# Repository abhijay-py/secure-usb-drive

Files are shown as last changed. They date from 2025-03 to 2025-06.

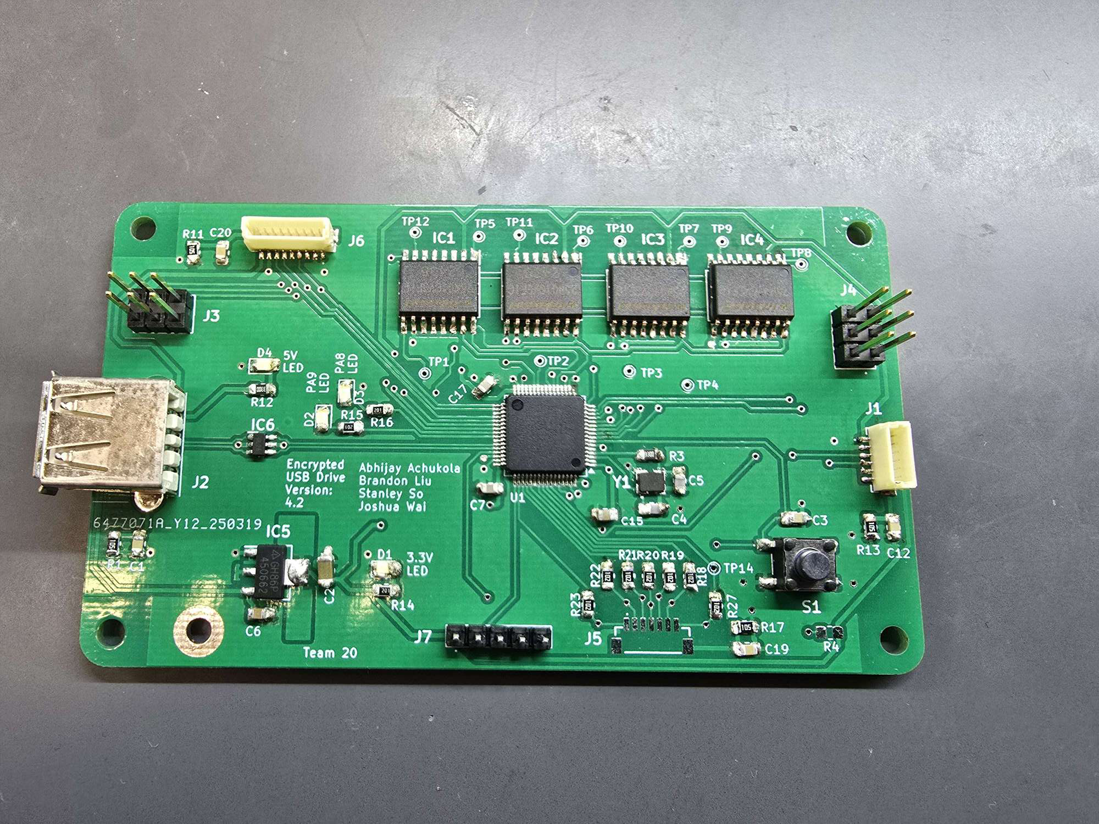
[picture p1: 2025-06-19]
Images/final_usb_pcb.jpg

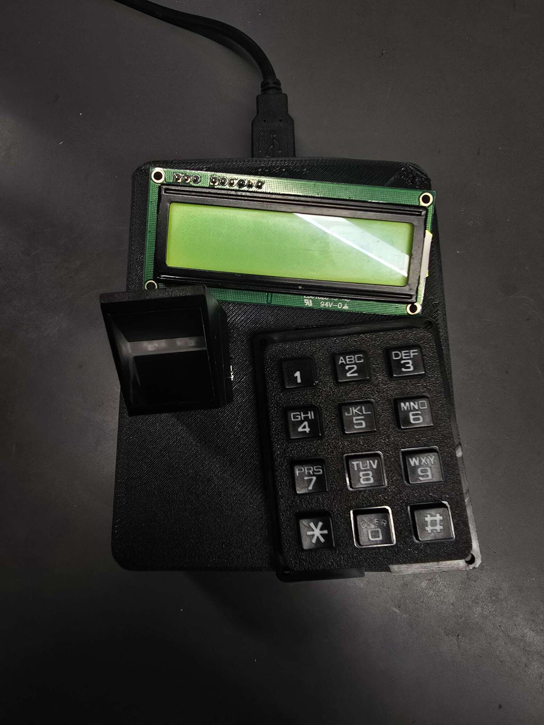
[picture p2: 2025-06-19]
Images/secure_usb_drive.jpg

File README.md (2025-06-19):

# secure-usb-drive
Our device has a fixed number of four users. When the user enters the correct password on the keypad or enters the correct fingerprint, they get to access the files corresponding to their user. <br>

Initially, all the users’ passwords are four zeros. When the user plugs in the USB drive, the LCD screen says, "Select User" and they must enter a number on the keypad to select the user (1 for user one, 2 for user two, 3 for user three, and 4 for user four). Then the LCD screen shows “Enter Passcode / Fingerprint” and the screen displays what the user types on the keypad. As the user types, their input is replaced with a dot. Once the user enters the correct passcode or inputs the correct fingerprint, the USB drive goes into the unlocked state where all the files for that user can be accessed. Each user gets their own designated flash chip. In the unlocked state, the user can press a button on the keypad to change the passcode or change the fingerprint and can press another button to lock the USB drive.<br>

The system is implemented using an STM32 microcontroller. It handles interfacing with the keypad, LCD screen, fingerprint sensor, four flash chips, and a host computer. It also handles keeping track of what state it’s in and handles keeping track of what user is accessing the flash drive. The system is powered through the 5V USB signal that is interfaced with the 5V USB-A female connector. According to the USB 2.0 specifications, it can handle an input voltage ranging from 4.75V to 5.25V. This input voltage directly powers the LCD screen. There is a low dropout regulator to step down the voltage to 3.3V to power the microcontroller, fingerprint sensor, and the flash chips.The system is enclosed in a 3D-printed rectangular case. Since the user must press down on the USB drive to enter a password, it can be connected to a computer using a cable instead of directly into a computer. <br>

All documentation, PCB, schematic, CAD, and software files can be found in their respective folders. <br>

The embedded code can be flashed onto the product by utilizing STM32CubeIDE and connecting an ST-Link and the five header pins on the PCB. The PCB is attached to the casing utilizing two screws on the inside and the casing is closed up with four screws. The connectors on the board will need to be attached to the LCD, fingerprint sensor, and keypad from the outside of the casing after feeding the connecting wires through the holes on the casing. <br><br>
Device Image <br><br>

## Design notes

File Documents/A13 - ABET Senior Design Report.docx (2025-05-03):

## Purdue ECE Senior Design Semester Report

## (Team Section)

Course Number and Title | ECE 47700 Digital Systems Senior Design Project
Semester / Year | Spring 2025
Advisors | Phil Walter
Team Number | 20
Project Title | Encrypted USB Drive

##### Senior Design Students – Team Composition

Name | Major | Area(s) of Expertise Utilized in Project | Expected Graduation Date
Brandon Liu | CompE | Software, PCB Design, Soldering, Wire Crimping | May 2025
Abhijay Achukola | CompE | Software, PCB Design, Soldering | May 2025
Joshua Wai | CompE | Mechanical, Software | May 2025
Stanley So | ElecE | Software, PCB Design, Soldering, Wire Crimping | December 2025

Project Description: Provide a brief (2-3 page) technical description of the design project, as outlined below:

(a) Provide a general description of the product to be delivered by this design project.

## The product has a fixed number of 4 users. When the user enters the correct password on the keypad or enters the correct fingerprint, they get to access the files corresponding to their user.

Initially, all the users’ passwords are four 0s. When the user plugs in the USB drive, the LCD screen says, "Select User" and they must enter a number on the keypad to select the user (1 for user 1, 2 for user 2, 3 for user 3, and 4 for user 4). Then the LCD screen shows “Enter Passcode / Fingerprint” and the screen displays what the user types on the keypad. As the user types, their input is replaced with a dot. Once the user enters the correct passcode or inputs the correct fingerprint, the USB drive goes into the unlocked state where all the files for that user can be accessed. Each user gets their own designated flash chip. In the unlocked state, the user can press a button on the keypad to change the passcode or change the fingerprint and can press another button to lock the USB drive.

## The system is implemented using an STM32 microcontroller. It handles interfacing with the keypad, LCD screen, fingerprint sensor, four flash chips, and a host computer. It also handles keeping track of what state it’s in and handles keeping track of what user is accessing the flash drive.

The system is powered through the 5V USB signal that is interfaced with the 5V USB-A female connector. According to the USB 2.0 specifications, it can handle an input voltage ranging from 4.75V to 5.25V. This input voltage directly powers the LCD screen. There is a low dropout regulator to step down the voltage to 3.3V to power the microcontroller, fingerprint sensor, and the flash chips.

## The system is enclosed in a 3D-printed rectangular case. Since the user must press down on the USB drive to enter a password, it can be connected to a computer using a cable instead of directly into a computer.

(b) What is the purpose of this product? For whom is it intended?

The purpose of this product is to have an encrypted USB drive that provides the end-user with the ability to store data secured by their fingerprint and password while keeping costs as low as possible; a great additional feature includes segmented memory such that different users using the same USB drive can only access certain files depending on their credentials via passwords, ID etc. The drive should provide an extra layer of security for access to user data. The intended audience for this product includes people who want to keep their data private. It can be bought by companies to be used by employees who want to transfer information via the drive, even if there is other sensitive data on there not yet erased, or even interest anyone involved in government or the military. The multiple users feature is great for companies that have workers on different shifts. These companies can buy one USB drive for different workers on different shifts to share, and that can save costs.

(c) Describe how the engineering design process used to create your product was utilized in this project. Include how you were able to develop and conduct appropriate experiments, analyze and interpret data, and use engineering judgment to draw conclusions related to the development of your product.

The main engineering design process used to create this product began with defining the problem and solution. The first task completed came up with a problem to be solved which ultimately led to the decision to develop an encrypted USB drive to solve the issue of data security. The next step was planning. This included looking at specifications of parts to meet goals and functionalities that the solution seeks to provide and then prototyping each part before making a PCB design and systematically integrating everything into one device (PCB connected to external components). There was lots of testing to debug issues not found in initial prototyping such as bridging the connection between USB host and flash memory.

(d) Describe the design constraints, and resulting specifications, incorporated into your product (list a minimum of 3).

## Constraint: at least 100kB/s speed for reading / writing files between the computer and the flash drive.

## Specification: A microcontroller with USB built in was selected and USB 2.0 high-speed was used.

## Constraint: at least 1Gb of memory for each user, and a total of four users.

## Specification: Our PCB has four 1Gb flash chips, all communicating over the same SPI bus. We used the CS pin to select which flash chip we’re using based on what user is selected.

## Constraint: We need to be able to communicate using one UART bus, two SPI buses, seven GPIO pins, and one USB bus. These will communicate with the fingerprint sensor, the four flash ICs, the LCD display, the keypad, and the host computer, respectively.

## Specification: We chose the STM32H7A3RGT6 microcontroller because it had enough peripherals and enough pins to handle all the communication.

Constraint: We need to power the microcontroller, fingerprint sensor, and flash ICs using 3.3V and be able to supply up to 500mA. Our device also needs to be powered by the USB 5V.
Specification: We chose the AZ1117IH-3.3TRG1 LDO, since that could supply 3.3V from 5V, and provide up to 1A of current.

(e) Describe how each of the following factors influenced your design specifications and constraints.

Public Health, Safety, and Welfare: One potential issue we considered was the risk associated with USB male-to-male connections and the possibility of electric shocks. However, the primary concern was the potential for users to accidentally damage the board due to static discharge from human contact. To mitigate this risk, we incorporated ESD diodes for the USB-A port, keypad, and fingerprint sensor. We also made a case out of insulating material to protect the electronics and user. Other than that, no significant risks were identified.

Global Factors: Global factors didn’t play a significant role in this project, as it wasn’t specifically designed for any particular global market or to address geopolitical issues. However, we did consider the general global trend toward increased data security and privacy concerns, especially with rising cyber threats. This influenced our decision to implement strong and secure authentication features, such as fingerprint recognition and password protection, ensuring that the product would meet global expectations for secure data storage. We were not able to include all the languages for our UI so the understanding of English would be necessary for users to use our product, but choosing English as the language is useful, as it is the most widely known language and can make it accessible for the most people.

Cultural Factors: Different cultures might also have varying preferences when it comes to things like the user interface, some might prefer simple, clean designs, while others may want more detailed instructions or support in multiple languages. With this in mind, we tried to make our design as simple and easy to use as possible. Unfortunately, we were not able to implement other languages other than English due to the LCD. However, as English is the most well-known language in the world, our product should have enough reach to be understood by most individuals. In areas with a higher risk of cyber threats, users might expect stronger security, like multi-factor authentication or biometric features, which is why we utilize two forms of authentication, password and fingerprint access.

Social Factors: This product would affect the social environment of corporations, allowing for easier collaboration and teamwork, with multiple people using the same drive. It’ll also allow for a more secure work environment with the data stored on the USB drives not being able to be stolen easily by malicious actors who also have access to it. This also prevents data being unintentionally shared with other unassuming users of USB drives.

Environmental Factors: We were under the assumption that the product will not be used in extreme heat or cold, and it will not be used in an external environment where there is precipitation, so we have the freedom to select any components that could operate at the normal temperature of our lab, and did not have to consider waterproofing. PCBs and LCDs require hazardous chemicals and a significant amount of energy to manufacture. They also require a significant amount of energy to recycle, because they need to be smelted to recover metals. Because of these reasons, we chose the smallest LCD that could display our UI, designed our PCB to be as small as possible, and chose the smallest keypad that had enough buttons to easily navigate our UI.

Economic Factors: The design in question aims not to be much more expensive compared to products already on the market. We did this by choosing the cheapest fingerprint sensor that could store 4 users, choosing the cheapest keypad that had enough buttons to navigate our UI, and choosing the cheapest LCD display that could display our UI. We also added a feature where four users could use one flash drive, so companies can buy one flash drive for four different employees, given that they won’t all be using it at the same time. This might happen if the company has employees on different shifts.

(f) Describe the appropriate engineering standards incorporated into the creation of your product.  The main standards used in this project are the communication protocols implemented to interface external components with the microcontroller including USB 2.0, SPI, and UART. Other followed conventions include using IEEE 1185 standard ESD protection for components that may interact with human input as well as other rules set for PCB design involving ERC and JLC PCB dimension constraints.
(g) Describe the final status of your product.

The product can transition between user select, receiving password, unlock, change fingerprint/pin, and locking states via the keypad input. While this functionality also works with the fingerprint sensor, it does not work the same within the packaging, making the functionality irrelevant in this context. The product can display the states transitioning and provide information upon what input to provide to the product to change states and access data using the LCD as a heads-up display (HUD). The product can interface with a host computer over USB and connect to the computer upon transition into the unlocked state and remove the device from the device list of the computer upon locking. In the unlocked state, the product can display the data stored in the flash IC corresponding to the user in the computer via USB.

(h) Describe the makeup of your project team and how you were organized to establish goals, plan tasks, and meet the objectives of this project.

Although each team member took similar ECE courses prior to the senior design course, there were new tasks that required learning and interest such as soldering, CAD (for casing), and PCB design. Joshua was interested in the mechanical tasks of the project, so he primarily did the CAD. Stanley, Brandon, and Abhijay each prototype approximately 1-2 external devices ie. LCD, fingerprint sensor, flash ICs, and keypad due to their experience in working with these devices. Although Stanley was the most experienced in PCB design, Abhijay took a keen interest in it and therefore was the main contributor to this task. Abhijay often helped set goals, by highlighting the major blockers of the project that needed to be addressed and helped organize meetings. He also got more people to work on the major issues being faced. Each team member worked on tasks based on skillset and interests. These tasks were then individually planned on how to approach them, with input from teammates and check-ins with other teammates to ensure everyone got their tasks done on a timely manner. Near deadlines, the whole team got together to work on the project and aid others in them to meet those deadlines. Around a week before every deadline, Abhijay announced the deadline to ensure that everyone knew and was ready for it.

(i) Did your project require the production of any written documentation other than this document (i.e., manuals, educational materials, etc.)? If so, describe the types, composition, and nature of the audiences for whom these materials were intended.

This project involved the production of several written documents other than this document, including engineering journals and design documents. The engineering journals include the thoughts, progress, and achievements of each team member’s individual work. The engineering journals were mostly for internal use within the team, and tracked each team member's progress, ideas, problems we ran into, and what we achieved throughout the project. These journals were more reflective, helping us keep track of individual contributions and decisions made, and improving communication within the team. The audience for these journals was mainly team members and our teaching assistants and faculty advisors. We were instructed to document our progress in such a way that someone could easily follow along and understand our steps. The design documents include the planning of the various systems of the project including software and hardware, as well as analysis on the comparison between design components. These documents were intended for a wider audience, including our team and external reviewers like faculty advisors or professionals in the field. These documents went over the planning, technical specs, and design choices for both the hardware and software aspects of the project. They were more formal and technical, aiming for clarity so that anyone reading them, whether they were familiar with the project or not, could follow the reasoning behind our design decisions.

(j) Describe the types, composition, and nature of the audiences in attendance for the final oral design review. Discuss how you prepared for this audience.

In the final oral design review, the main audience are student peers and the instructional staff. The student peers are likely interested in seeing the functionality of the design and the process involved since they never conducted weekly check-ins to see the progress of this project throughout the semester. The instructional staff may pose more sophisticated questions as they were involved in seeing how the project progressed over time. To prepare for both audiences, it was key to reflect on the responsibility and achievement of each team member as this is what we will be presenting in addition to the demonstration of the project design.

## Purdue ECE Senior Design Semester Report

## (Individual Reflections Section)

Course Number and Title | ECE 47700 Digital Systems Senior Design Project
Semester / Year | Spring 2025
Advisors | Phil Walter
Team Number | 20
Project Title | Encrypted USB Drive

##### Senior Design Student Completing This Section

Name | Major | Area(s) of Expertise Utilized in Project | Expected Graduation Date
Brandon Liu | Computer Engineering | Software, PCB Design, Soldering, Wire Crimping | May 2025

Individual Reflection: Provide a brief (1-2 page) individual reflection of the design project, as outlined below:

(a) Describe your personal contributions to the project.

In software, my main contributions include prototyping the LCD, prototyping read JEDEC ID for the flash IC, setting up USB interface between host computer and the microcontroller, and storing user ID and password credentials in the MCU flash using C programming on the STM32CubeIDE. For PCB design related tasks, my contributions include routing the PCB layout and adding ESD protection to both the schematic and the PCB layout. I’ve also crimped wires & soldered wires together to establish connections between external components and the PCB which has a bunch of components that I soldered on including but not limited to the MCU, flash ICs, connectors, diodes etc.

(b) Describe how your contributions to this project built on the knowledge and skills you acquired in earlier course work.

During my work in prototyping the LCD using SPI, one command of the flash IC using SPI, USB interface setup, and storing user ID and password credentials in the MCU flash using the C programming language, my skills in accomplishing these tasks can be derived from ECE 36200 and ECE 43700. In ECE 36200, I learned to work with GPIOs, communicate with external devices using SPI and UART, configure interrupts, and more importantly, read datasheets for things I’m not familiar with which is what I did when working with a different type of LCD than one used in ECE 36200 and prototyping USB. In ECE 43700, I learned the concept of storing both program instructions and data in memory and reference them via addressing which helped me figure out how to best store user ID and password credentials.

(c) Describe how you acquired and applied new knowledge as needed to contribute to this project. What learning strategies did you employ to do so?

Prior to soldering the microcontroller, flash chips, resistors, diodes, capacitors, connectors, and wires, I only had experience soldering wires. I have never done anything with other kinds of components before, so I knew that I had to learn from people who have accomplished these tasks already. Luckily, the ECE 47700 course staff provided a workshop for how to solder, so after attending the workshop, I was able to solder the components listed above. As for routing the PCB and adding components to the layout, I have never really worked with KiCad before, and since this skill was to be self-learned, I watched YouTube tutorials that guided me step by step on the same KiCad version that I was using. After watching the videos, I was able to route the wires between the connectors and the microcontroller in one of the revisions, and learn how to add ESD circuitry by first adding them to the schematic file and then automatically update their presence in the PCB file which I later had to route as well.

(d) Discuss your ethical and professional responsibilities as they relate to this engineering design experience.

My ethical responsibilities involve being honest about my progress and what I am struggling with. It is important that other team members know what I have worked on and what I have not completed yet, so they have full transparency on other aspects of the project that they are not working on. My professional responsibilities primarily consist of following conventions for updating parts of a project shared and accessed by multiple members including but not limited to version control.

(e) Consider what the impact of the product of this engineering design experience could have in economic, environmental, societal, and global contexts. Discuss how you would make (or did make) an informed judgement as to your product’s impact in each of these four contexts?

Regarding the societal and global contexts, I would consider mainly privacy, data protection, and spy / intelligence networks run by government / military institutions. It can be determined that the secure USB drive has a huge impact in these areas because it prevents any user from simply plugging in the drive into their computer and accessing the data. There is a layer of authentication that must be breached in order to unlock access to the USB. This protects users in case they leave their drive lying around as well as people conducting military operations around the world because there is impedance to the data access. For the product’s impact in the environmental context, I would only think about what the product uses or releases, and since it does not release any substances to the environment, I would determine that the only environmental impact is electricity usage. As for economic impact, I would judge the product’s impact in this category by viewing its competitiveness against other products. I can determine that this product has one by being a competing product in the marketplace if and only if the product was smaller in size, had stronger wire connections, and provided more storage space. This is because most flash drives can store many gigabytes of data, while the current engineering design can only store a single gigabit per user, which is not ideal. In addition, the size of the design is bulky due to the requirement of holding a keypad, fingerprint sensor, and an LCD. If the design along with these external components were smaller, it would be more portable and competitive in the market. Otherwise, despite the potential to encrypt data and the ability to require authentication before accessing data, the product is on the lower end of meeting consumer needs and will therefore have difficulty in maintaining its standing in the USB drive market.

## Purdue ECE Senior Design Semester Report

## (Individual Reflections Section)

Course Number and Title | ECE 47700 Digital Systems Senior Design Project
Semester / Year | Spring 2025
Advisors | Phil Walter
Team Number | 20
Project Title | Encrypted USB Drive

##### Senior Design Student Completing This Section

Name | Major | Area(s) of Expertise Utilized in Project | Expected Graduation Date
Stanley So | Electrical Engineering | Software, PCB Design, Soldering, Wire Crimping | December 2025

Individual Reflection: Provide a brief (1-2 page) individual reflection of the design project, as outlined below:

(a) Describe your personal contributions to the project.

I wrote the code for the keypad by using a timer interrupt to poll each row using GPIO. I interfaced with the fingerprint sensor using UART. I made adjustments to the PCB design. I ordered all the parts for the project (PCB, on-board components, and off-board connectors). I soldered some of the components to the board, including the heartbeat LEDs, the female USB-A connector, the LDO, the reset switch, and various resistors and capacitors. I taught myself how to crimp wires, and I taught my teammates how to do the same thing. I turned Brandon’s state machine pseudocode into production code.

(b) Describe how your contributions to this project built on the knowledge and skills you acquired in earlier course work.

ECE 362 taught me how most of the protocols used in this project worked (SPI, UART). Because of this, I knew what connections to make, what pins to debug with an oscilloscope, and how to translate the raw oscilloscope input into digital data. ECE 2k7 and 2k8 taught me how to use special oscilloscope functions (trigger, different horizontal modes), which helped in finding the data that I actually wanted to read. ECE 264 helped familiarize me with C syntax and how to use a debugger. This made writing code really fast and debugging a lot easier, since I could step through any individual instructions and see how the variables changed as I stepped through.

(c) Describe how you acquired and applied new knowledge as needed to contribute to this project. What learning strategies did you employ to do so?

My PCB design experience comes from a personal project where I made programmable diabolo (juggling prop) lights. I had to design a PCB in EasyEDA in order to make it structurally sound enough to be put on a spinning diabolo. This PCB design experience helped me make component placement and routing changes to the PCB very quickly. My soldering experience came from another personal project where I designed a drone, so I had to solder a lot of components together using wires. This made soldering together the two ends of the connector wires quick. Since we had to solder components onto a PCB for this project, I also had to watch YouTube videos on how to solder surface mount components. This allowed us to come up with a two-person system to solder components quickly, where one person managed the soldering iron and the solder, and another person managed the tweezers to put the component in place. I learned how to crimp terminals after watching YouTube videos for this project. This made it so then I knew what parts to order (both housing and crimp terminal), I knew how to make some connectors, and I knew how to teach Brandon how to also make connectors. I also learned how to use the oscilloscope to read serial data by watching YouTube videos. This made debugging UART data from the fingerprint sensor so much faster, since I didn’t have to manually decode the oscilloscope reading into digital data myself.

(d) Discuss your ethical and professional responsibilities as they relate to this engineering design experience.

Whenever I saw that something needed to be done, I would jump in and take care of it (everything in part A was something I volunteered to help for). At the very least, I always tried my best to be there when someone else was working. There are some unlogged hours missing from my journal where I’m just there for mental support, and ready to help with any small tasks that I could (they’re missing from my journal because I don’t know how to log those hours without points being deducted for not describing enough). I always tried my best to communicate with my teammates on Discord (about progress and also about my schedule), and I made sure I received all notifications from that Discord server so I could constantly be aware of what needed to be done.

My ethical responsibilities included being honest and transparent about my work progress and my availability. This let my teammates know what needed to be done. I also followed all the lab rules, including not taking anything from anybody else’s lab station, and always having at least 2 people in the lab. Taking something from someone else’s lab station can lead to confusion, and in the worst case component damage, and having at least 2 people in lab meant that there was always someone else there if somebody got hurt.

(e) Consider what the impact of the product of this engineering design experience could have in economic, environmental, societal, and global contexts. Discuss how you would make (or did make) an informed judgement as to your product’s impact in each of these four contexts?

(If we polished our product more), some societal and global impacts this product might have are that this might be used by companies to protect their data, leading to more secure data storage since you have to physically get your hands on it to break into it. This might also be used by criminals to hide their data and communicate, like how mass criminal networks have used encrypted phones, but this is much less of a concern than encrypted phones because it has no internet access. If we added internet access, our project would become another encrypted phone, leading to really big ethical concerns regarding criminals using it. Like many electronic products, this product has environmental impacts on both the manufacturing and disposal stage. Every single component (PCB, ICs, LCD display) uses hazardous chemicals in the manufacturing process, along with a lot of energy. During the disposal stage, you have to smelt the electronics to get the metals back, which is more energy usage. To account for this, we made the PCB as small as possible and chose the smallest possible components that met our requirements. In terms of economic impact, we might be able to sell this to a lot of big companies that want to secure their data. Our project is probably not lower priced than the other secure USB drives out there, and it’s definitely not as small as other competitors. However, our project has a UI and a fingerprint sensor, which provides new users with an easier learning curve, and makes our product more convenient to unlock. Thus, our main selling point is that our project provides a more convenient alternative to existing competitors.

## Purdue ECE Senior Design Semester Report

## (Individual Reflections Section)

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

##### Senior Design Student Completing This Section

Name | Major | Area(s) of Expertise Utilized in Project | Expected Graduation Date
Abhijay Achukola | CMPE | Software, PCB Design, Soldering | May 2025

Individual Reflection: Provide a brief (1-2 page) individual reflection of the design project, as outlined below:

(a) Describe your personal contributions to the project.

I researched which flash IC to utilize, read through the data sheet, and implemented software interfacing with the flash IC from the microcontroller over SPI. I also designed most of the PCB Design and kept the schematic up to date with our updates prior to starting the PCB design. I also helped solder all the parts onto the PCB, helping place parts in place.

(b) Describe how your contributions to this project are built on the knowledge and skills you acquired in earlier coursework.

I was able to utilize the datasheet reading knowledge I gained from prior classes like ECE 20001 to read through datasheets for the flash IC and microcontroller to properly interface them and connect them to the rest of the system properly. It also helped me find the proper way to wire the microcontroller to our PCB and the supporting circuitry from those datasheets. I also was able to utilize the KiCAD and stm32 microcontroller interfacing knowledge from ECE 36200 to create our electrical schematic and properly program the microcontroller to interface with the flash IC.

(c) Describe how you acquired and applied new knowledge as needed to contribute to this project. What learning strategies did you employ to do so?

I acquired the knowledge of how to utilize stm32cube and interfacing with flash ICs by reading through forums and online datasheets on how to utilize it. I also learned more about these topics by trying to apply immediately in the project and then going back to the resources I utilized. I also learned how to design PCBs by listening to senior design lectures and watching videos online. Furthermore, I watched videos to expand my knowledge on how to solder SMD components properly and developed a system with my teammates to effectively solder them quickly. The learning strategies I utilized was to immediately apply the skills the resources I read to check if I fully understand the concepts.

(d) Discuss your ethical and professional responsibilities as they relate to this engineering design experience.

I was in charge with keeping the team organized and ensuring that everyone knew which priorities had to be handled. I also ensured that we met together and ensured that the design process went smoothly, to avoid any malfunctions due to miscommunication. Ethically, I ensured that everyone documented their work, cited their sources, and ensured that I was transparent on my struggles and areas where I needed help.

(e) Consider what the impact of the product of this engineering design experience could have in economic, environmental, societal, and global contexts. Discuss how you would make (or did make) an informed judgement as to your product’s impact in each of these four contexts?

Some economic impacts that this product would have include shaking up the market for storage devices by being able to sell this product to a lot of big companies that want to secure their data. This product might not be as cheap as many other USB drives but should be reasonably priced for hard drives in general, and the higher cost can be justified for the security it provides. Viewing this product with an environmental lens, this product would reduce the e-waste produced using massive number of USB drives as it condenses four users of four separate USB drives into all using our single product. The e-waste produced by electronics has major impact, as electronic components and PCBs utilize harmful chemicals to manufacture each time, so less devices being disposed of results in reduced harm to the environment. This product will have an impact on the social environments of corporations, which also would propagate this impact globally, allowing for easier collaboration and teamwork, with multiple people using the same drive. It’ll also allow for a more secure work environment with the data stored on the USB drives not being able to be stolen easily by malicious actors who also have access to it.

## Purdue ECE Senior Design Semester Report

## (Individual Reflections Section)

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

##### Senior Design Student Completing This Section

Name | Major | Area(s) of Expertise Utilized in Project | Expected Graduation Date
Josh Wai | CompE | Mechanical | May 2025

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

(a) Describe your personal contributions to the project.

I designed the mechanical casing using CAD software to fit the project’s electronics and 3D printed the parts. After receiving feedback from professors, TAs, and teammates, I made adjustments to improve the fit, add space for connectors, and reinforce key areas. I also helped with the assembly, tinning, crimping, cutting, and soldering wires to connect the components to the board. When the fingerprint sensor wasn’t cooperating, I troubleshot the issue by testing connections and making adjustments to get it working. Additionally, I updated the LCD UI by adding text prompts to improve the user experience.

(b) Describe how your contributions to this project built on the knowledge and skills you acquired in earlier course work.

I built on the skills I gained from the 2K7 and 362 labs, where I learned the fundamentals of CAD design, electrical component assembly, and basic troubleshooting techniques. In the 362 lab, I learned about wiring, soldering, and circuit board assembly, which were crucial when working on the connections between the components. Building on these experiences, I was able to improve my understanding of integrating various components into a cohesive system, like when I had to troubleshoot the fingerprint sensor issue. I also applied what I learned about creating user interfaces in embedded systems when I updated the LCD UI with text prompts. This project gave me the chance to take those foundational skills and apply them to a real-world scenario, improving both my technical abilities and my problem-solving approach.

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

I had to learn how to use Onshape, the CAD software, from scratch, as it was my first time working with this tool. To get up to speed, I relied heavily on YouTube tutorials and online resources. I followed step-by-step guides, which helped me understand the interface and key features of Onshape. I focused on learning the basics first—like how to create sketches, extrude parts, and set up assemblies—before moving on to more advanced topics like constraints and part interactions. I also applied a hands-on approach by actively working on the CAD design for the project while referring back to the tutorials whenever I hit a roadblock. This approach of learning by doing was incredibly helpful, as it allowed me to see immediate results from my efforts and helped reinforce what I was learning. I wasn’t afraid to experiment within the software, and if something didn’t work, I’d troubleshoot the issue by watching more targeted videos or exploring community forums for solutions. This active problem-solving mindset, combined with iterative learning, made it easier to adapt to the software and apply it effectively for our project. Through this process, I gained a solid understanding of Onshape, which directly contributed to the successful design of the mechanical casing.

(d) Discuss your ethical and professional responsibilities as they relate to this engineering design experience.

Throughout this project, I made it a priority to be transparent about any problems that arose, recognizing that honesty and clear communication are key to maintaining trust and ensuring the team could effectively address issues as they emerged. Whenever we encountered challenges—whether it was with the mechanical casing design, component connections, or troubleshooting technical problems—I made sure to bring these issues to the attention of the team right away.

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

The encrypted USB drive with user-specific memory banks has broad impacts across economic, environmental, societal, and global contexts. Economically, it meets the demand for secure data storage, offering opportunities for businesses needing high data protection. Societally, it provides affordable data security for individuals and organizations, addressing privacy concerns. Globally, it complies with international data security standards, ensuring relevance in regions facing growing cyber threats.

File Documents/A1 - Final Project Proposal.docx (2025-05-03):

# Final Project Proposal

# Year: 2025 Semester: Spring Team: 20 Project: Encrypted USB Drive

# Creation Date: 1/15/2025 Last Modified: 1/18/2025

# Team Members (#1 is Team Leader):

# Member 1: Abhijay Achukola Email: aachukol@purdue.edu

# Member 2: Brandon Liu Email: liu3394@purdue.edu

# Member 3: Stanley So Email: sos@purdue.edu

# Member 4: Joshua Wai Email: waij@purdue.edu

# 1.0 Project Functional Description:

# We plan to make an encrypted thumb drive. There will be a fixed number of 4 users. There will be an onboard LCD screen, a keypad, and a fingerprint sensor.

Initially on hardware reset, all the users’ passwords are 4 0s. When we plug in the thumb drive, the LCD screen will say "Select User" and we have to enter a number on the keypad to select the user (1 for user 1, 2 for user 2, 3 for user 3, and 4 for user 4). Then the LCD screen will show “Enter Passcode” and the screen will display what the user types on the keypad. The keypad input the LCD screen displays will be replaced with a dot as the numbers get typed. Once the user enters the correct passcode or inputs the correct fingerprint, the thumb drive will go into the unlocked state where all the files for that user can be accessed. In the unlocked state, the user can press a button to change the passcode or change the fingerprint. To lock the thumb drive, you unplug it from the computer. If the user enters the wrong password on the keypad 5 or more times, then the data for that user is erased and the password gets reset to all 0s.

# 2.0 Team Member Expertise and Team Roles and Responsibilities:

# 2.1 Team Member Expertise:

# 2.1.1 Team Member: Abhijay Achukola: Embedded Circuit Design, C Programming, SystemVerilog, Leadership, Soldering.

# 2.1.2 Team Member: Brandon Liu: Python and C Programming (HPE, Garmin), theory of operation & functional design (ECE 362, ECE 337, Garmin)

# 2.1.3 Team Member: Stanley So: SystemVerilog and Embedded C Programming

# 2.1.4 Team Member: Joshua Wai: Python and C programming

# 2.2 Team Roles and Responsibilities:

Role | Team Member
Team Lead | Abhijay Achukola
Systems Lead | Brandon Liu
Hardware Lead | Stanley So
Software Lead | Joshua Wai

# 3.0 Homework Assignment Responsibilities

Design Component Report | | Professional Component Report
A3-Software Overview | Joshua Wai | A9-Legal Analysis | Joshua Wai
A4-Electrical Overview | Stanley So | A10-Reliability and Safety Analysis | Brandon Liu
A6-Mechanical Overview | Abhijay Achukola | A11-Ethical/Environmental Analysis | Stanley So
A8-Software Formalization | Brandon Liu | A12-User Manual | Abhijay Achukola

# 4.0 Estimated Budget

# Total - $100

# PCB – $20

# Sensors/Input - $5

# Display - $10

# ICs - $45

# Microcontroller - $10

# Enclosure - $10

# 5.0 Project Specific Design Requirements

# Hardware PSDR:

# Keypad for password and ID settings

# LCD display user input

# Flash memory for data storage

# Software PSDR:

# ID verification (both password & fingerprint)

# Allocation of memory based on credentials

# Password display management

# 6.0 Sources Cited:

ECE 477: Digital Systems Senior Design Last Modified: 01-18-2025

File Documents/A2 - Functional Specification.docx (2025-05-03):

# Functional Specification

# Year: 2025 Semester: Spring Team: 20 Project: Encrypted USB Drive

# Creation Date: January 25, 2025 Last Modified: January 25, 2025

# Member 1: Abhijay Achukola Email: aachukol@purdue.edu

# Member 2: Brandon Liu Email: liu3394@purdue.edu

# Member 3: Stanley So Email: sos@purdue.edu

# Member 4: Joshua Wai Email: waij@purdue.edu

# Assignment Evaluation: See Rubric on Brightspace Assignment

# 1.0 Functional Description

Encrypted USB Drive is a USB drive with multiple security features that allows different individuals to access separate files from the same device, without allowing others from viewing those files as well. The device is composed of a display that informs the user on how they can select which user they’re trying to log in as, whether log in attempts is successful, and whether the device is unlocked or locked. The user can input either their password or use their fingerprint to gain access to their data, at which point the device can be utilized as a standard USB drive and allows the user to also change their password or fingerprint attached to their profile. These features are also available to up to four separate users.

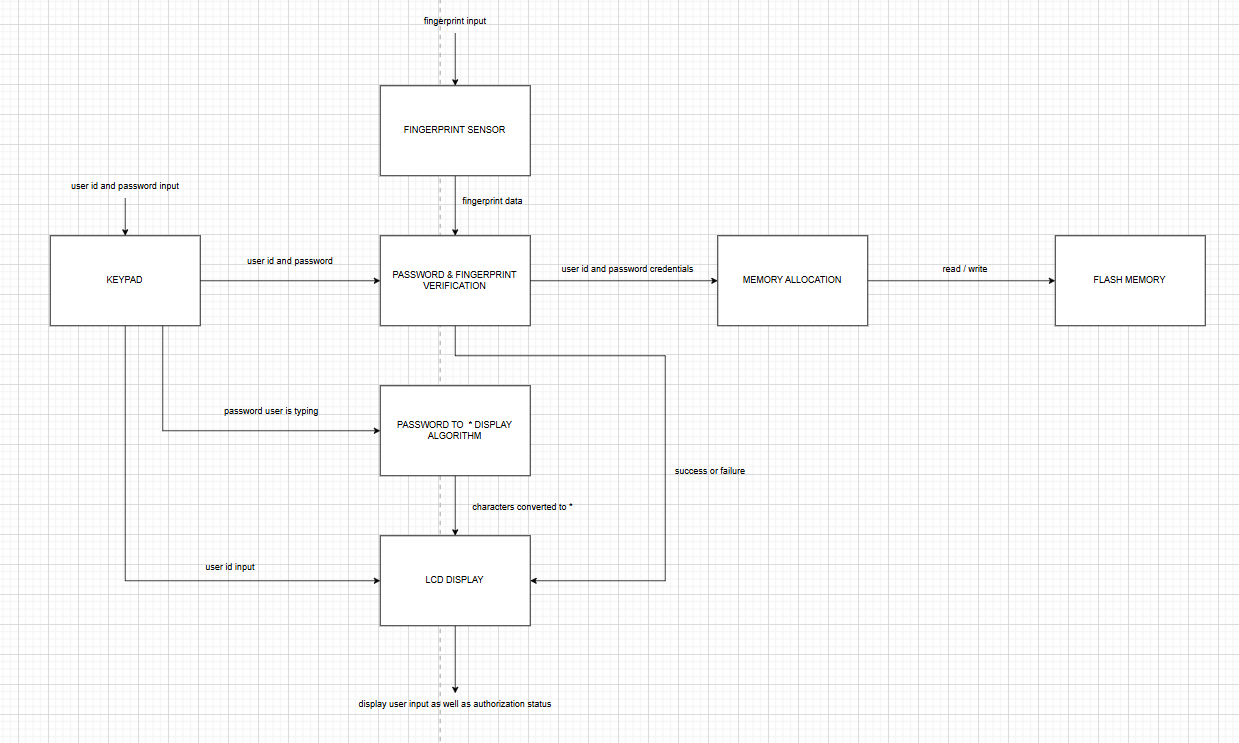
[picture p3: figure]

# 2.0 Theory of Operation

Our fingerprint sensor will go through a lot of states. At the moment, we are thinking about the following states: Startup, User Select, Receiving Password, Unlocked, Change PIN, Change Fingerprint, and Locking. A state transition diagram helps to organize all of these states. It shows each state inside an oval and shows how you can transition between each state with a labeled arrow. The state transition diagram for our device is shown below.

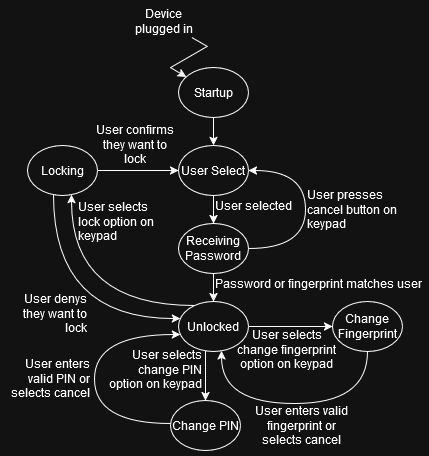
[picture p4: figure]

In the startup state, the GPIO pins are configured to whatever communication protocol they need to do. In the User Select state, the LCD display displays “Select User” and the device waits for the user to press a number on the keypad from 1-4. In the Receiving Password state, The LCD screen will show “Enter Password” and the screen will display what the user types on the keypad. The keypad input the LCD screen displays will be replaced with a dot as the numbers get typed. In the unlocked state, all the files for that user can be accessed.

# 3.0 Expected Usage Case

Our encrypted USB drive is expected to be used as a portable and secure storage device for up to 4 users per device in a preferably dry, indoor environment. It is expected that the user will have a basic level of technical literacy capable of using USB drives, managing passwords, and performing simple file operations. The device is deigned to be used mostly by IT professionals, military or government personnel, business corporations, healthcare institutes, legal professionals, and educational institutes to protect their sensitive data and intellectual property.

# 4.0 Design Constraints

# 4.1 Computational Constraints

To start off, the computational constraints will use a linear scan algorithm to check user id against all known records and then comparing passwords. Additionally, the goal is to have at least 100kB/s speed for reading / writing files between the computer and the flash drive. The microcontroller should be able to allow each user should have at least 4Gb of memory via allocation (no partitioning). However, the fingerprint sensor takes care of storing fingerprints and comparing fingerprints already so the microcontroller doesn’t have to do that.

# 4.2 Electronics Constraints

Our thumb drive will use an STM32 microcontroller to interface with a fingerprint sensor, LCD display, keypad, USB-A host, and flash memory. The fingerprint sensor will communicate using UART. The LCD display will communicate using SPI or I2C. We will interface with the keypad by polling each row and checking the corresponding column. The USB communication will be handled by the onboard peripheral inside the microcontroller itself. The flash memory will communicate using SPI. There will be a 5V to 3.3V regulator to provide power to the microcontroller and whatever peripherals need it. There will also be a crystal to make sure the USB data is transmitted at the correct frequency. There will also be a mosfet so we can turn off power to the fingerprint sensor with a GPIO pin when it’s not needed.

# 4.3 Thermal/Power Constraints

The input voltage from the USB should be between 4.75V and 5.25V. The device should draw less than 500mA from the USB. The maximum operating temperature should be at least 110 degrees Fahrenheit. The minimum operating temperature should be at most 32 degrees Fahrenheit. The device is powered by the USB so there is no battery.

# 4.4 Mechanical Constraints

Our device is intended to be preferably used in a dry, indoor environment where the temperature is room temperature. It should also be able to work outdoors provided the weather is not too extreme and not too wet. We also want to ensure that keypad & fingerprint components do not physically impede the device’s ability to connect to a laptop / computer via USB port. We aim to make the final product pocket-size for portability as well as ensuring the weight stays below one pound. The device will also include a casing to protect our electronics from dust, debris, and spillage. While we do not aim for total waterproofing, we hope to at least prevent simple drops of water from messing up the device through casing.

# 4.5 Economic Constraints

# Maximum budget for the product is $425 without accounting for the inflation rate. However, with the encryption functionality and market analysis, a competitive price shall not exceed $150. Given the market rate, it should cost around $70-$100.

# 4.6 Other Constraints

# 5.0 Sources Cited:

PBW – 23-Jan-2023 Page 2 of 3

ECE 47700: Digital Systems Senior Design Last Modified:

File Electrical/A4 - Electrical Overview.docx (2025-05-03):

# Electrical Overview

# Year: 2025 Semester: Spring Team: 20 Project: Encrypted USB Drive

# Creation Date: 2/8/25 Last Modified: March 7, 2025

# Author: Stanley So Email: sos@purdue.edu

# 1.0 Electrical Overview

The main processing unit will be the 32-bit STM32 microcontroller. This microcontroller will manage communication with a fingerprint sensor, keypad, LCD display, 4 flash chips, and a host computer. The microcontroller will communicate with the fingerprint sensor using UART. The fingerprint sensor does all the fingerprint storage and verification, so the microcontroller only needs to send commands to the fingerprint sensor to save and verify fingerprints. The microcontroller will communicate with the keypad using GPIO. The microcontroller will use a timer to poll each keypad row and read the keypad columns. The microcontroller will communicate with the LCD display using SPI. The LCD display will be used to convey the specific mode the user is in (see the website homepage for the state transition diagram). The microcontroller will communicate with the flash chips using SPI. Each flash chip will store a specific user’s data. We plan to use only one SPI bus to communicate with all 4 of these chips and just use the chip select line to determine which flash chip we’re communicating with. The microcontroller will communicate with the host computer using USB.

# 2.0 Electrical Considerations

# Operating Frequencies

# We plan to use USB full-speed, which is 12Mbps. Thus, we need to select a crystal that is at least 12MHz. We will use a 48MHz crystal as the clock for our microcontroller since that’s within the 4-50MHz specification for our microcontroller, and we used that frequency in ECE 362 and it worked.

# We will poll the keypad at 1kHz because that’s what we did in ECE 362 and it worked.

# Operating Voltage Level

We will input 5V from the USB connector, but we will pass it through a voltage regulator and use 3.3V to power everything. That includes the microcontroller, fingerprint sensor, LCD display, and flash chips. The device should work with an input voltage anywhere between 4.75V to 5.25V since that’s what the USB spec allows.

# Power Consumption Calculation

Component | Function | Qty | Avg Current (mA) | Power at 3.3V (mW) | Datasheet References
STM32H7A3RGTx | MCU | 1 | 40 | 132 | [2]
Adafruit 419 | Keypad | 1 | 2 | 6.6 | [4]
MT29F4G01ABAFDWB | Flash | 4 | 40 | 132 | [5]
SEH1602-A | LCD Display | 1 | 31 | 102 | [1]
GROW R502-A | Fingerprint Sensor | 1 | 20 | 66 | [3]

# Total current: 233mA

# Total power (at 5V): 1.2W

# Our voltage regulator can support up to 1A of current draw so we’re good. [6]

# 3.0 Interface Considerations

Device | Serial Interface | Data Rate
Fingerprint Sensor | UART | 19200 bps
Host Computer | USB | 12 Mbps
Keypad | STM32’s timer | 1 kHz
Flash | SPI | 24 Mbps
LCD Display | SPI | 500 Kbps

# 4.0 Sources Cited:

# [1]“Dot matrix OLED display module Manual 1602A -OLED.” Accessed: Feb. 09, 2025. [Online]. Available: https://www.technologicalarts.ca/support/docs/Components/OLED1602A/SOC1602A.pdf

# [2]STMicroelectronics, “Features Includes ST state-of-the-art patented technology Core • 32-bit Arm ® Cortex ® -M7 core with double-precision FPU and L1 cache,” May 2022. Accessed: Feb. 09, 2025. [Online]. Available: https://engineering.purdue.edu/477grp20/Files/refs/stm32h7a3ai.pdf

# [3]Hangzhou Grow Technology, “R502-A Fingerprint Module,” Sep. 2023. Accessed: Feb. 09, 2025. [Online]. Available: https://engineering.purdue.edu/477grp20/Files/refs/R502-A%20fingerprint%20module%20user%20manual-V1.3.1.pdf

# [4]Adafruit, “Membrane 3x4 Matrix Keypad + extras -3x4,” Sep. 2022. Accessed: Feb. 09, 2025. [Online]. Available: https://mm.digikey.com/Volume0/opasdata/d220001/medias/docus/1267/419_Web.pdf

# [5]Micron, “Universal Page,” https://twitter.com/MicronTech, 2023. https://www.micron.com/content/dam/micron/global/secure/products/data-sheet/nand-flash/70-series/m70a-4gb-3v-nand-spi.pdf (accessed Feb. 09, 2025).

# [6] Diodes Incorporated, “Az1117i,” Diodes Incorporated, https://www.diodes.com/assets/Datasheets/AZ1117I.pdf (accessed Feb. 9, 2025).

# Appendix 1: System Block Diagram

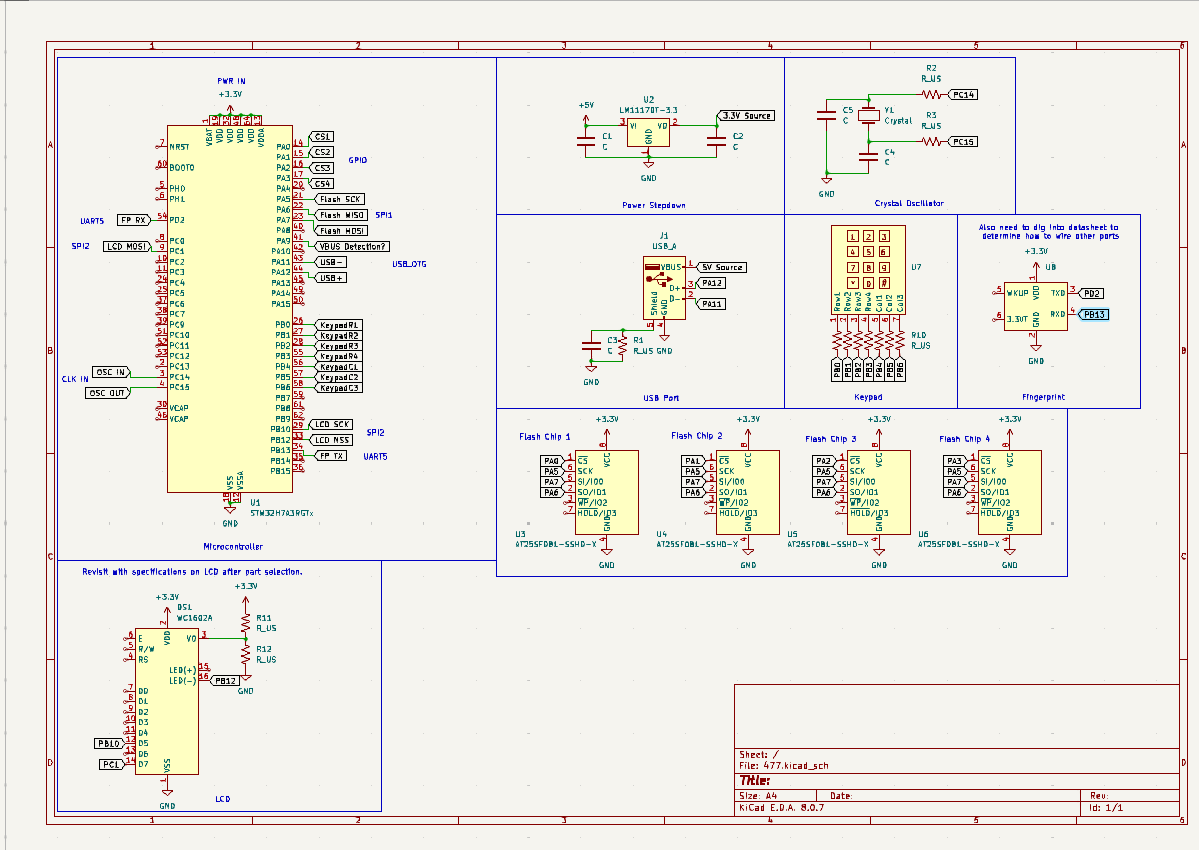
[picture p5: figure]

ECE 47700: Digital Systems Senior Design Last Modified: 02-08-2025

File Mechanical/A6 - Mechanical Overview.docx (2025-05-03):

# Mechanical Overview

# Year: 2025 Semester: Spring Team: 20 Project: Encrypted USB Drive

# Creation Date: 2/15/2025 Last Modified: February 15, 2025

# Author: Abhijay Achukola Email: aachukol@purdue.edu

# Assignment Evaluation: See Rubric on Brightspace Assignment

# 1.1 Commercial Product Packaging

# 1.2 Product #1

The DataLocker Sentry K350 16GB Encrypted USB Flash Drive Keypad is like our project and is packaged in a metal enclosure that is a bit more hefty than other USB drives. Its case has holes at the top with spaces for the individual keys to allow it to be pressed, and a space for the screen to display the current state of the device. The case also contains a cap of sorts to cover the USB-A male connector.

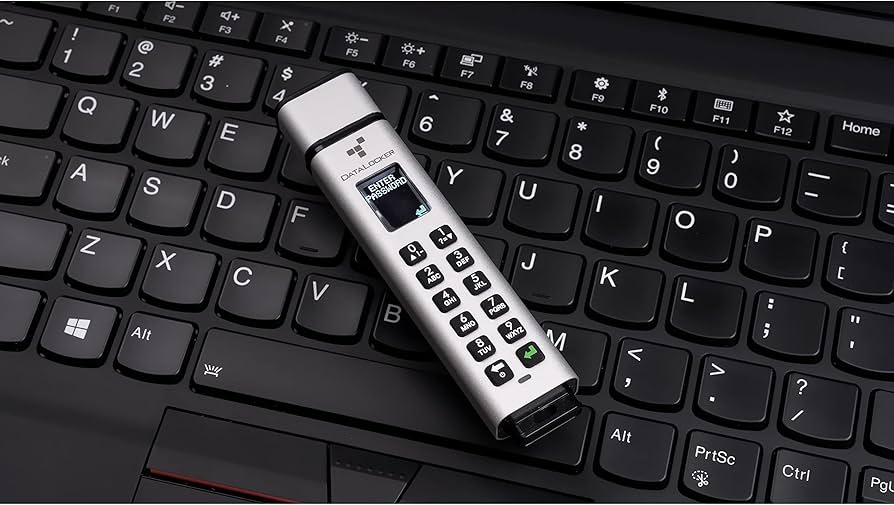
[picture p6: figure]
DataLocker Sentry K350 16GB Encrypted USB Flash Drive Keypad, Easy Screen Guided Setup AES 256, TAA Compliant Ruggedized Mil-Std 810-G, IP68 OS ...

Our design will utilize some of the features from this device, while still removing some others. Utilizing the method of exposing the keys and display is what we’ll have in our device too, but instead of exposing individual keys, we’ll expose the entire matrix of keys, as the keys are fairly flat to the bottom of the keypad, so its better to expose every part of the part instead of making it harder for its users to click on the keys. We’ll use a female USB-A connector to prevent any issues of the male USB-A connector breaking under the weight of the device and provide a wire to connect it to devices. We’ll also utilize a plastic 3D printed enclosure for a more lightweight solution that is also easier to design and tweak.

# 1.3 Product #2

The 3-in-1 Fingerprint Encrypted USB 3.0 Drive – 64GB to 512GB Options is like our project and is packaged in a metal enclosure that is a bit more hefty than other USB drives and uses three male connectors instead of the standard one. Its case has one hole at the top with a bit of an indent for the fingerprint sensor, as well as three holes on the side, one for each connector. The casing is a bit weird shape, in a triangle/hexagonal like structure, possibly to minimize materials used and optimize use of all three connectors.

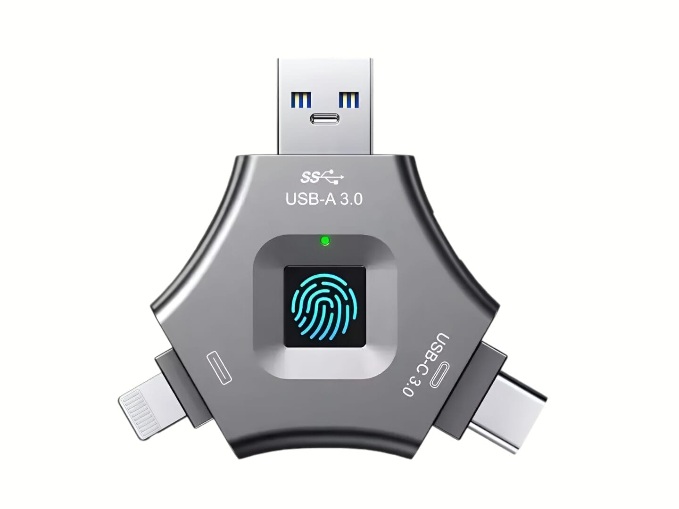
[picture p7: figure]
Fingerprint USB Drive | Wholesale Solutions

Our design will utilize some of the features from this device, while still removing some others. Utilizing the method of exposing the fingerprint is what we’ll have in our device too, but instead of exposing just the fingerprint surface, we’ll expose most of the surface to erase the need for the divot in the device. We’ll still use a single female USB-A connector and will instead use a rectangular packaging as there is no need to have space for three separate connectors.

# 2.0 Project Packaging Description

Our design packaging will consist of two main pieces, the top half of the 3D printed enclosure and the bottom half of the 3D printed enclosure, which will be screwed closed once the PCB for the device is secured within the enclosure. The material used will be ABS 3D printing filament. The top half of the enclosure will have a couple holes sized to fit the fingerprint sensor, the keypad, and the LCD screen, to allow the user to view and interact with them to utilize the device. It will also contain multiple holes on the top half that will screw into screw holes in the bottom half, sealing the device shut. The lower half of the enclosure will contain pegs that will fit into holes in the PCB to secure it in place. Also, both halves of the enclosure will come together leaving a hole in the front of the device to allow the female USB-A connector on the PCB to be accessible from outside of the package. The connector will remain inside the package, but the hole will allow access to the port to allow the device to be connected to computers. We’ll also include a male USB-A to male USB-A cable to allow for an extension wire to be able to interface with female USB-A ports on computers and other devices.

We chose to use a female USB-A port on our device due to mechanical worries and constraints, as our device will be fairly big and have a bit of weight to it, and a male USB-A cable could allow usage without an additional cable.to prevent the device from being damages by having to balance the entirety of the weight of the device on just the male USB-A connector on the PCB. We still are aiming to minimize the weight and size of the device, however, with a keypad, LCD, and fingerprint sensor, there is no way to make the device smaller than the individual components.

# 3.0 Sources Cited

[1] Amazon.com: DataLocker Sentry K350 16GB encrypted USB flash drive keypad, Easy Screen guided setup AES 256, TAA compliant ruggedized MIL-STD 810-G, IP68 OS independent, USB-A, FIPS 140-3 level 3 pending : Electronics, https://www.amazon.com/DataLocker-K350-Encrypted-USB-Drive/dp/B001FXH8J2 (accessed Feb. 15, 2025).

# [2] “3-in-1 fingerprint encrypted USB 3.0 Drive - 64GB to 512GB options,” Sphere Resources, https://sphere-resources.com/product/fingerprint-encrypted-usb-drive/ (accessed Feb. 15, 2025).

# Appendix 1: CAD Model Illustrations

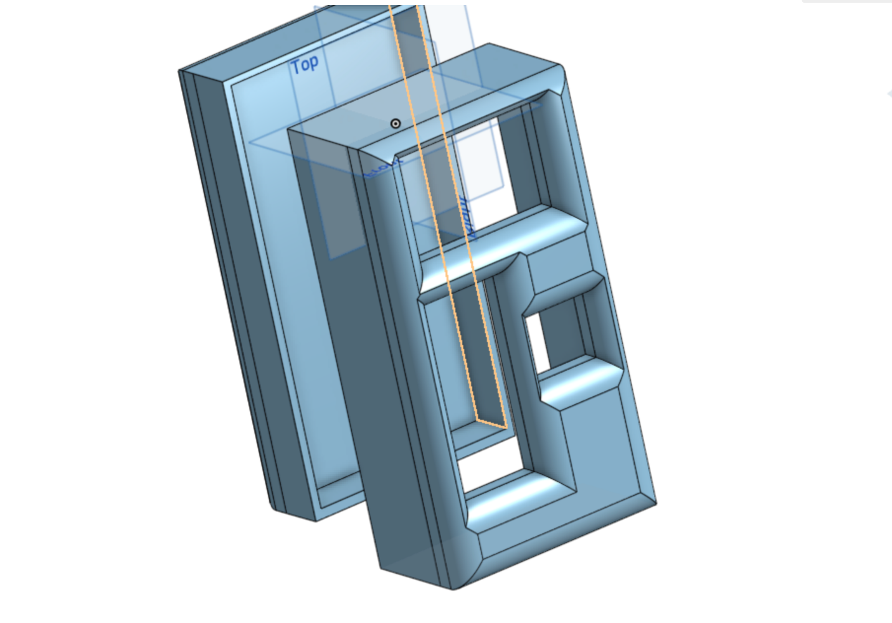
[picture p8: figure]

# Figure 1: An initial diagram of the casing we will be utilizing for our device, with specifications being altered based on dimensions.

# Appendix 2: Project Packaging Specifications

Material | Quantity | Estimated Weight | Estimated Cost
ABS 3D Printing Filament | 1 | 113.08 g (0.249 lbs) | $0.7
Screws | 4 | 0.02 lbs | $0.75
Total | N/A | 0.449 lbs | $1.45

# Requires:

# 3D Printer: Free with Bechtel Innovation Design Center.

# Appendix 3: PCB Footprint Layout

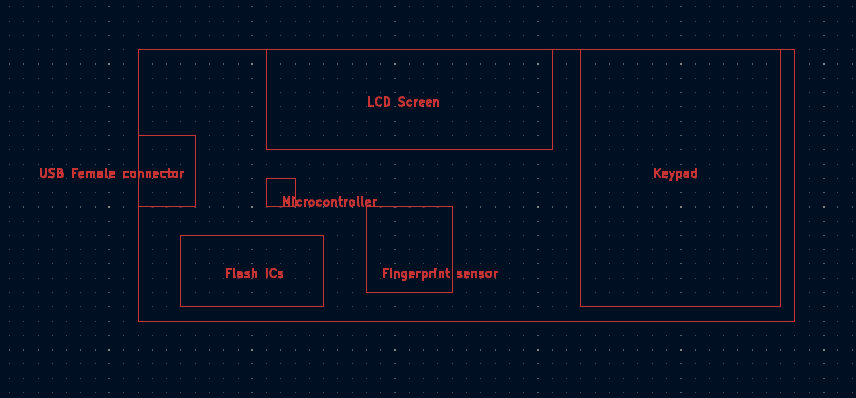
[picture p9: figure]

ECE 477: Digital Systems Senior Design Project Last Modified: 09-12-2024

ECE 47700: Digital Systems Senior Design Project Last Modified: 09-12-2024

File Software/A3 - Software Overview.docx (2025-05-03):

# Software Overview

# Year: 2025 Semester: Spring Team: #20 Project: Encrypted USB Drive

# Creation Date: Jan 30,2025 Last Modified: February 1, 2025

# Author: Joshua Wai Email: waij@purdue.edu

# Assignment Evaluation: See Rubric on Brightspace Assignment

# 1.0 Software Overview

# The primary software functionalities are:

# UI to display on LCD screen

# LCD Display Driver: Prompts (Select User, Enter Passcode) and feedback (Unlocked, Access Denied). Uses I2C/SPI for communication.

# Keypad Input Handler: Debounces inputs using a state machine (with something like 100ms delay to filter noise).

# Authentication

# Password verification

# Fingerprint matching

# Security

# Attempt Counter: Resets to zero on success, increases by 1 on failure, and after 5 failures it will erase data

# Data encryption

# File System

# Virtual partitioning: has user specific files as a FAT32 volume when unlocked

# Read and write data to the USB

# Setup GPIO pin for communication

# Using SPI to read/write

# Firmware responsibilities

# Bootloader: initializes hardware and resets user data when tampering is detected

# Power management: detects when the USB is unplugged to trigger locked state

# Polls fingerprint sensor (every 100ms)

# State machine

# 1.1 User interface management module

The microcontroller initializes the onboard LCD, keypad, and fingerprint sensor on reset. On startup, the system sets the default password for all four users to “0000.” When the USB drive is plugged in, the LCD will display a “Select User” prompt. The user selects their profile by entering 1–4 using the keypad. This module also manages subsequent displays, such as “Enter Passcode” and status messages such as “Unlocked” or error notifications. Use a state machine to debounce input with 100ms delay.

# 1.2 Authentication and Access Control

Two methods of authentication are supported. First, a passcode entry is handled via the keypad with immediate visual feedback (digits are shown as dots to preserve security). Second, fingerprint authentication is integrated via a sensor that compares the live scan with stored biometric data. If either method validates the user, the firmware unlocks the drive, enabling access to user-specific files. When the user is logged in, they can press a button to update their password or fingerprint.

# 1.3 Security

To protect data, the firmware maintains an attempt counter for each user. If a user inputs the wrong passcode five times, then the software automatically erases that user’s data and resets the password to 0000. This protects against unauthorized access and brute force attacks. The firmware will also use secure communication protocols for USB data transactions and will use encryption routines such as AES to protect file content when the drive is being used. This will ensure file security.

# 1.4 File System

The file system uses virtual partitioning to give each user a dedicated FAT32 volume once the device is unlocked. This makes it so that the files remain isolated and secure, and each partition behaves like a standard USB drive volume when accessed by the user. In terms of data operations, this is achieved by setting up specific GPIO pins to facilitate reliable communication between the microcontroller and the USB hardware. Additionally, the firmware utilizes the SPI protocol to handle data transfers. SPI provides a high-speed, full-duplex communication channel, for efficient data transfer.

# 1.5 Firmware Responsibilities

At startup, the bootloader initializes the hardware components, including the LCD, keypad, fingerprint sensor, and USB interface. It also is programmed to reset user data when tampering is detected if multiple passwords are wrong. The firmware will also detect when the USB is unplugged, and trigger the locked state. It will also poll the fingerprint sensor at intervals of 100 milliseconds. We will use a state machine to dictate the overall behavior of the system which include startup, user selection, authentication (passcode entry/fingerprint scan), unlocked (file access), and password update modes.

# 2.0 Description of Algorithms

# 2.1 Input Processing and Debouncing

The firmware continuously polls the keypad for numerical input. To detect the key that’s pressed, two ports of the microcontroller are connected to the rows and columns of the matrix respectively. The port which is connected to the rows of the matrix is configured as an output port, hence making each row logic 0. On the contrary, the port which is connected to the columns is configured as an input port, making the column at logic 1. When a button is pressed, it changes the logic of that column to 0 because the button causes a short circuit between the row and the column. To summarize, when a key is pressed, the column containing the key is driven to logic 0. The microcontroller then checks each row and identifies the row where the button is pressed.

To avoid spurious activations, an input debouncing algorithm ensures that each key press is accurately registered. The microcontroller waits for a certain amount of time and allow the signal to stabilize. It has to also make sure the previous key has been released. The microcontroller scans the matrix after a keypress has been detected. To do this, the microcontroller must make all the rows logic zero and see if all the columns have a logic 1. If all the columns have logic 1, it means that none of the keys are pressed, and the microcontroller looks for a new keypress. See figure below.

# 2.2 Authentication Decision Logic

The authentication module compares the entered passcode against the stored value or accepts the authentication if the fingerprint match is successful using the built in SDK from the fingerprint sensor. In the event of a failed passcode attempt, a counter increments and triggers a data erasure process once five attempts is reached.

# 3.0 Description of Data Structures

3.1 USB Communication Packet (UART)

For data transfers, we will use s structure packet format:

- Header Byte: identifies the packet type (command, data, acknowledgment)
- Payload: contains the data
- Checksum/error detection

3.2 Input Buffer and Display Buffer:

Keypad Input Buffer: Temporarily stores numerical inputs until the user submits the passcode.

Display Buffer: Holds the current message that is sent to the LCD.

3.3 User profile structure

User ID: A unique identifier (1–4).

Passcode: A string or fixed-length array stored in a secure memory area (hashed for extra security)

Fingerprint Template: Data structure or pointer to the biometric template provided by the fingerprint sensor.

Attempt Counter: An integer value tracking consecutive failed passcode entries.

Access Rights/Data Pointer: A pointer or reference to the location of the user’s encrypted file storage.

# 3.4 Microcontroller Communications

# We will be reading and writing using SPI protocols with its SPI running in either of two modes depending on clock polarity (CPOL) and clock phase (CPHA) settings:

# CPOL = 0, CPHA = 0 (Mode 0)

# CPOL = 1, CPHA = 1 (Mode 3)

# Input data is latched in on the rising edge of SCK, and output data is available from the falling edge of SCK for both modes

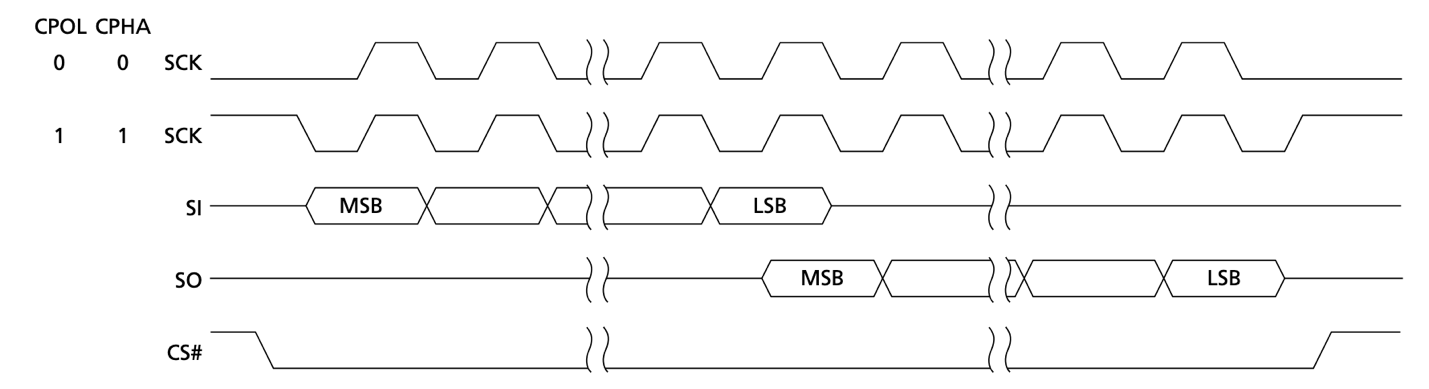
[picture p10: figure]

Standard Commands

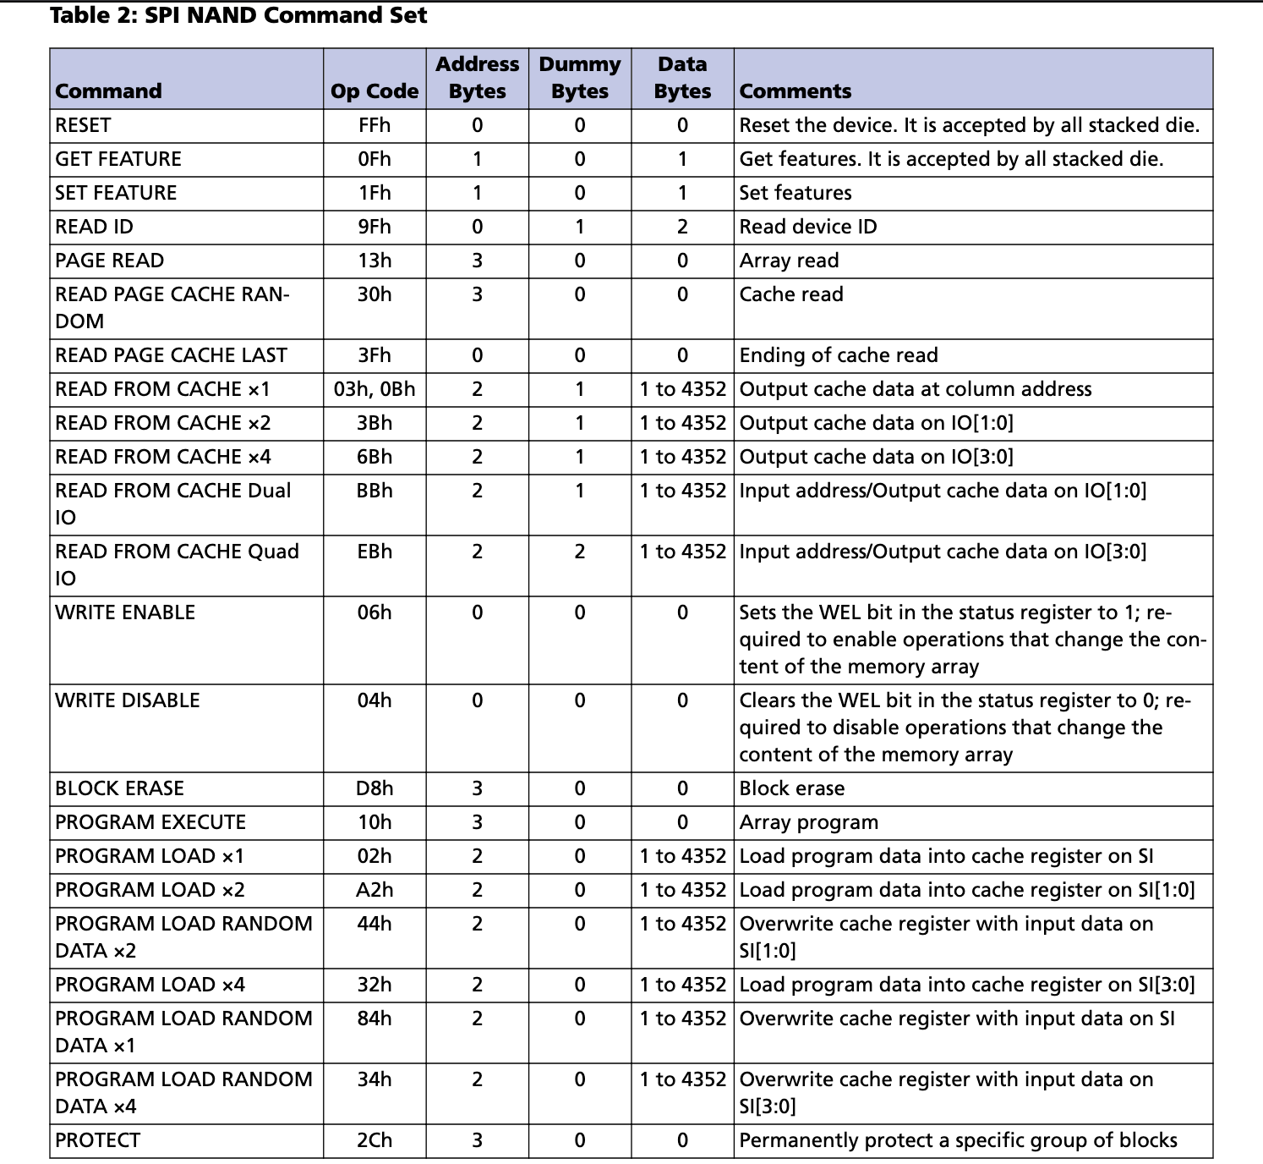
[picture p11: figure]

# 4.0 Sources Cited:

# J. Ganssle, "Debouncing, hardware and software, part 2," The Ganssle Group. [Online]. Available: https://www.ganssle.com/debouncing-pt2.htm. [Accessed: Jan. 31, 2025].

# Technobyte, "Keypad Matrix and 8051 Interfacing," Technobyte.org, [Online]. Available: https://technobyte.org/keypad-matrix-8051-interfacing/. [Accessed: Jan. 31, 2025].

# E. Peña and M. G. Legaspi, "UART: A Hardware Communication Protocol," Analog Dialogue, vol. 54, Dec. 2020. [Online]. Available: https://www.analog.com/en/resources/analog-dialogue/articles/uart-a-hardware-communication-protocol.html. [Accessed: Jan. 30, 2025].

# S. Campbell, "Basics of UART Communication," Circuit Basics, Feb. 13, 2016. [Online]. Available: https://www.circuitbasics.com/basics-uart-communication/. [Accessed: Jan. 30, 2025].

# Appendix 1: Program Flowcharts

# Main Program


# Keypress and debounce logic

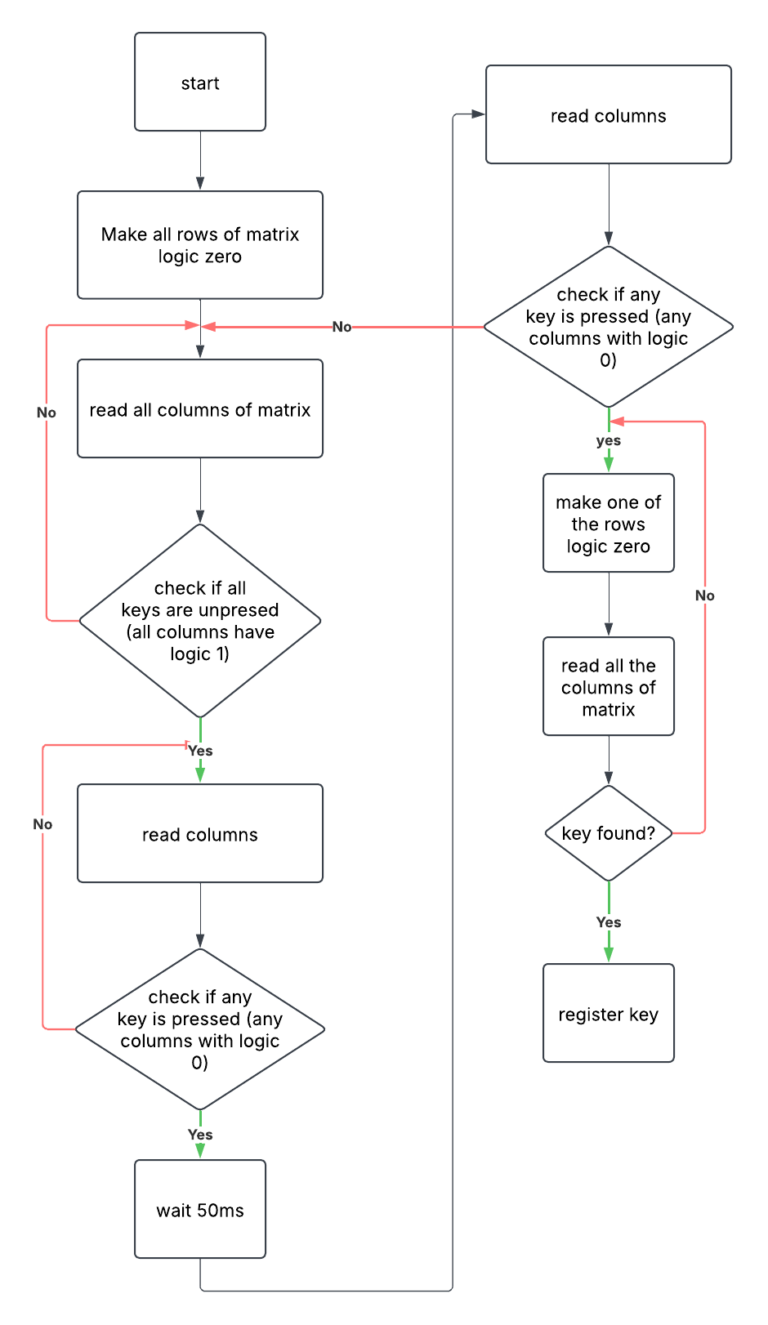
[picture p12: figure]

# Appendix 2: State Machine Diagrams


ECE 477: Digital Systems Senior Design Last Modified: 08-31-2023

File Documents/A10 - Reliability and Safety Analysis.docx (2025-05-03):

# A10 - Reliability and Safety Analysis

# Year: 2025 Semester: Spring Team: 20 Project: Encrypted USB Drive

# Creation Date: April 5, 2025 Last Modified: April 30, 2025

# Author: Brandon Liu Email: liu3394@purdue.edu

# 1.0 Reliability Analysis

The components of interest are the STM32H7 Microcontroller [1], the USB ESD protection, and the TVS ESD protection diodes. The microcontroller was chosen due to its complexity and high volume of pins; the USB ESD protection diode [2] was chosen due to the fact that USB is a key functionality of the project and if it is damaged via excessive voltage spikes, the device may not work;the TVS ESD protection diode was chosen due to for a similar reason as the USB ESD protection, except this is for other components of the product including but not limited to the keypad and fingerprint sensor.

# The following equations are used for the reliability analysis with the first one for the failure rate for the microcontroller [4], the second equation for the mean time to failure, and the third equation for the failure rate of the diodes [4] being analyzed:

# Lambda_p_MCU = (C1 * temp coeff + C2 * env const) * learning factor * quality factor

# MTTF = 10^6 / (24 * 365 * lambda_p) years

# Lambda_p_diode = lambda_b * temp coeff * e stress * env const * contact construct factor * quality factor

# Microcontroller:

# Table 1 STM32H7A3RGT6

Parameter name | Description | Value | Comments regarding choice of parameter value, especially if you had to make assumptions.
C1 | Die complexity | 0.56 | 32-bit bus
πT | Temperature coeff. | 0.98 | 85 deg C max
C2 | Pin/Package Constant | 0.025 | MCU is to be soldered so assuming that hermetic column of 5.9 table to be used
πe | Environmental Constant | 0.5 | G_B
πl | Learning Factor | 1.0 | Device produced for over 2 years (based on manuals and technical notes released in 2019)
πq | Quality Factor | 10 | Device uses commercial components
Entire design:
Lambda_p | | 5.61
MTTF | | 20.3 years

# USB ESD Protection:

# Table 2 USBLC6-2SC6

Parameter name | Description | Value | Comments regarding choice of parameter value, especially if you had to make assumptions.
Lambda_b | Base failure rate | 0.0013 | Transient suppressor
πT | Temperature coeff. | 21 | 150 deg C max
πS | Electrical stress factor | 1.0 | Transient suppressor
πe | Environmental Constant | 1.0 | G_b
πC | Contact construction factor | 1.0 | Metallurgically bonded (soldering)
πq | Quality Factor | 5.5 | Lower (chosen because device not necessarily for military but no indication of plastic in data sheet)
Entire design:
Lambda_p | | 0.15015
MTTF | | 760 years

# TVS ESD Protection:

# Table 3 D5V0L2B3SO-7

Parameter name | Description | Value | Comments regarding choice of parameter value, especially if you had to make assumptions.
Lambda_b | Base failure rate | 0.0013 | Transient suppressor
πT | Temperature coeff. | 21 | 150 deg C max
πS | Electrical stress factor | 1.0 | MCU is to be soldered so assuming that hermetic column of 5.9 table to be used
πe | Environmental Constant | 1.0 | G_b
πC | Contact construction factor | 1.0 | Metallurgically bonded (soldering)
πq | Quality Factor | 8.0 | Plastic
Entire design:
Lambda_p | | 0.2184
MTTF | | 522 years

# Summary:

The MTTF for all components is extremely high, meaning that the device will last well within its reasonable usage which is just to temporarily store files. One solution for even greater longevity is to use these devices at normal room temperatures, and not extreme ones that are too hot or too cold. This allows for the device’s minimum and maximum temperature to not be stressed as much.

# 2.0 Failure Mode, Effects, and Criticality Analysis (FMECA)

The two failure modes in consideration are medium and low. Medium refers to damage to the device such that components no longer work at all, and low refers to errors that result in illogical operation despite the component still being functional. There is no high category as there is not a voltage in the device that should lead to human injury. The acceptable failure rate (arbitrary value) is 10^-9 for both medium and low failure modes. It is under the assumption that the user will read the manual in its entirety before using the device, and the device will not be used in extreme climates (including but not limited to scorched heat or freezing temperatures) or weather conditions (including but not limited to rain or snow).

# 3.0 Sources Cited:

# [1] STM32H7A3RGT6 stmicroelectronics | mouser, https://www.mouser.com/ProductDetail/STMicroelectronics/STM32H7A3RGT6?qs=sPbYRqrBIVk%2BdecRlyVesQ%3D%3D (accessed Apr. 7, 2025).

# [2] ST, USBLC6-2 Datasheet, https://www.st.com/content/ccc/resource/technical/document/datasheet/06/1d/48/9c/6c/20/4a/b2/CD00050750.pdf/files/CD00050750.pdf/jcr:content/translations/en.CD000507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 (accessed Apr. 7, 2025).

# [3] Diodes Incorporated, D5V0L2B3SO, https://www.diodes.com/assets/Datasheets/D5V0L2B3SO.pdf (accessed Apr. 7, 2025).

# [4] Military Handbook, https://snebulos.mit.edu/projects/reference/MIL-STD/MIL-HDBK-217F-Notice2.pdf (accessed Apr. 6, 2025).

# Appendix A: Schematic Functional Blocks

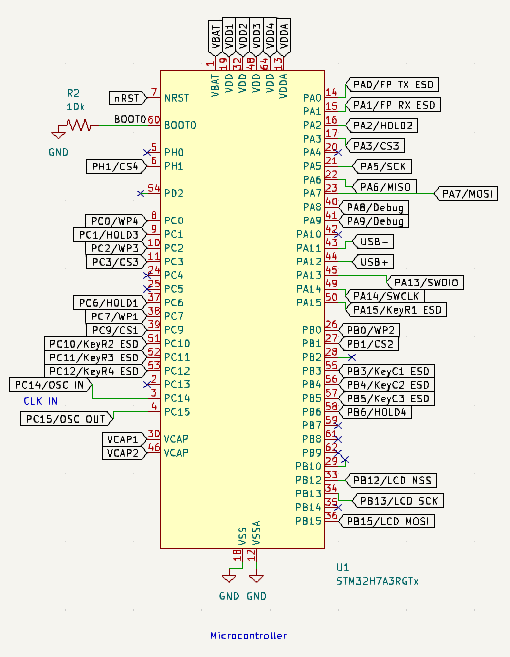
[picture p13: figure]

# Figure 1, microcontroller circuitry

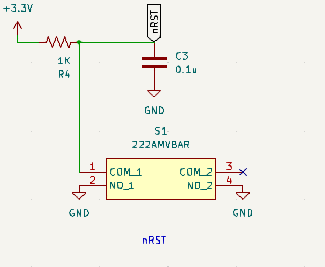
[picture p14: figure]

# Figure 2, reset circuitry

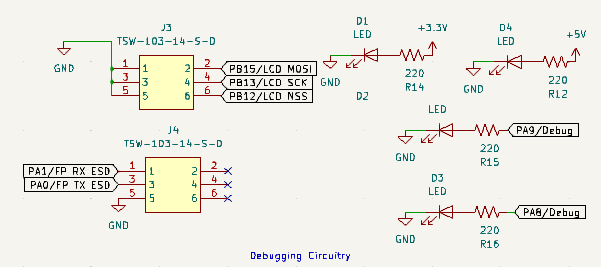
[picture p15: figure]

# Figure 3, debugging circuitry

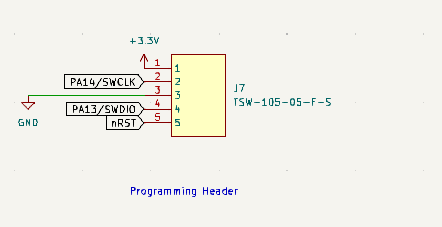
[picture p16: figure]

# Figure 4, programming circuitry

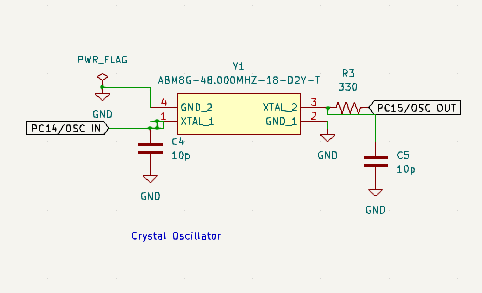
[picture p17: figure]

# Figure 5, oscillator circuitry

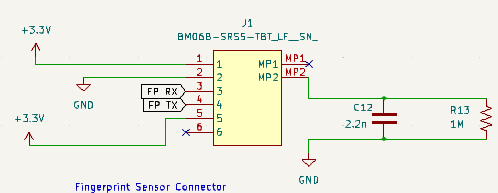
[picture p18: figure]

# Figure 6, Fingerprint circuitry

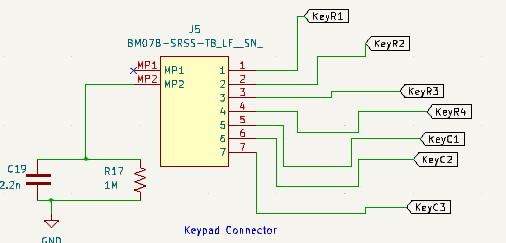
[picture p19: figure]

# Figure 7, keypad circuitry

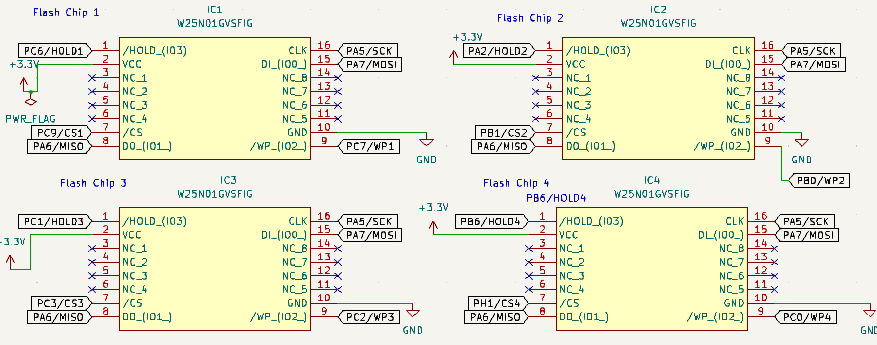
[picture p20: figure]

# Figure 8, flash IC circuitry

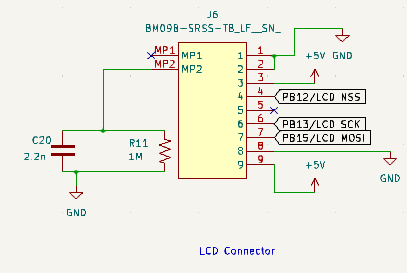
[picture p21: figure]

# Figure 9, LCD circuitry

# Appendix B: FMECA Worksheet

# Table 4, Microcontroller circuitry

Failure No. | Failure Mode | Possible Causes | Failure Effects | Method of Detection | Criticality | Remarks
1 | No signal coming out of a certain pin | Programmed wrong pin / damaged pin | Unpredictable | Slave devices do not respond or state machine is not followed | Medium | Assuming microcontroller is powered via USB connected to a computer
2 | Extreme signal noise | Improperly soldered decoupling capacitor | Unpredictable | Slave devices do not respond and oscilloscope reads noisy signals coming from master | Medium | Assuming code and wiring is all correct

# Table 5, Reset Circuitry

Failure No. | Failure Mode | Possible Causes | Failure Effects | Method of Detection | Criticality | Remarks
1 | Reset signal stays high | Damaged push button or poor soldering onto PCB | System cannot reset | Observation, pressing push button does not affect current function of device | Low | Assuming code is all correct
2 | Reset signal stays low | A short through C3 | System is stuck in reset (looped) | Observation | Medium | Assuming push button is operational and wiring is soldered properly

# Table 6, Programming Circuitry

Failure No. | Failure Mode | Possible Causes | Failure Effects | Method of Detection | Criticality | Remarks
1 | No data received via programming header | Damaged header / connection issues with the programmer on the STM32F4 dev board | Cannot program microcontroller | Observation (MCU functionality does not change) | Medium | Assuming programmer on dev board is powered

# Table 7, Oscillator circuitry

Failure No. | Failure Mode | Possible Causes | Failure Effects | Method of Detection | Criticality | Remarks
1 | No signal coming into the oscillator pins of microcontroller | Connected to wrong pins / damaged crystal | Unable to reach oscillator speed and therefore will have to rely on in built clock | Observation | Low

# Table 8, Fingerprint circuitry

Failure No. | Failure Mode | Possible Causes | Failure Effects | Method of Detection | Criticality | Remarks
1 | No response from fingerprint sensor | Improperly configured UART | Unable to communicate with slave | Reading communication bus via oscilloscope | Low
2 | Fingerprint sensor does not scan | Damaged component | Unable to communicate with device | Oscilloscope reading correct but slave not operational | Medium | UART properly configured

# Table 9, Keypad circuitry

Failure No. | Failure Mode | Possible Causes | Failure Effects | Method of Detection | Criticality | Remarks
1 | Pressing of a key not registered | Improper programming / damaged matrix circuitry | Certain key is unresponsive | Observation | Medium

# Table 10, Flash IC circuitry

Failure No. | Failure Mode | Possible Causes | Failure Effects | Method of Detection | Criticality | Remarks
1 | Unable to read or manipulate data in flash IC | Damaged component | Unable to interact with data stored in flash IC | Oscilloscope reading / STM32CubeIDE debugger | Medium | Assuming SPI communication bus is configured properly

# Table 11, LCD circuitry

Failure No. | Failure Mode | Possible Causes | Failure Effects | Method of Detection | Criticality | Remarks
1 | Back light not powered on | Not connected to power / damaged component | Unpredictable | Observation | Medium | Assuming SPI communication bus is configured properly
2 | Logic failure in LCD display | Sending improper commands or illegal characters | LCD displays unexpected characters | Observation | Low | Assuming SPI communication bus is configured properly

https://engineering.purdue.edu/ece477 Page 1 of 5

https://engineering.purdue.edu/ECE477 Page 1 of 5

ECE 477: Digital Systems Senior Design Last Modified: 04-07-2025

ECE 477 Digital Systems Senior Design Project Spring 2019

ECE 477 Digital Systems Senior Design Project Spring 2009

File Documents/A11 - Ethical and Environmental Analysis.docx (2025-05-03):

# A11 - Ethical and Environmental Analysis

# Year: 2025 Semester: Spring Team: 20 Project: Encrypted USB Drive

# Creation Date: April 12, 2025 Last Modified: April 12, 2025

# Author: Stanley So Email: sos@purdue.edu

# Assignment Evaluation: See the Rubric in the Brightspace Assignment

# 1.0 Environmental Impact Analysis

The physical parts of our product include a PCB, various integrated circuits, a keypad, a fingerprint sensor, an LCD display, and a 3D printed case. Our product has little environmental impact during normal use, since there are no parts coming in or out of it, but it does have environmental impacts during the manufacturing and disposal stage.

During the manufacturing stage, we need to manufacture a PCB, which involves handling hazardous chemicals and using a significant amount of energy [1]. The hazardous chemicals are used when manufacturing the substrate of the PCB, FR-4. The energy consumption comes from the machines that make the PCB, especially reflow ovens that need to heat up the PCB in order to melt solder. Since the PCB manufacturing and potentially the soldering would be done by another company, there’s not much we can do about this besides making the PCB as small as possible.

We also need to manufacture various integrated circuits that live on our PCB. The manufacturing process involves dealing with chemicals like fluorinated gases that are excellent greenhouse gasses. It also requires a lot of energy, which can lead to even more greenhouse gas emissions [2]. Since these chips are manufactured by different companies, I’m not sure there’s much we can do as designers to mitigate these environmental effects.

The keypad, fingerprint sensor, and LCD display also need to be manufactured. All these components include a PCB, so we chose the smallest versions of these components that met our requirements. In addition, the LCD display requires hazardous chemicals, a lot of water, and a significant amount of energy to manufacture [3]. That can lead to greenhouse gas emissions and waste generation. Choosing a small LCD display will mitigate these effects as well.

Making the 3D printed case requires heating up filaments, which consumes energy, and can lead to greenhouse gas emissions depending on where the energy is coming from. 3D printing requires about 10 times more energy than standard production processes like injection molding [4]. 3D printing is a good solution for prototyping / not that many sales, but if there are a lot of sales, it would be environmentally friendly to switch to another production process. In addition, we can make our case as small as possible while still holding all the components.

During the disposal stage, you can’t just simply throw the product in the trash. The PCB, integrated circuits, keypad, fingerprint sensor, and LCD display all contain harmful chemicals and are considered e-waste. The 3D printed case is not biodegradable under normal conditions [5]. What the user should do is give the product to an e-waste recycling facility or electronics store and see what they can do with it. The PCBs can be smelted to recover valuable metals [6]. The 3D printed case could go through an extruder, which would recycle the plastic and turn it back into filament, but this is not a widely available option and often leads to weaker filament. Instead, we could switch to something like injection molding and use a plastic that is widely recyclable (like #1 or #2 plastic).

# 2.0 Ethical Challenges

The male to male USB cable poses a safety risk. The user can plug in both ends of the cable into a computer, and the computer can get damaged because of it. To address this, we can add text to the user manual saying, “don’t stick both ends of cable into computer”, along with an image with a cross through it of someone doing that.

When it comes to usage, I can see this product potentially being used by criminals. The target audience is supposed to be companies protecting their secrets, but criminals can use these to give secret messages to their network. In the past, encrypted phones have been used by large criminal organizations for this exact purpose, and as a result, law enforcement have shut down many encrypted phone companies [7]. I think the main difference between our product and encrypted phones are that this product cannot communicate over the internet, so criminals would have to meet in person to give each other files. It might be helpful, sure, but it’s not going to be a gamechanger for criminals. I think this problem is interesting to think about, but I don’t think it’s a big enough concern for us to put any features against this. And I’m not sure how to put any features against this without compromising security.

Since we want to keep data on these chips secure, we need some sort of onboard encryption. We can’t simply write the raw data to the flash chips, or else someone can go into our case, desolder the flash chips, and then get all the data off. One of our stretch PSDRs is to have onboard encryption, and in a real product, this would be an essential requirement before we could bring the product to market.

There is also the problem that the user can brute force different passwords. One approach would be to erase the data after too many failed attempts, but that might lead to abuse since the data is so easy to erase. Instead, what we will do is implement a timer, where the USB drive has to be plugged in for a certain amount of time before the user can try a password. This time will increase with the number of failed attempts.

# 3.0 Sources Cited

# [1] M. Media, “The Environmental Impact of Circuit Board Assembly,” Nova, Sep. 20, 2023. https://novaenginc.com/the-environmental-impact-of-circuit-board-assembly/

# [2] J. C. Hess, “Chip Production’s Ecological Footprint: Mapping Climate and Environmental Impact,” Interface-eu.org, Jun. 20, 2024. https://www.interface-eu.org/publications/chip-productions-ecological-footprint

# [3] Reshine-Display, “What Are the Environmental Impacts of Manufacturing LCD Displays? - Reshine Display,” www.reshine-display.com, May 20, 2024. https://www.reshine-display.com/what-are-the-environmental-impacts-of-manufacturing-lcd-displays.html (accessed Apr. 12, 2025).

# [4] Perch Energy, “3D Printing: Eco-Friendly & Sustainable? (Not Quite) | Perch Energy,” www.perchenergy.com, Sep. 17, 2022. https://www.perchenergy.com/blog/innovation/is-3d-printing-eco-friendly-sustainable

# [5] R. Toor, “The Truth about the Biodegradability of PLA Filament,” https://www.filamentive.com/, 2024. https://www.filamentive.com/the-truth-about-the-biodegradability-of-pla-filament/

# [6] General Digital, “What You Need to Know about Recycling LCD Monitors & Displays,” General Digital Corporation, Mar. 11, 2014. https://generaldigital.com/what-you-need-to-know-about-recycling-lcd-monitors-displays/

# [7] fern, “ANØM: The Most Genius FBI Operation,” YouTube, Dec. 08, 2024. https://youtu.be/f6FRIDG8TPY (accessed Apr. 12, 2025).

https://engineering.purdue.edu/ece477 Page 1 of 2

ECE 47700: Digital Systems Senior Design Last Modified: 04-12-2025

ECE 477 Digital Systems Senior Design Project Rev 9/12

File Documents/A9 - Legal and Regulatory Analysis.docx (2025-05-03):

# A9 - Legal and Regulatory Analysis

# Year: 2025 Semester: Spring Team: 20 Project: Encrypted USB drive

# Creation Date: May 27, 2025 Last Modified: March 29, 2025

# Author: Joshua Wai Email: waij@purdue.edu

# Assignment Evaluation: See the Rubric in the Brightspace Assignment

# 1.0 Regulatory Analysis

To market the encrypted USB drive, the device must comply with several regulatory certifications to ensure it meets both safety and electromagnetic interference standards. Given that the device integrates digital electronics, a keypad, and a biometric fingerprint sensor, the following regulatory steps are necessary:

- FCC Compliance: As an unintentional radiator operating at frequencies that could exceed 9 kHz, the USB drive must conform to FCC Part 15 standards for Class B devices. This requires initial in-house testing for radio frequency emissions, followed by formal verification at an accredited testing laboratory. The design benefits from its compact enclosure, which minimizes EMI emissions; however, additional measures such as the use of ferrite beads and optimized circuit layout will be necessary to ensure compliance.
- UL Certification: Electrical and fire safety testing must be conducted to obtain UL certification. This involves ensuring that all electronic components and the enclosure meet the required safety standards to mitigate any risk of overheating or electrical hazards.
- CE Marking and RoHS Compliance: In order to sell our product in European countries, the device must meet CE marking requirements. Compliance with RoHS standards will also be necessary.
- USB Standards Compliance: The device must adhere to the USB specification for data transfer and power delivery. This involves both hardware and software design considerations to ensure interoperability with existing USB standards.
- Encryption and Data Security Standards: Depending on the encryption algorithm implemented (which is currently planned to be AES), additional security certifications may be necessary. We will perform a security audit and obtain any relevant certifications to bolster the device’s credibility as a secure storage solution.

To progress from prototype to a finished product, the following steps will be taken:

- Since we need a FCC certification we need to test the device in a Telecommunications Certification Body (TCB) lab
- Perform preliminary EMI, UL, and functional testing in-house.
- Conduct tests to ensure that the product complies with all relevant European safety, health, and environmental standards.
- Hardware Verification: Ensure that the physical design adheres to USB specifications for both data transfer and power delivery.
- Software Integration: Develop and validate the necessary software components to support USB protocol requirements.
- Interoperability Testing: Test the device with various USB-compliant systems to confirm seamless integration and functionality.

# 2.0 Legal Liability Analysis

# 2.1 Analysis of Patent 1

# https://patents.google.com/patent/USD845964S1/en

This section reviews three patents that have similarities to the functions provided by the encrypted USB drive. The analysis below outlines the filing dates, abstracts, and key claims of each patent, along with a discussion of potential infringement issues.

US Patent Publication Number: US 20170234567 A1
Filing Date: January 10, 2017

Abstract:
This patent discloses a secure portable storage device that integrates a biometric fingerprint sensor for user authentication. It covers systems that store encrypted data and require biometric verification to grant access to the stored information.

Potential Infringement:
Key claims include:

- Integration of a fingerprint sensor with an onboard encryption mechanism.
- User authentication through biometric data.
- Data access control based on verified fingerprint input.

Analysis:
Our USB drive employs a fingerprint sensor to verify user identity and works in tandem with a keypad for multi-factor authentication. Although the fingerprint authentication method is similar to the claims in this patent, our design differentiates itself by requiring dual verification (fingerprint and keypad) which strengthens security. Also the encryption algorithm used in our device is different from the processes described in the patent.

# 2.2 Analysis of Patent 2

# https://patents.google.com/patent/CN104766620A/en

US Patent Publication Number: US 20190345678 A1
Filing Date: March 12, 2019

Abstract:
This patent covers a secure USB device that employs a keypad for user authentication, focusing on a method for verifying input sequences to unlock encrypted storage. The invention emphasizes a user-friendly interface combined with secure access control.

Potential Infringement:
Key claims include:

- Implementation of a keypad for authentication.
- Storage and encryption of data with access restricted to users inputting a correct sequence.
- Integration of a microcontroller to process user inputs and manage encryption.

Analysis:
While our device also uses a keypad as one element of its authentication process, it integrates a fingerprint sensor to provide a second layer of security. This dual-factor approach differentiates our design from the their solution which is using only the keypad. By combining biometric data with keypad input, the system introduces another layer authentication that reduces the likelihood of unauthorized access.

# 2.3 Analysis of Patent 3

# https://patents.google.com/patent/US20130332747A1/en

US Patent Publication Number: US 20180398765 A1
Filing Date: June 5, 2018

Abstract:
This patent describes an encrypted USB storage device that utilizes both biometric authentication and manual input methods to secure data. The invention highlights a method for combining two forms of authentication to enhance device security.

Potential Infringement:
Key claims include:

- Simultaneous use of biometric and keypad-based authentication methods.
- Secure encryption of stored data accessible only upon successful dual-factor authentication.
- Specific methods for processing biometric data in conjunction with manual input to grant access.

Analysis:
Our project closely mirrors some aspects of Patent 3, particularly in its use of dual authentication methods. However, differences exist in the implementation details. For instance, our design uses a fingerprint sensor with higher resolution and integrates a user-defined password that is different from the predetermined processes described in Patent 3. But this patent will be the closest to our device in terms of its solution and design

# 3.0 Sources Cited:

# Federal Communications Commission, "Equipment Authorization - RF Device," Mar. 29, 2025. [Online]. Available: https://www.fcc.gov/oet/ea/rfdevice. [Accessed: 28-Mar-2025].

C. Maorong and L. Youxiong, "Encrypted USB flash disk," CN 104766620 A, Jul. 8, 2015. [Online]. Available: https://patents.google.com/patent/CN104766620A/en. [Accessed: Mar. 28, 2025].Google Patents (https://patents.google.com/patent/CN104766620A/en?utm_source=chatgpt.com)

D. Kim, H. Cho, and J. Kim, "Encrypted flash drive," U.S. Patent D845,964 S1, Apr. 16, 2019. [Online]. Available: https://patents.google.com/patent/USD845964S1/en. [Accessed: Mar. 29, 2025].Google Patents (https://patents.google.com/patent/USD845964S1/en?utm_source=chatgpt.com)

R. B. Roberts and R. B. Gardner, "Removable drive with data encryption," U.S. Patent Application 2013/0332747 A1, Dec. 12, 2013. [Online]. Available: https://patents.google.com/patent/US20130332747A1/en. [Accessed: Mar. 29, 2025].

Federal Communications Commission, "Understanding the FCC Regulations for Computers and Other Digital Devices," OET Bulletin No. 62, Dec. 1993. [Online]. Available: https://transition.fcc.gov/Bureaus/Engineering_Technology/Documents/bulletins/oet62/oet62rev.pdf. [Accessed: Mar. 29, 2025].NEMA (https://www.nema.org/docs/default-source/technical-document-library/fcc-regulations-applicable-to-nema-products-.pdf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)

https://engineering.purdue.edu/ece477 Page 1 of 2

ECE 47700: Digital Systems Senior Design Last Modified: 03-28-2025

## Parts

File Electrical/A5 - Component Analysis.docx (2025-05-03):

# Component Analysis

# Year: 2025 Semester: Spring Team: 20

# Project: Encrypted USB Drive

# Creation Date: February 8, 2025 Last Modified: February 8, 2025

# Member 1: Abhijay Achukola Email: aachukol@purdue.edu

# Member 2: Brandon Liu Email: liu3394@purdue.edu

# Member 3: Stanley So Email: sos@purdue.edu

# Member 4: Joshua Wai Email: waij@purdue.edu

# Assignment Evaluation: See Rubric on Brightspace Assignment

# 1.0 Component Analysis:

Component 1 will be the microcontroller, which will be the processing center for our device, handling all the inputs, outputs, and managing data in/out of the device. Component 2 will be the LCD display, which will inform the user on the status of the device, whether it is locked or not, and display the password as it is entered. Component 3 will be the keypad where passwords will be entered to gain access to the device. Component 4 will be the flash memory IC, where the data for each user will be stored in separate ICs. Finally, Component 5 will be the fingerprint sensor, which will be used to gain access to the device as well.

# 1.1 Analysis of Component 1:

We will start by comparing the central part of our project, the microcontroller. We decided to stick with an STM32 type of microcontroller due to our familiarity with it in ECE 362 and our familiarity with the STM32Cube IDE. We then had to consider what functionalities our microcontroller had to do. It must be able to communicate via SPI to four flash ICs, communicate via SPI with an LCD, iterate between pins and read pins to utilize the keypad effectively, communicate via UART to the fingerprint sensor, communicate the data through USB at a minimum of 12 Mbps, and be able to handle a menu system and storing passwords to help connect all the individual components and present a good ui. We had an option to disregard the need for USB handling on microcontroller and instead sending data over UART, but we felt that it would be needlessly difficult and could mess up the USB timing requirements, so we instead opted for looking at microcontrollers that handled USB on chip.

This resulted in narrowing down our search to three families of microcontrollers, the STM32L4 family, the STM32F7 family, and the STM32H7 family. All three of these contain enough peripherals for all functions of the base model for our project but vary slightly on other functions it brings to the table. All three handle USB on chip, but the L4 family only has access to full-speed USB transmission, not high-speed. The first microcontroller to be eliminated was the L4 family, as using a low-power chip isn’t particularly useful, as we’ll be powering our device through the USB port itself, so the lower processing power and other downsides aren’t really worth saving a few minutes of battery life of a laptop or having no effect on PCs. That leaves the H7 and F7, both having top-of-the-line processing power. These two microcontrollers were similar, but we ended up choosing the H7 as we believe the high-performance edge it has over the F7 will help us with our responsiveness while managing the 4 GB flash ICs and USB protocol timings.

# 1.1 Analysis of Component 2:

One of the main components to display directions to the user is via an LCD screen. This LCD screen is to connect with the MCU with ease and ideally be communicated with using the SPI interface; this interface has been used by our group before so the learning curve should be short, but if it is difficult to identify a purchasable component that operates in SPI, then a different custom protocol can be considered. The other main constraint is that the LCD should be two rows, that way users can see a prompt while also seeing what they are typing on the keypad (which will then be displayed on the LCD).

The metrics mentioned above will be used to determine which LCD to obtain, and weights will be assigned to each metric to reflect its importance, and the highest score will be the component our team will pick. Each component will be ranked 1 through 3 on the weighted metrics with 3 being the most ideal and 1 being least ideal. In the case that multiple products fulfill the metric in the same way, they will receive the same rank. Both metrics are weighted the same because the # of rows is an important requirement to streamline the user experience and the learning curve is important because in previous classes, we have operated with LCDs before, so if we can handle this part quickly, we can save more time to focus on more difficult aspects of the project.

Product | # of rows (w = 1) | Learning curve (w = 1) | Total Score
(HD44780 LCD) | 2 | 1 | 3
(WEH001602A LCD) | 2 | 3 | 5
(SPI LCD) | 2 | 2 | 4

After comparing the 3 devices, we will probably pick the WEH001602A LCD if we can buy it (we couldn’t find a site that lets us purchase the part yet) because it is the same LCD that we can prototype with and have used in ECE 36200 and can be communicated with via the SPI interface. The SPI LCD is the runner up because it is a rather different LCD and has more than 2 rows, but since it uses a protocol that we are familiar with, it is second place. Here’s where the rankings get a little interesting; although the HD44780 is not indicated to be using the SPI interface and has its own little protocol and commands, the pinout is very similar to that of the WEH001602A LCD and the same pins all have the same purpose. The datasheet for this device does not mention SPI, so the learning curve here is a little unknown and we do not know if the two parts are the same. If they are, then the HD44780 can easily be purchased on digikey, but the datasheets presented on the site do not mention SPI anywhere.

# 1.1 Analysis of Component 3:

One of the main components to allow user interaction with the thumb drive itself is via a keypad, which will request a user identification and password to process authentication. A matrix keypad will be ideal as it is a component that we have used and programmed before. We also don’t need that many buttons because there are only 4 users and each can use a numeric passcode for authentication, so numbers from 0 through 9 are sufficient along with some special keys to help the user indicate what it wants to do. If the keypad can also be more sustainable in various physical environments, that is a plus as well.

The following metrics will be taken into consideration when picking the ideal keypad: being a matrix keypad, having less buttons to yield flexibility in space constraint, and having the ability to operate in different environments. Weights will be assigned to each metric to reflect its importance, and the highest score will be the component our team will pick. In the table below, the cells will be filled with 1 or 0, 1 being meeting the requirement and 0 not meeting the requirement. Matrix keypad and button count are weighted the same because both are constraints that the group is unwilling to be flexible on, and the flexibility in physical environments has a lower weight because it is more of an extra requirement.

Product | Is matrix keypad (w = 3) | Has less than 4x4 buttons (w = 3) | Flexible in various physical environments (w = 2) | Total Score
(membrane 3x4) https://www.adafruit.com/product/419?gQT=1 | 1 | 1 | 1 | 8
(phone style 3x4) https://www.adafruit.com/product/1824?gQT=1 | 1 | 1 | 0 | 6

After comparing the two devices based on our metrics, we ended up choosing the membrane 3x4 keypad. This is because although like the phone style keypad both use a matrix architecture and is smaller than 4x4 (essentially less the A, B, C, and D keys that are found in a 4x4), it is flat and rain proof; if water were to hit the surface of the keypad, it won’t seep through. However, the phone keypad has gaps and water can get beneath the keys and damage the product.

# 1.1 Analysis of Component 4:

A major part of our design is storing data, so to avoid partitioning issues that could lead to security issues, we decided to have four separate ICs for each user of the usb drive. We initially were looking at EEPROMs, but after seeing the small storage size and learning about the differences between flash and EEPROM chips, we decided to go with flash memory to allow use of paged memory, which allows modification of bigger chunks of data at once. Some of the criteria we looked at while selecting flash ICs included the package they came in, the size of the memory they can store, how easily they can be interfaced with, among other things. We did not want to try using a ball grid array packaged ic, as it would be difficult to solder and prototype, and ideally, we wanted one that was through-hole or surface-mount package. We also wanted somewhere between 1-10 GB of storage per IC, as each user should be able to store a fair amount of data for our device to be useful as a USB drive. Finally, flash ICs often were able to be used by communicating with the IC through SPI, so we would want to find ICs such as that, so they can be interfaced with the microcontroller we have.

This ended up narrowing our search down to two different flash ICs. Notably the MT29F4G01ABAFDWB-IT:F from Micron and the MT29F4G08ABADAH4:D TR from Micron. Both were similar, providing 4 GB of flash memory, both being able to be modified using SPI. While both were very useful for our project, we ended up going with the MT29F4G01ABAFDWB-IT:F, as it had an easier package to solder and prototype with. While it wasn’t a through-hole or simple SMD component, it is easier to handle than the BGA package the other IC came in. The IC we chose came in an 8-UDFN package, which is small and consists of 8 pads on the bottom of the IC that act as the connectors. Also, the other IC also outputted data in parallel, which would be hard for us to handle correctly, especially within the microcontroller.

# 1.1 Analysis of Component 5:

One major part of making this encrypted USB drive is to make sure that it is secure and so our decision was to add a fingerprint sensor in order to access the content stored within the USB drive. We want a fingerprint sensor that is not too bulky or else it won’t fit well onto the device itself which will be unfavorable practically and aesthetically. Also we also wanted it to be a relatively flat sensor so that it can lay on the device comfortably and since our goal is for this device to be carried around in the customer’s pockets or bags it should be easy to store so having protruding parts would not be ideal. Fingerprint sensors come in 4 types: optical, capacitive, ultrasonic, and thermal. We went for the capacitive or optical sensors because they are currently the most reliable on the market. Thermal sensors wouldn’t perform well under variable temperatures and ultrasonic sensors came out relatively recently increasing the risk. Another factor would be the price/ease of obtainability.

The metrics and criteria mentioned above will be used to determine which fingerprint sensor we ultimately decide to use. Weights will be assigned to each metric, and the highest score will be the component our team will pick. In the table below, the sensors will be ranked from 0 to 3, 0 being least ideal, 3 being most ideal.

Fingerprint Sensor Product | Flat shaped (w = 3) | Capacitive/optical sensor (w = 1) | Ease of obtainability (w = 2) | Total Score
GROW R308 | 0 | 2 | 3 | 8
UART Fingerprint Reader | 0 | 2 | 1 | 3
GROW R502-A | 3 | 2 | 2 | 15

# 2.0 Sources Cited:

# Adafruit Industries, "Adafruit 16x2 Character LCD + Keypad for Raspberry Pi," [Online]. Available: https://www.adafruit.com/product/1824. [Accessed: 08-Feb-2025].

# Adafruit Industries, "Membrane 3x4 Matrix Keypad + extras - 3x4," [Online]. Available: https://www.adafruit.com/product/419. [Accessed: 08-Feb-2025].

# ^ prices found in each link

# HD44780

# UNIVERSAL-SOLDER Electronics Ltd, "26076," [Online]. Available: https://www.digikey.com/en/products/detail/universal-solder-electronics-ltd/26076/16821383. [Accessed: 08-Feb-2025].

# WEHLCD

# Winstar Display Co., Ltd., "WEH001602A - 16x2 COB OLED Character Display," [Online]. Available: https://www.winstar.com.tw/products/oled-module/oled-character-display/weh001602a.html. [Accessed: 08-Feb-2025].

# SPI LCD mouser

# Display Visions, "EA TFT024-23ATNN," [Online]. Available: https://www.mouser.com/ProductDetail/Display-Visions/EA-TFT024-23ATNN?qs=IKkN%2F947nfCa9Z2pp%252BAi%2FA%3D%3D.

# [Accessed: 08-Feb-2025].

“STM32 32-bit Arm Cortex MCUs - STMicroelectronics,” STMicroelectronics. https://www.st.com/en/microcontrollers-microprocessors/stm32-32-bit-arm-cortex-mcus.html

‌Digikey, “MT29F4G01ABAFDWB-IT:F,” Digikey. https://www.digikey.com/en/products/detail/micron-technology-inc/MT29F4G01ABAFDWB-IT-F/8509729 (accessed Feb. 08, 2025).

‌Digikey, “MT29F4G08ABADAH4:D TR.” https://www.digikey.com/en/products/detail/micron-technology-inc/MT29F4G08ABADAH4-D-TR/4315127 (accessed Feb. 08, 2025).

# Waveshare, “UART Fingerprint Reader,” Waveshare, [Online]. Available: https://www.waveshare.com/uart-fingerprint-reader.htm. [Accessed: Feb. 8, 2025].

# Hubtronics, “GROW R308 Fingerprint Module,” Hubtronics, [Online]. Available: https://hubtronics.in/grow-r308-fingerprint-module. [Accessed: Feb. 8, 2025].

# Hubtronics, “GROW R502 A Fingerprint Module,” Hubtronics, [Online]. Available: https://hubtronics.in/grow-r502-a-fingerprint-module. [Accessed: Feb. 8, 2025].

ECE 47700: Digital Systems Senior Design Last Modified: 09-07-2023

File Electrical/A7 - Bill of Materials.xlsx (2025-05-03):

Bill of Materials
Year: | 2025
Semester: | Spring
Team #: | 20
Project Name: | Encrypted USB Drive
Authors: | Stanley So, Joshua Wai, Abhijay Achukola, Brandon Liu
Created: | 2025-02-15
Last Modified: | 2025-02-15
Project Component | PCB |  | Value | Package |  |  |  |  | Approximate Price
Description | ID | Qty | (Ohm, etc.) | (type or size) | Manufacturer | Mfg. Part # | Supplier | Supplier Part # | (Qty 1)
STM32H7 Microcontroller | U1 | 1 | N/A | LQFP-64 | STMicroelectronics | STM32H7A3RGT6 | STMicroelectronics | STM32H7A3RGT6 | $14.13
5V to 3.3V LDO | U2 | 1 | N/A | SOT-223-3 | Diodes Incorporated | AZ1117IH-3.3TRG1 | DigiKey | AZ1117IH-3.3TRG1 | $0.58
48 MHz Crystal | Y1 | 1 | 48 MHz | 4-SMD, No Lead | Abracon LLC | ABM8G-48.000MHZ-18-D2Y-T | DigiKey | 535-10282-1-ND | $0.98
USB-A Female Connector | J1 | 1 | N/A | Through Hole | TE Connectivity AMP Connectors | 6364372-2 | DigiKey | A122647-ND | $1.26
3x4 Keypad | U7 | 1 | N/A | Off Board | SparkFun Electronics | COM-14662 | DigiKey | 1568-1856-ND | $4.95
Fingerprint Sensor | U8 | 1 | N/A | Off Board | Waveshare Electronics | UART Fingerprint Reader A | Waveshare | UART Fingerprint Reader A | $42.99
Flash ICs | U3-U6 | 4 | N/A | 8-UDFN | Winbond Electronics | W25N01GVSFIG | Mouser | 454-W25N01GVSFIG | $4.30
LCD Display | DS1 | 1 | N/A | Off Board | Newhaven Display Intl | NHD-0216K3Z-FL-GBW-V3 | DigiKey | NHD-0216K3Z-FL-GBW-V3-ND | $23.75
Printed Circuit Board | N/A | 1 | N/A | Custom | JLCPCB | N/A | JLCPCB | N/A | $10.00
Enclosure | N/A | 1 | N/A | Custom | Custom | N/A | N/A | N/A | $7.00
Note: Do not list misc. discrete parts (resistors, caps, etc.) such as decoupling caps and ESD protection current limiting resistors.

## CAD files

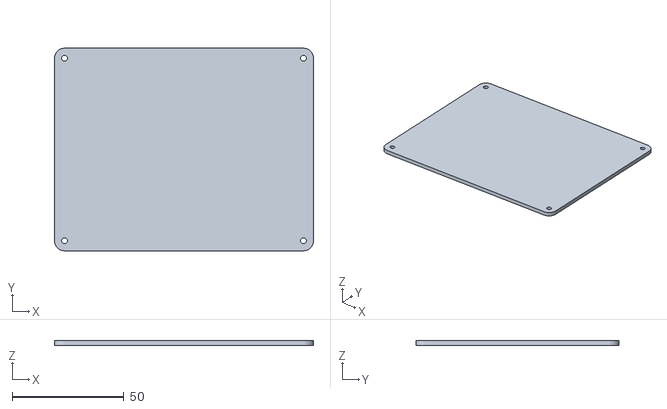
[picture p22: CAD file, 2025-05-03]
Mechanical/3D Files/usb_case_bottom.stl
116.1 x 90.8 x 2.11

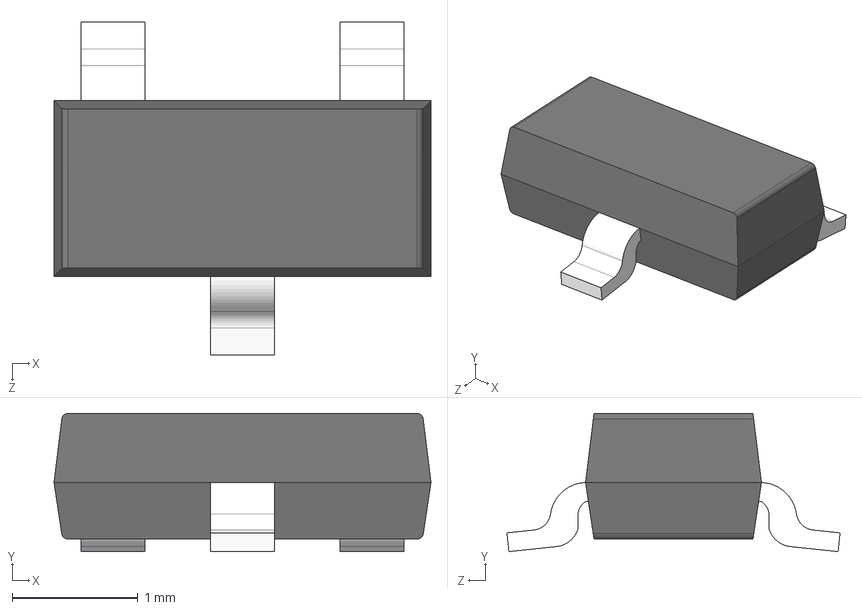
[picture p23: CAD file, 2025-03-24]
Electrical/KiCAD Files/3D models/D5V0L2B3SO-7.stp
3.00 x 1.10 x 2.65 mm

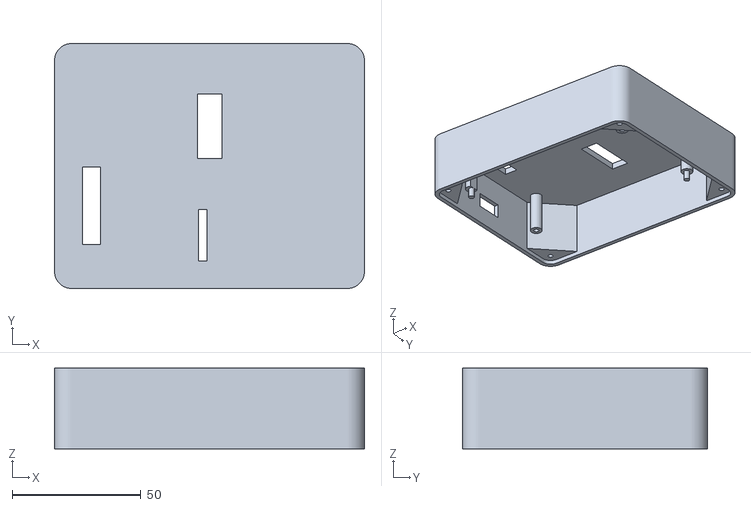
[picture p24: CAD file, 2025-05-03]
Mechanical/3D Files/usb_case_top.stl
120.3 x 95.0 x 31.4

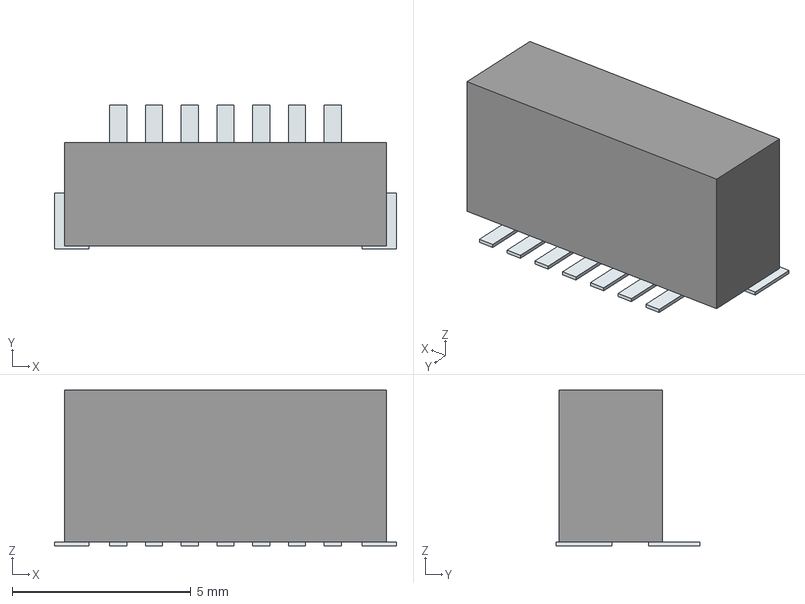
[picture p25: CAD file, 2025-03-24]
Electrical/KiCAD Files/3D models/BM07B-SRSS-TB_LF__SN_.stp
9.56 x 4.02 x 4.35 mm
Pins

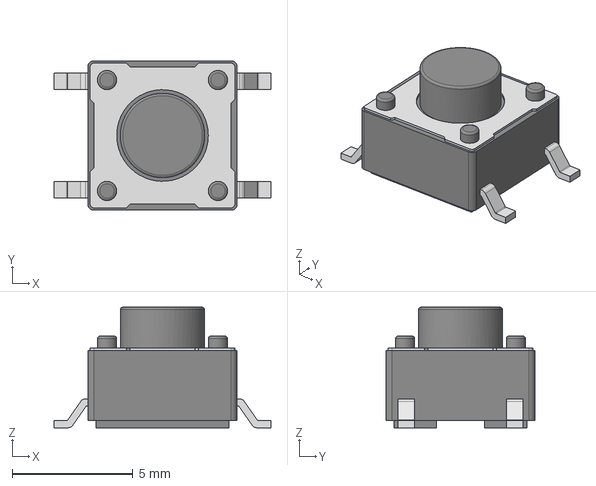
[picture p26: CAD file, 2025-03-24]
Electrical/KiCAD Files/3D models/222AMVBAR.stp
9.00 x 6.20 x 5.00 mm

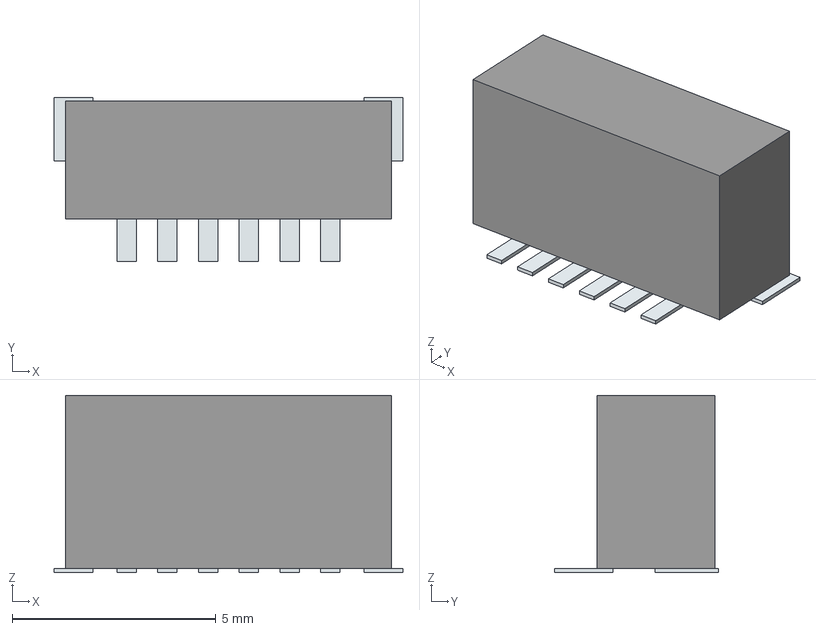
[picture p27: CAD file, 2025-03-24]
Electrical/KiCAD Files/3D models/BM06B-SRSS-TBT_LF__SN_.stp
8.56 x 4.02 x 4.35 mm
Pins

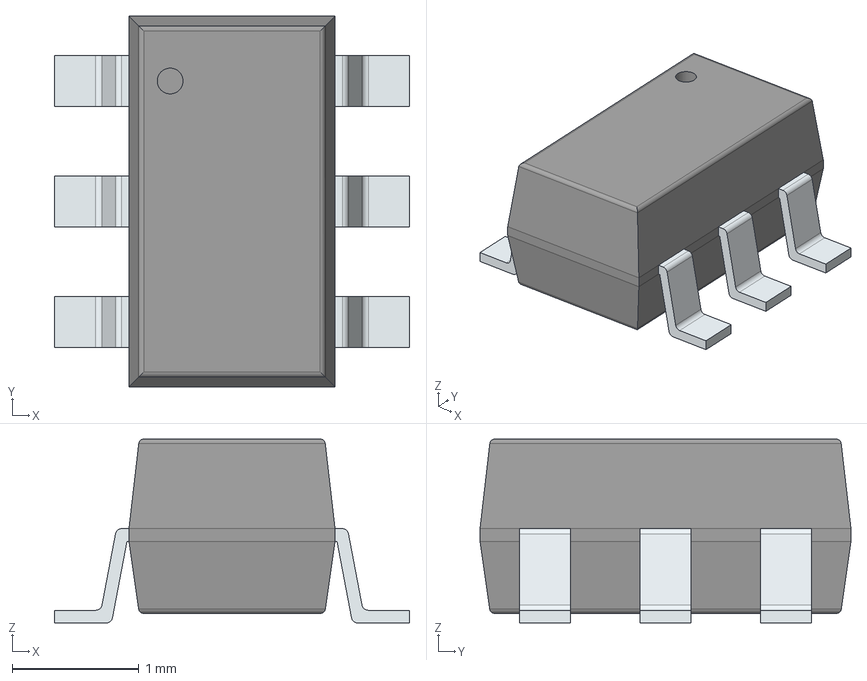
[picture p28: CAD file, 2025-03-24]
Electrical/KiCAD Files/3D models/USBLC6-2SC6.stp
2.80 x 2.92 x 1.45 mm
PinsArrayLR

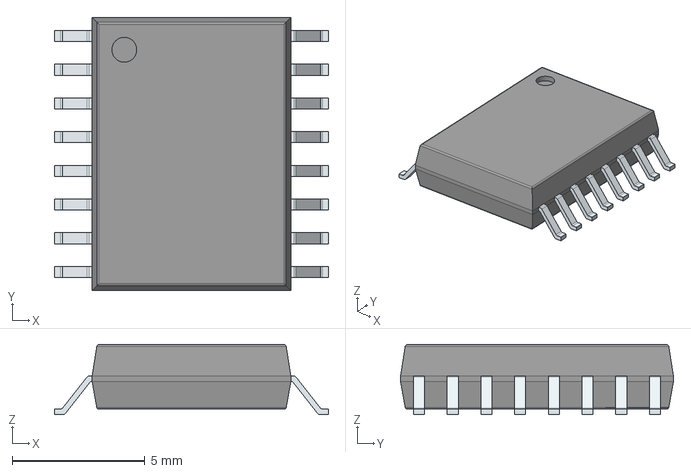
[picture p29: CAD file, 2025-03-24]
Electrical/KiCAD Files/3D models/W25N01GVSFIG.stp
10.3 x 10.3 x 2.64 mm
PinsArrayLR

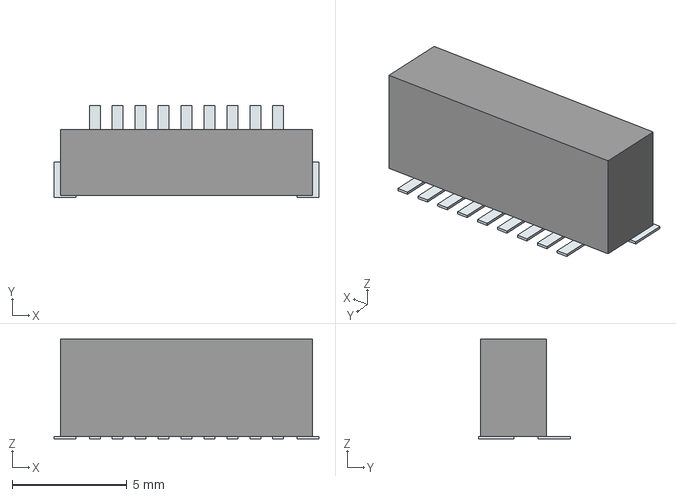
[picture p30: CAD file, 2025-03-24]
Electrical/KiCAD Files/3D models/BM09B-SRSS-TB_LF__SN_.stp
11.6 x 4.02 x 4.35 mm
Pins

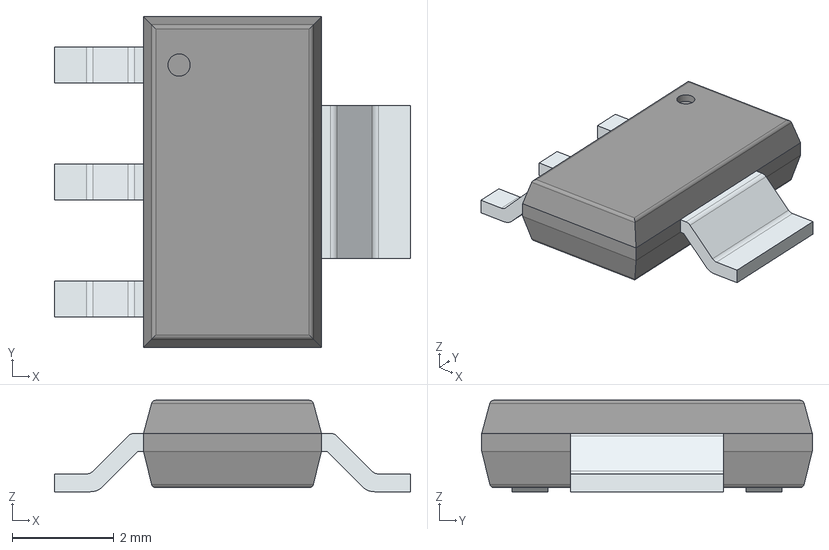
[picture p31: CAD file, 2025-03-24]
Electrical/KiCAD Files/3D models/AZ1117IH-3.3TRG1.stp
7.00 x 6.50 x 1.80 mm
PinsArrayL
FilletPinR

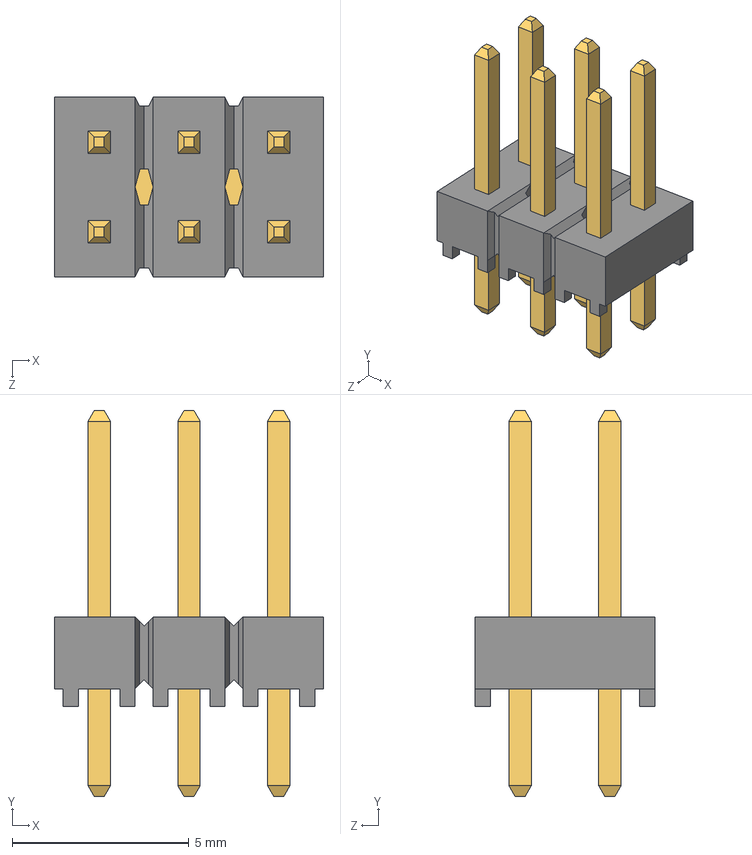
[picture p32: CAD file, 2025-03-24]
Electrical/KiCAD Files/3D models/TSW-103-14-S-D.stp
7.62 x 10.9 x 5.08 mm
TSW-103-07-G-D_body
T-1S6-07-TSW-1-07-3-D

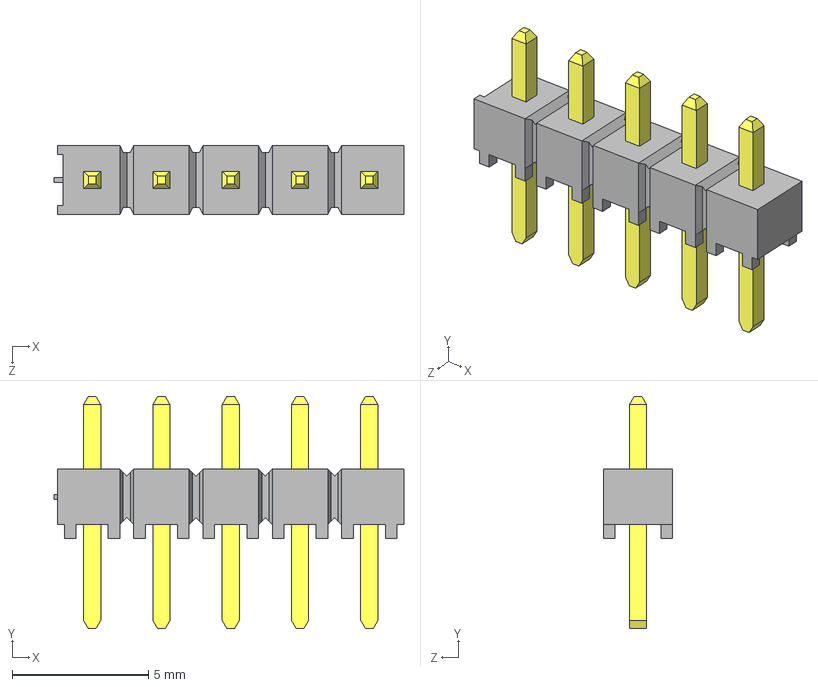
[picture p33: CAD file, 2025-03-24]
Electrical/KiCAD Files/3D models/TSW-105-05-F-S.stp
12.8 x 8.51 x 2.54 mm
T-1S6-21-TSW-1-05-5-S
TSW-105-05-G-S_body

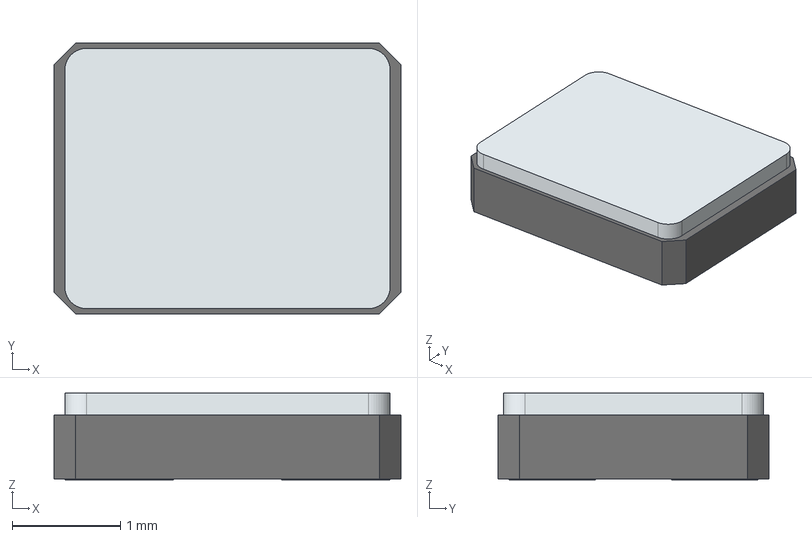
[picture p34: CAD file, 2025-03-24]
Electrical/KiCAD Files/3D models/ABM8-48.000MHZ-B2-T.stp
3.20 x 2.50 x 0.8 mm
solidBody
solidLid
solidTerminal

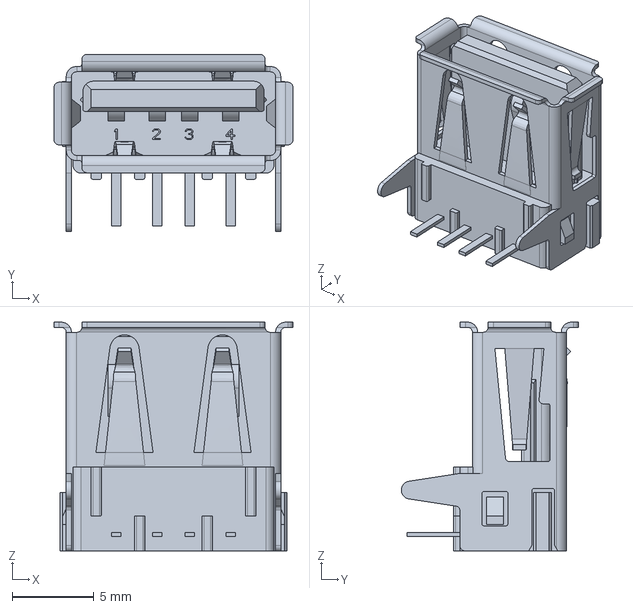
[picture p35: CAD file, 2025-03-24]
Electrical/KiCAD Files/3D models/6364372-2.stp
14.6 x 10.9 x 14.0 mm

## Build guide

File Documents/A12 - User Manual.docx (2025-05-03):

# A12 - User Manual

# Year: 2025 Semester: Spring Team: 20 Project: Encrypted USB Drive

# Creation Date: 4/18/2025 Last Modified: May 3, 2025

# Author: Abhijay Achukola Email: aachukol@purdue.edu

# Assignment Evaluation: See the Rubric in the Brightspace Assignment

1.0 Product Description
Often times, there is a need for secure offline sharing of data in high-security company communication and file transfers. While scattering USB drives all over an office space could be one solution, a sharable USB drive that secures everyone’s data separately is a great solution that can allow only those with correct permissions to access independent banks of data on the same USB drive. Just keep some in stock in your office spaces, and individuals can use them as needed, without risk of overwriting other people’s data or reading data they should not be given access to. Every device comes with hardware separation of data, secured with password and fingerprint for up to four users, each having an allocated storage of 1 GB. Purchase some today to improve your workflows and improve data security around your company!

# 2.0 Product Illustrations

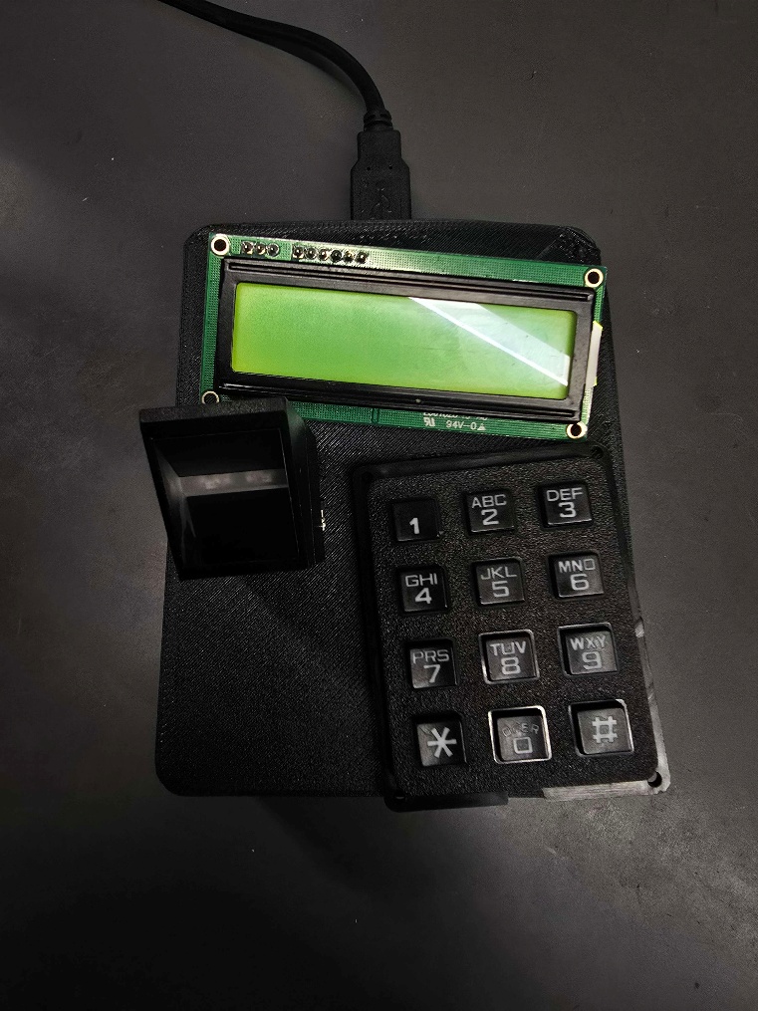
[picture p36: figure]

USB-A male to male cable

LCD HUD

Fingerprint

Sensor

Keypad

# 3.0 Setup Instructions

# Steps to Initialize the device

# 1. Plug in the device to your computer using the provided USB-A male to male wire.

# 2. Select the account number 1-4 that you’d like to set up.

# 3. Press the star key on the keypad and enter the passcode of 0000 into the device to login to the account.

# 4. Press the star key on the keypad and enter in your new four digit passcode (must be only in digits). Press pound to cancel before typing all four digits if you messed up in entering your passcode.

# 5. Press the zero key on the keypad and present your finger of choice to the fingerprint sensor. Then, press your finger on the fingerprint sensor of choice for one second and then remove your finger from the sensor. Repeat this process two more times to save your fingerprint to the device.

# 6. Press the pound key on the keypad to lock the device. Then, follow that up with the pound key again after being prompted if you really want to lock the device to finally lock the device.

# 7. Now your device is ready and secured with your login alone!

# 4.0 Usage Instructions

# Normal Usage of the Device

# 1. Plug the device to your computer using the provided USB-A male to male wire.

# 2. Select your account number (1-4).

# 3. Press the star key on the keypad and enter your passcode or press the pound key and present your fingerprint to the fingerprint sensor.

# 4. Utilize the USB storage device as needed on your device.

# 5. Press the pound key to lock the device. Then, follow that up with the pound key after being prompted if you really want to lock the device to finally lock the device.

# Changing Your Password

# 1. Plug the device to your computer using the provided USB-A male to male wire.

# 2. Select your account number (1-4).

# 3. Press the star key on the keypad and enter your old passcode or press the pound key and present your fingerprint to the fingerprint sensor.

# 4. Press the star key on the keypad and enter your new four-digit passcode. Enter the pound key before entering all four digits or press the star key after entering all four digits to change your passcode again in case of a mistake.

# Changing Your Fingerprint

# 1. Plug the device to your computer using the provided USB-A male to male wire.

# 2. Select your account number (1-4).

# 3. Press the star key on the keypad and enter your passcode or press the pound key and present your old fingerprint to the fingerprint sensor.

8. Press the zero key on the keypad and present your finger of choice to the fingerprint sensor. Then, press your finger on the fingerprint sensor of choice for one second and then remove your finger from the sensor. Repeat this process two more times to change your fingerprint on the device. Press the 0 key or wait a short time to change your fingerprint again in case of a mistake.

# 5.0 Troubleshooting Instructions

# Q. I can’t get my files to display on the system.

# A. Ensure by checking the LCD display that you are currently logged in. If you are, try logging out and logging back in. Finally, if that doesn’t work, try removing the drive from the computer and re-inserting it.

# Q. I can’t log into the system.

# A. Ensure that you are selecting the correct account and that you are entering in your password correctly or presenting the correct fingerprint to the fingerprint sensor.

# Q. The LCD displays weird characters.

# A. Try adjusting the LCD a bit and remove the drive from the computer and re-insert it.

# We are sorry that you experienced trouble with one of our products. For any further issues please contact our customer service team at +1 (800) –727–9143.

https://engineering.purdue.edu/ece477 Page 1 of 2

ECE 47700: Digital Systems Senior Design Last Modified: 04-19-2025

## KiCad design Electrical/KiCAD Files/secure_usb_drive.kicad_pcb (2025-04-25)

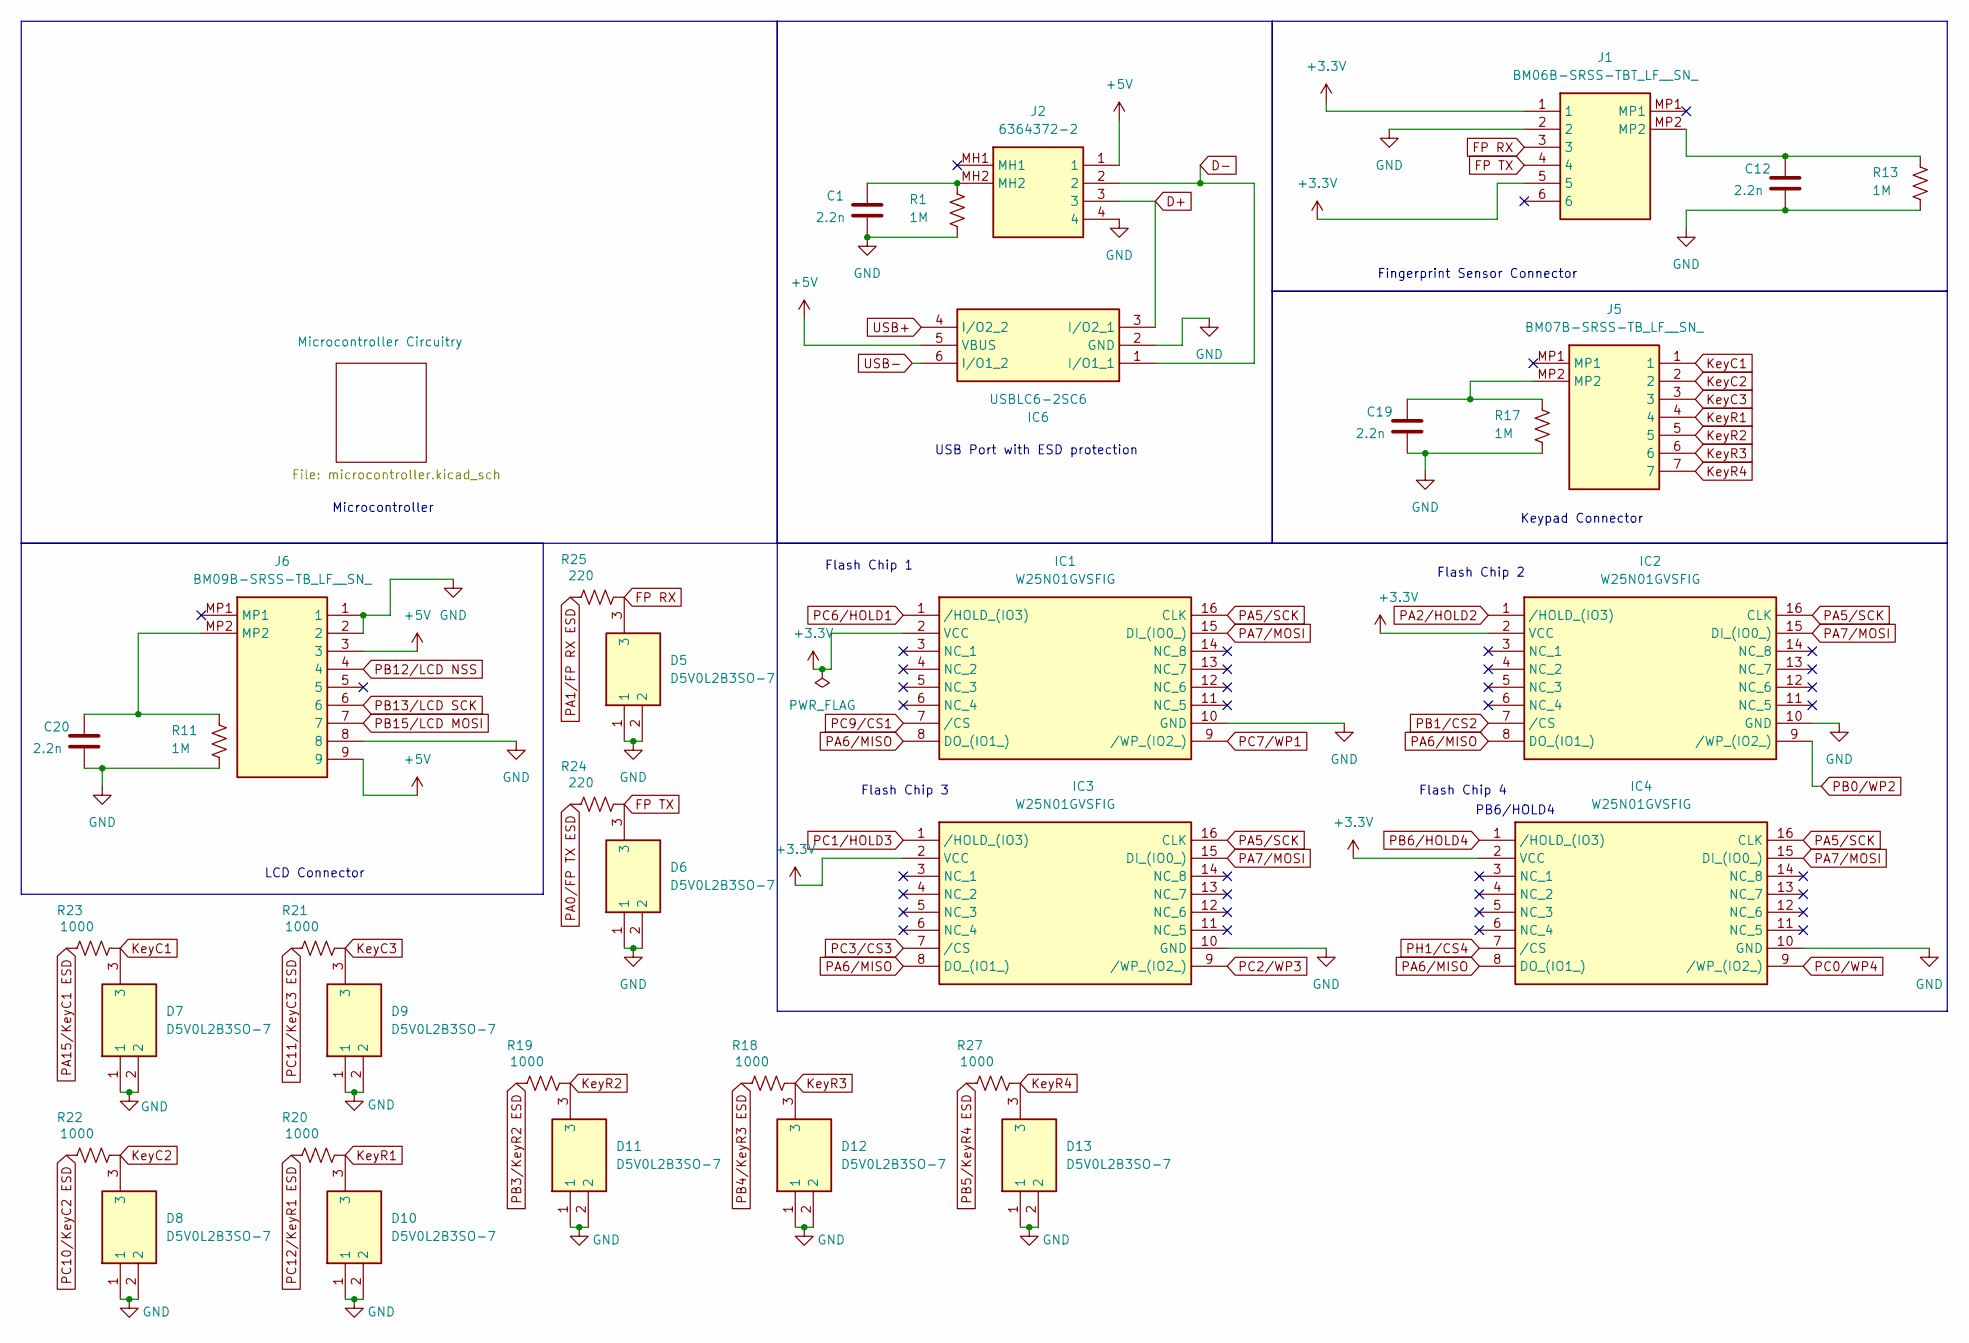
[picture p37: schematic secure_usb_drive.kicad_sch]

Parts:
C1, C12, C19, C20: 2.2n; C_0805_2012Metric_Pad1.18x1.45mm_HandSolder
D5, D6, D7, D8, D9, D10, D11, D12, D13: D5V0L2B3SO-7; SOT96P240X110-3N; Mouser Part Number 621-D5V0L2B3SO-7
IC1, IC2, IC3, IC4: W25N01GVSFIG; SOIC127P1032X264-16N; Mouser Part Number 454-W25N01GVSFIG
IC6: USBLC6-2SC6; SOT95P280X145-6N; Mouser Part Number 511-USBLC6-2SC6
J1: BM06B-SRSS-TBT_LF__SN_; BM06BSRSSTBTLFSN; Mouser Part Number 306-BM06BSRSSTBTLFSN
J2: 6364372-2; 63643722; Manufacturer_Part_Number 6364372-2; Mouser Part Number 571-6364372-2
J5: BM07B-SRSS-TB_LF__SN_; BM07BSRSSTBLFSN; Mouser Part Number N/A
J6: BM09B-SRSS-TB_LF__SN_; BM09BSRSSTBLFSN; Mouser Part Number N/A
R1, R11, R13, R17: 1M; R_0805_2012Metric_Pad1.20x1.40mm_HandSolder
R18, R19, R20, R21, R22, R23, R27: 1000; R_0805_2012Metric_Pad1.20x1.40mm_HandSolder
R24, R25: 220; R_0805_2012Metric_Pad1.20x1.40mm_HandSolder

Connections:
+5V: IC6.5 (VBUS), J2.1, J6.3, J6.9; also elsewhere on the board
D+: IC6.3 (I/O2_1), J2.3
D-: IC6.1 (I/O1_1), J2.2
FP RX: D5.3, J1.3, R25.1
FP TX: D6.3, J1.4, R24.1
GND: C1.2, C12.2, C19.2, C20.2, D5.1, D5.2, D6.1, D6.2, D7.1, D7.2, D8.1, D8.2, D9.1, D9.2, D10.1, D10.2, D11.1, D11.2, D12.1, D12.2, D13.1, D13.2, IC1.10 (GND), IC2.10 (GND), IC3.10 (GND), IC4.10 (GND), IC6.2 (GND), J1.2, J2.4, J6.1, J6.2, J6.8, R1.2, R11.2, R13.2, R17.2; also elsewhere on the board
KeyC1: D7.3, J5.1, R23.1
KeyC2: D8.3, J5.2, R22.1
KeyC3: D9.3, J5.3, R21.1
KeyR1: D10.3, J5.4, R20.1
KeyR2: D11.3, J5.5, R19.1
KeyR3: D12.3, J5.6, R18.1
KeyR4: D13.3, J5.7, R27.1
unnamed: C1.1, J2.MH2, R1.1
unnamed: C12.1, J1.MP2, R13.1
unnamed: C19.1, J5.MP2, R17.1
unnamed: C20.1, J6.MP2, R11.1
PA0/FP TX ESD: R24.2; also elsewhere on the board
PA1/FP RX ESD: R25.2; also elsewhere on the board
PA2/HOLD2: IC2.1 (/HOLD_(IO3)); also elsewhere on the board
PA5/SCK: IC1.16 (CLK), IC2.16 (CLK), IC3.16 (CLK), IC4.16 (CLK); also elsewhere on the board
PA6/MISO: IC1.8 (DO_(IO1_)), IC2.8 (DO_(IO1_)), IC3.8 (DO_(IO1_)), IC4.8 (DO_(IO1_)); also elsewhere on the board
PA7/MOSI: IC1.15 (DI_(IO0_)), IC2.15 (DI_(IO0_)), IC3.15 (DI_(IO0_)), IC4.15 (DI_(IO0_)); also elsewhere on the board
PA15/KeyC1 ESD: R23.2; also elsewhere on the board
PB0/WP2: IC2.9 (/WP_(IO2_)); also elsewhere on the board
PB1/CS2: IC2.7 (/CS); also elsewhere on the board
PB3/KeyR2 ESD: R19.2; also elsewhere on the board
PB4/KeyR3 ESD: R18.2; also elsewhere on the board
PB5/KeyR4 ESD: R27.2; also elsewhere on the board
PB6/HOLD4: IC4.1 (/HOLD_(IO3)); also elsewhere on the board
PB12/LCD NSS: J6.4; also elsewhere on the board
PB13/LCD SCK: J6.6; also elsewhere on the board
PB15/LCD MOSI: J6.7; also elsewhere on the board
PC0/WP4: IC4.9 (/WP_(IO2_)); also elsewhere on the board
PC1/HOLD3: IC3.1 (/HOLD_(IO3)); also elsewhere on the board
PC2/WP3: IC3.9 (/WP_(IO2_)); also elsewhere on the board
PC3/CS3: IC3.7 (/CS); also elsewhere on the board
PC6/HOLD1: IC1.1 (/HOLD_(IO3)); also elsewhere on the board
PC7/WP1: IC1.9 (/WP_(IO2_)); also elsewhere on the board
PC9/CS1: IC1.7 (/CS); also elsewhere on the board
PC10/KeyC2 ESD: R22.2; also elsewhere on the board
PC11/KeyC3 ESD: R21.2; also elsewhere on the board
PC12/KeyR1 ESD: R20.2; also elsewhere on the board
PH1/CS4: IC4.7 (/CS); also elsewhere on the board
USB+: IC6.4 (I/O2_2); also elsewhere on the board
USB-: IC6.6 (I/O1_2); also elsewhere on the board
VBAT: IC1.2 (VCC), IC2.2 (VCC), IC3.2 (VCC), IC4.2 (VCC), J1.1, J1.5; also elsewhere on the board

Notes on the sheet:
LCD Connector
Flash Chip 1
Microcontroller
Flash Chip 3
Flash Chip 2
Keypad Connector
Flash Chip 4
PB6/HOLD4
USB Port with ESD protection
Fingerprint Sensor Connector

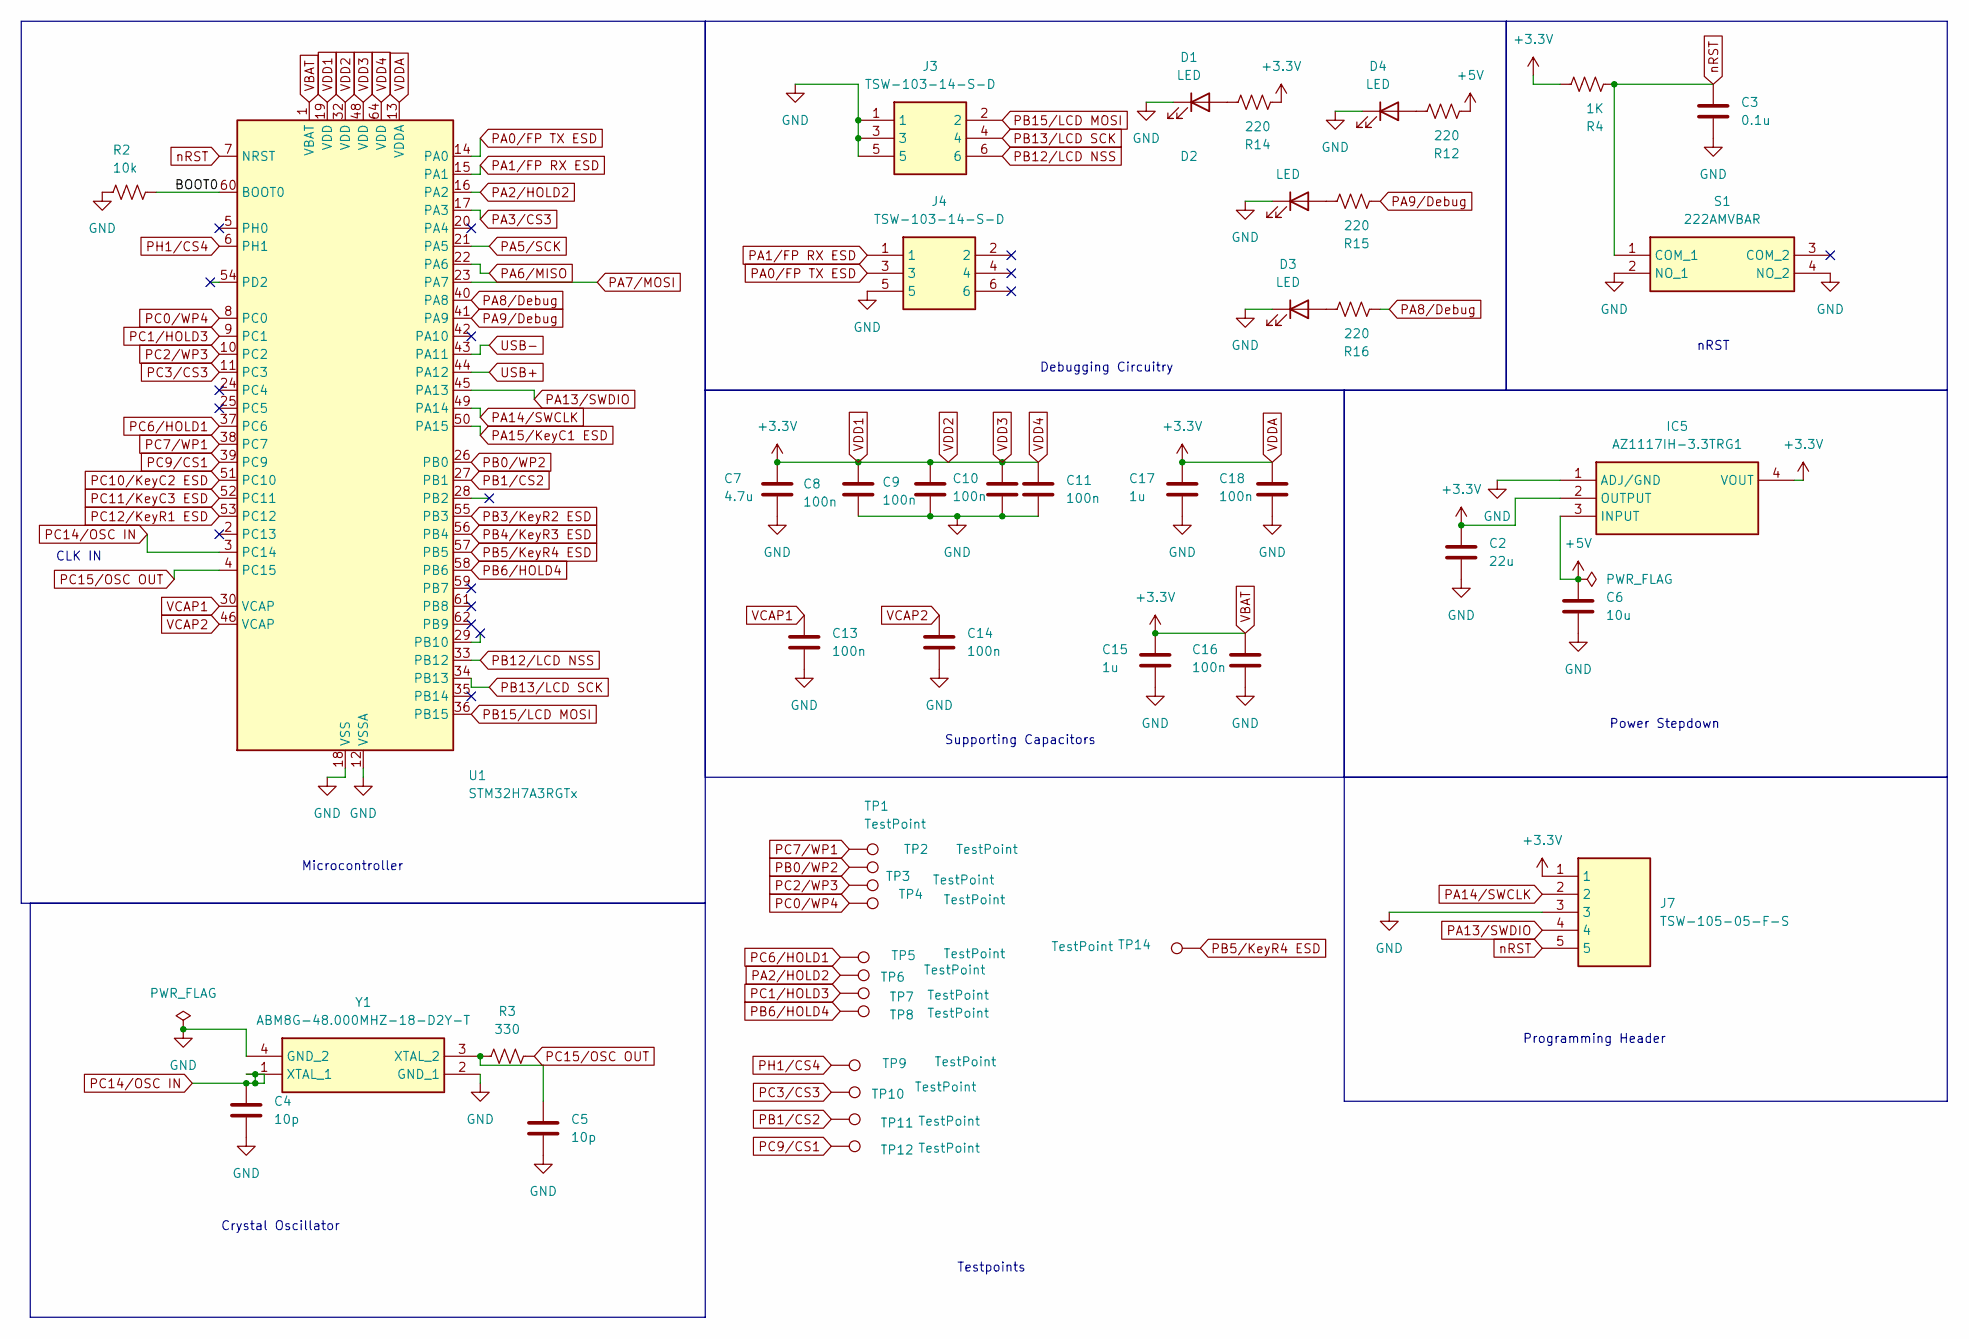
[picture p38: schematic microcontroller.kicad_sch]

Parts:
C2: 22u; C_0805_2012Metric_Pad1.18x1.45mm_HandSolder
C3: 0.1u; C_0805_2012Metric_Pad1.18x1.45mm_HandSolder
C4, C5: 10p; C_0805_2012Metric_Pad1.18x1.45mm_HandSolder
C6: 10u; C_0805_2012Metric_Pad1.18x1.45mm_HandSolder
C7: 4.7u; C_0805_2012Metric_Pad1.18x1.45mm_HandSolder
C8, C9, C10, C11, C13, C14, C16, C18: 100n; C_0805_2012Metric_Pad1.18x1.45mm_HandSolder
C15, C17: 1u; C_0805_2012Metric_Pad1.18x1.45mm_HandSolder
D1, D2, D3, D4: LED; LED_0805_2012Metric_Pad1.15x1.40mm_HandSolder
IC5: AZ1117IH-3.3TRG1; SOT230P700X180-4N; Mouser Part Number 621-AZ1117IH-3.3TRG1
J3, J4: TSW-103-14-S-D; custom1; Mouser Part Number 200-TSW10314SD
J7: TSW-105-05-F-S; TSW-105-XX-YY-S; Mouser Part Number 200-TSW10505FS
R2: 10k; R_0805_2012Metric_Pad1.20x1.40mm_HandSolder
R3: 330; R_0805_2012Metric_Pad1.20x1.40mm_HandSolder
R4: 1K; R_0805_2012Metric_Pad1.20x1.40mm_HandSolder
R12, R14, R15, R16: 220; R_0805_2012Metric_Pad1.20x1.40mm_HandSolder
S1: 222AMVBAR; custom; Mouser Part Number 774-222AMVBAR
TP1, TP2, TP3, TP4, TP5, TP6, TP7, TP8, TP9, TP10, TP11, TP12, TP14: TestPoint; TestPoint_THTPad_D1.0mm_Drill0.5mm
U1: STM32H7A3RGTx; LQFP-64_10x10mm_P0.5mm
Y1: ABM8G-48.000MHZ-18-D2Y-T; ABM8G; Mouser Part Number 815-ABM8G-48-18D2Y

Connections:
+5V: C6.1, IC5.3 (INPUT), R12.2; also elsewhere on the board
/Microcontroller Circuitry/BOOT0: R2.1, U1.60 (BOOT0)
GND: C2.2, C3.2, C4.2, C5.2, C6.2, C7.2, C8.2, C9.2, C10.2, C11.2, C13.2, C14.2, C15.2, C16.2, C17.2, C18.2, D1.1 (K), D2.1 (K), D3.1 (K), D4.1 (K), IC5.1 (ADJ/GND), J3.1, J3.3, J3.5, J4.5, J7.3, R2.2, S1.2 (NO_1), S1.4 (NO_2), U1.12 (VSSA), U1.18 (VSS), U1.31 (VSS), U1.47 (VSS), U1.63 (VSS), Y1.2 (GND_1), Y1.4 (GND_2); also elsewhere on the board
unnamed: D1.2 (A), R14.1
unnamed: D2.2 (A), R15.1
unnamed: D3.2 (A), R16.1
unnamed: D4.2 (A), R12.1
unnamed: C5.1, R3.1, Y1.3 (XTAL_2)
PA0/FP TX ESD: J4.3, U1.14 (PA0); also elsewhere on the board
PA1/FP RX ESD: J4.1, U1.15 (PA1); also elsewhere on the board
PA2/HOLD2: TP6.1, U1.16 (PA2); also elsewhere on the board
PA3/CS3: U1.17 (PA3)
PA5/SCK: U1.21 (PA5); also elsewhere on the board
PA6/MISO: U1.22 (PA6); also elsewhere on the board
PA7/MOSI: U1.23 (PA7); also elsewhere on the board
PA8/Debug: R16.2, U1.40 (PA8)
PA9/Debug: R15.2, U1.41 (PA9)
PA13/SWDIO: J7.4, U1.45 (PA13)
PA14/SWCLK: J7.2, U1.49 (PA14)
PA15/KeyC1 ESD: U1.50 (PA15); also elsewhere on the board
PB0/WP2: TP2.1, U1.26 (PB0); also elsewhere on the board
PB1/CS2: TP11.1, U1.27 (PB1); also elsewhere on the board
PB3/KeyR2 ESD: U1.55 (PB3); also elsewhere on the board
PB4/KeyR3 ESD: U1.56 (PB4); also elsewhere on the board
PB5/KeyR4 ESD: TP14.1, U1.57 (PB5); also elsewhere on the board
PB6/HOLD4: TP8.1, U1.58 (PB6); also elsewhere on the board
PB12/LCD NSS: J3.6, U1.33 (PB12); also elsewhere on the board
PB13/LCD SCK: J3.4, U1.34 (PB13); also elsewhere on the board
PB15/LCD MOSI: J3.2, U1.36 (PB15); also elsewhere on the board
PC0/WP4: TP4.1, U1.8 (PC0); also elsewhere on the board
PC1/HOLD3: TP7.1, U1.9 (PC1); also elsewhere on the board
PC2/WP3: TP3.1, U1.10 (PC2); also elsewhere on the board
PC3/CS3: TP10.1, U1.11 (PC3); also elsewhere on the board
PC6/HOLD1: TP5.1, U1.37 (PC6); also elsewhere on the board
PC7/WP1: TP1.1, U1.38 (PC7); also elsewhere on the board
PC9/CS1: TP12.1, U1.39 (PC9); also elsewhere on the board
PC10/KeyC2 ESD: U1.51 (PC10); also elsewhere on the board
PC11/KeyC3 ESD: U1.52 (PC11); also elsewhere on the board
PC12/KeyR1 ESD: U1.53 (PC12); also elsewhere on the board
PC14/OSC IN: C4.1, U1.3 (PC14), Y1.1 (XTAL_1)
PC15/OSC OUT: R3.2, U1.4 (PC15)
PH1/CS4: TP9.1, U1.6 (PH1); also elsewhere on the board
USB+: U1.44 (PA12); also elsewhere on the board
USB-: U1.43 (PA11); also elsewhere on the board
VBAT: C2.1, C7.1, C8.1, C9.1, C10.1, C11.1, C15.1, C16.1, C17.1, C18.1, IC5.2 (OUTPUT), IC5.4 (VOUT), J7.1, R4.1, R14.2, U1.1 (VBAT), U1.13 (VDDA), U1.19 (VDD), U1.32 (VDD), U1.48 (VDD), U1.64 (VDD); also elsewhere on the board
VCAP1: C13.1, U1.30 (VCAP)
VCAP2: C14.1, U1.46 (VCAP)
nRST: C3.1, J7.5, R4.2, S1.1 (COM_1), U1.7 (NRST)

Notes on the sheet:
Debugging Circuitry
Power Stepdown
Supporting Capacitors
Testpoints
CLK IN
Crystal Oscillator
Microcontroller
Programming Header
nRST

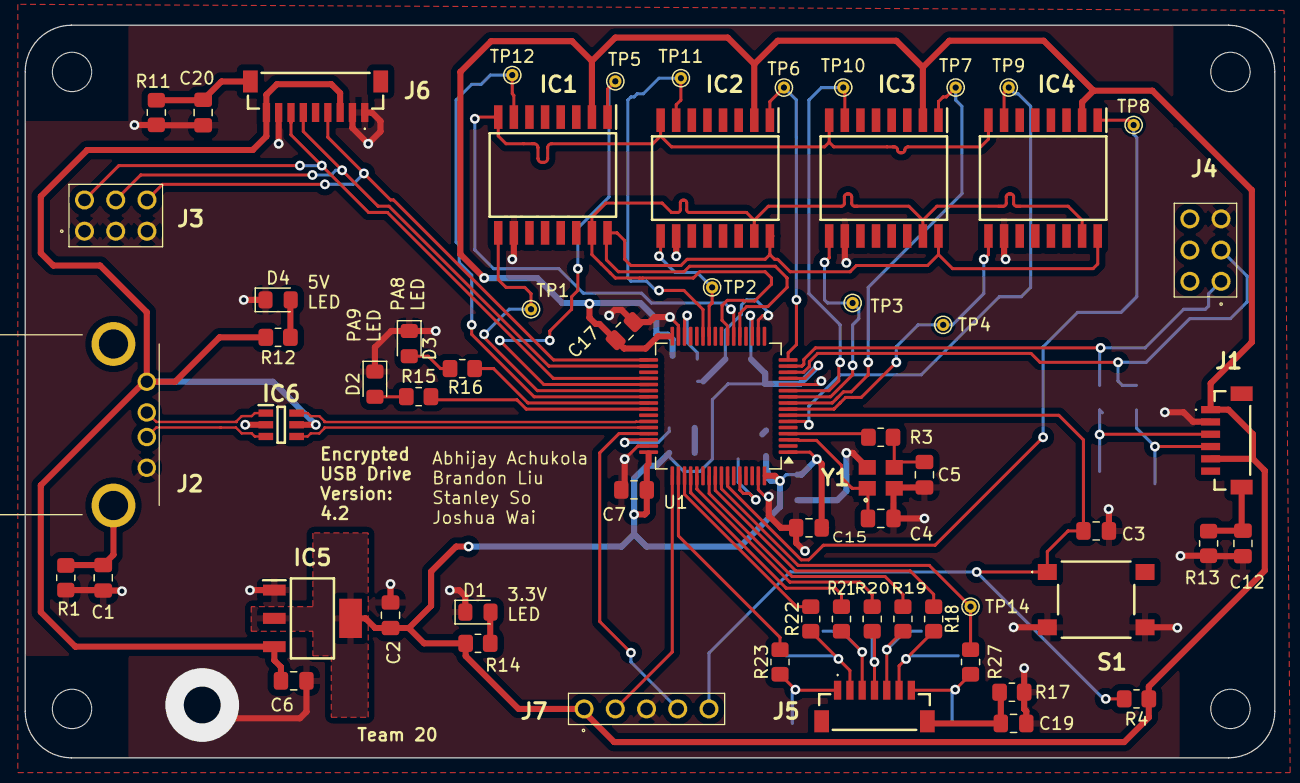
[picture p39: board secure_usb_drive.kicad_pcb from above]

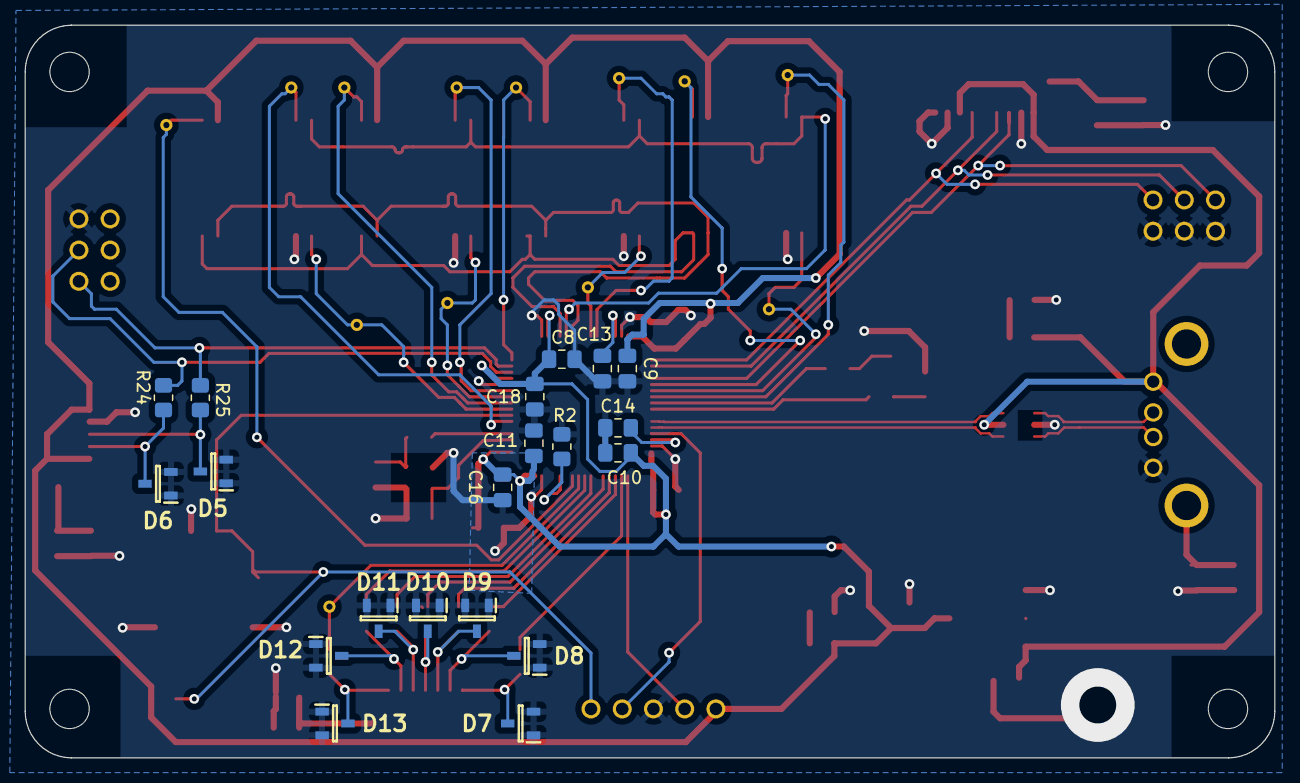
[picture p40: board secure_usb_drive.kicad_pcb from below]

Board: 2 copper layers, 101.7 x 59.6 mm, 86 parts (20 on the bottom side), 62 nets.

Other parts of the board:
H1, H2, H3, H4: MountingHole; MountingHole_3.2mm_M3_DIN965

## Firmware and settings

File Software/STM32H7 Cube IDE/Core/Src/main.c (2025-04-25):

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
/* Includes ------------------------------------------------------------------*/
#include "main.h"
#include "usb_device.h"
#include "usbd_storage_if.h"
#include "usbd_core.h"

/* USER CODE BEGIN Includes */
#include "keypad.h"
#include "lcd.h"
#include "fingerprint_sensor.h"
#include "flash.h"
/* USER CODE END Includes */


SPI_HandleTypeDef hspi1;
SPI_HandleTypeDef hspi2;

TIM_HandleTypeDef htim7;

UART_HandleTypeDef huart4;

/* USER CODE BEGIN PV */
//(update with LCD)

//FLASH GPIOs
const IC_Pin FLASH_P_HOLD_ONE = (IC_Pin){.pin_letter = GPIOC, .pin_num = GPIO_PIN_6};
const IC_Pin FLASH_P_HOLD_TWO = (IC_Pin){.pin_letter = GPIOA, .pin_num = GPIO_PIN_2};
const IC_Pin FLASH_P_HOLD_THREE = (IC_Pin){.pin_letter = GPIOC, .pin_num = GPIO_PIN_1};
const IC_Pin FLASH_P_HOLD_FOUR = (IC_Pin){.pin_letter = GPIOB, .pin_num = GPIO_PIN_6};
const IC_Pin FLASH_P_CS_ONE = (IC_Pin){.pin_letter = GPIOC, .pin_num = GPIO_PIN_9};
const IC_Pin FLASH_P_CS_TWO = (IC_Pin){.pin_letter = GPIOB, .pin_num = GPIO_PIN_1};
const IC_Pin FLASH_P_CS_THREE = (IC_Pin){.pin_letter = GPIOC, .pin_num = GPIO_PIN_3};
const IC_Pin FLASH_P_CS_FOUR = (IC_Pin){.pin_letter = GPIOH, .pin_num = GPIO_PIN_1};
const IC_Pin FLASH_P_WP_ONE = (IC_Pin){.pin_letter = GPIOC, .pin_num = GPIO_PIN_7};
const IC_Pin FLASH_P_WP_TWO = (IC_Pin){.pin_letter = GPIOB, .pin_num = GPIO_PIN_0};
const IC_Pin FLASH_P_WP_THREE = (IC_Pin){.pin_letter = GPIOC, .pin_num = GPIO_PIN_2};
const IC_Pin FLASH_P_WP_FOUR = (IC_Pin){.pin_letter = GPIOC, .pin_num = GPIO_PIN_0};


//KEYPAD GPIOs
const IC_Pin KEY_P_C_ONE = (IC_Pin){.pin_letter = GPIOA, .pin_num = GPIO_PIN_15};
const IC_Pin KEY_P_C_TWO = (IC_Pin){.pin_letter = GPIOC, .pin_num = GPIO_PIN_10};
const IC_Pin KEY_P_C_THREE = (IC_Pin){.pin_letter = GPIOC, .pin_num = GPIO_PIN_11};
const IC_Pin KEY_P_R_ONE = (IC_Pin){.pin_letter = GPIOC, .pin_num = GPIO_PIN_12};
const IC_Pin KEY_P_R_TWO = (IC_Pin){.pin_letter = GPIOB, .pin_num = GPIO_PIN_3};
const IC_Pin KEY_P_R_THREE = (IC_Pin){.pin_letter = GPIOB, .pin_num = GPIO_PIN_4};
const IC_Pin KEY_P_R_FOUR = (IC_Pin){.pin_letter = GPIOB, .pin_num = GPIO_PIN_5};

//LCD GPIOs
const IC_Pin LCD_P_CS = (IC_Pin){.pin_letter = GPIOB, .pin_num = GPIO_PIN_12};

//DEBUG GPIOs
const IC_Pin DEBUG_P_NINE = (IC_Pin){.pin_letter = GPIOA, .pin_num = GPIO_PIN_9};
const IC_Pin DEBUG_P_EIGHT = (IC_Pin){.pin_letter = GPIOA, .pin_num = GPIO_PIN_8};

/* USER CODE END PV */

// STATES
enum State {
	USERSEL,
	RECVPASS,
	PASSWORD,
	FINGERPRINT,
	UNLOCKED,
	CHGPRINT,
	CHGPIN,
	LOCKING
};

struct User {
	int user_id;
	uint8_t password[4];
};

void SystemClock_Config(void);
static void MPU_Config(void);
static void MX_GPIO_Init(void);
static void MX_UART4_Init(void);
static void MX_SPI1_Init(void);
static void MX_SPI2_Init(void);
static void MX_TIM7_Init(void);
/* USER CODE BEGIN 0 */
const struct User default_users[4] = {
		(struct User){.user_id = 1, .password = {0, 0, 0, 0}},
		(struct User){.user_id = 2, .password = {0, 0, 0, 0}},
		(struct User){.user_id = 3, .password = {0, 0, 0, 0}},
		(struct User){.user_id = 4, .password = {0, 0, 0, 0}}
};

struct User users[4];

enum State state;
/* USER CODE END 0 */

/**
  * @brief  The application entry point.
  * @retval int
  */
int main(void)
{

  /* MPU Configuration--------------------------------------------------------*/
  MPU_Config();

  /* MCU Configuration--------------------------------------------------------*/

  /* Reset of all peripherals, Initializes the Flash interface and the Systick. */
  HAL_Init();

  /* Configure the system clock */
  SystemClock_Config();

  /* USER CODE BEGIN SysInit */
  MX_GPIO_Init();
  MX_SPI1_Init();
  uint8_t value;
  Init_Pin();
  flash_init(&hspi1);
  for (int i = 1; i <= 4; i++) {
	  set_flash_chip_num(i);
	  flash_read_status_register(1, &value);
	  flash_write_status_register(1, value & 0b10000111);
	  flash_read_status_register(2, &value);
	  flash_write_status_register(2, value & 0b11110111);
  }

  /* USER CODE END SysInit */

  /* Initialize all configured peripherals */
  MX_UART4_Init();
  MX_SPI2_Init();
  MX_USB_DEVICE_Init();
  MX_TIM7_Init();
  /* USER CODE BEGIN 2 */
  HAL_TIM_Base_Start_IT(&htim7);
  /* USER CODE END 2 */

  /* Infinite loop */
  /* USER CODE BEGIN WHILE */

//  enum State state = UNLOCKED;

  switch_to_usersel();

  load_users_from_flash();

//  struct User users[4] = {user_1, user_2, user_3, user_4};

//  struct User* selected_user = NULL;
//  struct User* selected_user = &user_1;
  struct User* selected_user = &users[0];

  while (1)
  {
    /* USER CODE END WHILE */

    /* USER CODE BEGIN 3 */
	  switch (state) {
          case USERSEL: {
              if (is_key_pressed(0, 0, 1)) { // 1
                  selected_user = &users[0];
                  switch_to_recvpass();
              } else if (is_key_pressed(0, 1, 1)) { // 2
                  selected_user = &users[1];
                  switch_to_recvpass();
              } else if (is_key_pressed(0, 2, 1)) { // 3
                  selected_user = &users[2];
                  switch_to_recvpass();
              } else if (is_key_pressed(1, 0, 1)) { // 4
                  selected_user = &users[3];
                  switch_to_recvpass();
              }
              break;
          }

          case RECVPASS: {
              if (is_key_pressed(3, 1, 1)) { // 0 held for 4 sec
                  switch_to_usersel();
              }
              else if (is_key_pressed(3, 0, 1)) { // star - SELECTED PASSWORD
            	  switch_to_password();
              }
              else if (is_key_pressed(3, 2, 1)) { // pound - SELECTED FINGERPRINT
            	  switch_to_fingerprint();
              }
              break;
          }

          case PASSWORD: {
              int success = 1;
              int count = 0;
              while (count < 4) {
                  char key = '\0';
                  for (int i = 0; i < NUM_ROWS; i++) {
                	  for (int j = 0; j < NUM_COLS; j++) {
                		  if (is_key_pressed(i, j, 5)) {
                			  key = key_to_char(i, j);
                			  Write_Pin(LCD_P_CS, 0);
                			lcd_print(&hspi2, (uint8_t*)"*");
                			  Write_Pin(LCD_P_CS, 1);

                		  }
                	  }
                  }
                  // await key press
                  if (key != '\0' && key != '*' && key != '#') {
                	  if (key != selected_user->password[count] + '0') {
                		  success = 0;
                	  }
                	  count++;
                  }
              }
              if (success) {
            	  // TODO: COPY FLASH DATA TO BUFFER HERE
            	  set_flash_chip_num(selected_user->user_id);
            	  flash_read(buffer, 0, 64);

            	  if (USBD_Start(&hUsbDeviceHS) != USBD_OK)
            	  {
            	      Error_Handler();
            	  }

            	  switch_to_unlocked();
              }
              else {
                  Write_Pin(LCD_P_CS, 0);
                  lcd_clear(&hspi2);
                  lcd_cursor_location(&hspi2, 0x00); // first row of LCD
                  lcd_print(&hspi2, (uint8_t*)"INCORRECT");
                  lcd_cursor_location(&hspi2, 0x40);
                  lcd_print(&hspi2, (uint8_t*)"PASSWORD");
                  Write_Pin(LCD_P_CS, 1);
                  HAL_Delay(2000);

                  switch_to_recvpass();
              }
              break;
          }

          case FINGERPRINT: {
              // send fingerprint match request
              uint8_t ack_type = 9;
              compare_1_1(selected_user->user_id, &ack_type);
              if (ack_type == ACK_SUCCESS) {
            	  // TODO: COPY FLASH DATA TO BUFFER HERE
            	  set_flash_chip_num(selected_user->user_id);
            	  flash_read(buffer, 0, 64);
                  if (USBD_Start(&hUsbDeviceHS) != USBD_OK)
                  {
                	  Error_Handler();
                  }

                  switch_to_unlocked();
              }
              else {
                  Write_Pin(LCD_P_CS, 0);
                  lcd_clear(&hspi2);
                  lcd_cursor_location(&hspi2, 0x00); // first row of LCD
                  lcd_print(&hspi2, (uint8_t*)"INCORRECT");
                  lcd_cursor_location(&hspi2, 0x40);
                  lcd_print(&hspi2, (uint8_t*)"PRINT");
                  Write_Pin(LCD_P_CS, 1);
                  HAL_Delay(2000);

                  switch_to_recvpass();
              }
              break;
          }
              
          case UNLOCKED: {
              if (is_key_pressed(3, 1, 1)) { // 0 pressed
		          switch_to_chgprint();
		      }
		      else if (is_key_pressed(3, 0, 1)) { // * pressed
		          switch_to_chgpin();
		      }
		      else if (is_key_pressed(3, 2, 1)) { // # pressed
		    	  switch_to_locking();
		      }
              break;
          }

          case CHGPRINT: {
		      // ask user for print on fingerprint sensor
		      uint8_t ack_type = 9;
		      delete_specified_user(selected_user->user_id, &ack_type);
		      for (int i = 1; i <= 3; i++) {
		          add_fingerprint(i, selected_user->user_id, 1, &ack_type);
		          if (ack_type != ACK_SUCCESS && ack_type != ACK_NOUSER) {
		        	  Write_Pin(LCD_P_CS, 0);
		        	  lcd_clear(&hspi2);
		        	  lcd_cursor_location(&hspi2, 0x00); // first row of LCD
		        	  lcd_print(&hspi2, (uint8_t*)"BAD READING");
		        	  lcd_cursor_location(&hspi2, 0x40);
		        	  lcd_print(&hspi2, (uint8_t*)"ABORTING");
		        	  Write_Pin(LCD_P_CS, 1);
		        	  HAL_Delay(2000);
		        	  break;
		          }
		      }


		     switch_to_unlocked();
		      break;
          }

          case CHGPIN: {
		      int success = 1;
		      int count = 0;
		      int new_password[4];
		      while (count < 4) {
		          char key = '\0';
		          for (int i = 0; i < NUM_ROWS; i++) {
		        	  for (int j = 0; j < NUM_COLS; j++) {
		        		  if (is_key_pressed(i, j, 1)) {
		        			  key = key_to_char(i, j);
		        		  }
		        	  }
		          }
		          // await key press
		          if (key == '#') { // cancel
		        	  success = 0;
		        	  break;
		          }

		          if (key != '\0') { // password entering
		        	  new_password[count] = key - '0';
		        	  count++;
		          }
		      }

		      // Change the password if it's good
		      if (success) {
		          for (int i = 0; i < 4; i++) {
		        	  selected_user->password[i] = new_password[i];
		        	  users[(selected_user->user_id) - 1].password[i] = new_password[i];
		          }
//		          memcpy(users[(selected_user->user_id) - 1].password, new_password, 4);
		          save_users_to_flash();
		      }

		      switch_to_unlocked();
		      break;
          }

          case LOCKING: {
              if (is_key_pressed(3, 2, 1)) { // # pressed
            	  // TODO: copy and paste buffer to flash IC
            	  set_flash_chip_num(selected_user->user_id);
            	  flash_write(buffer, 0, 64);
            	  if (USBD_Stop(&hUsbDeviceHS) != USBD_OK) {
            	      Error_Handler();
            	  }
		          switch_to_usersel();
		      } else if (is_key_pressed(3, 0, 1)) { // * pressed
		          switch_to_unlocked();
		      }
              break;
          }
	  }
  }
  /* USER CODE END 3 */
}

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
/* USER CODE BEGIN 4 */
//Easy Write pin with the ic_pin type

#define USER_SECTOR_ADDR 0X0817E000
#define USER_SECTOR_NUM  63

void load_users_from_flash(void) {
	// read user0 and user1
	memcpy(&users[0], (void*)USER_SECTOR_ADDR, 16);

	// read user2 and user3
	memcpy(&users[2], (void*)(USER_SECTOR_ADDR + 16), 16);
    if (users[0].user_id != 1 || users[1].user_id != 2 || users[2].user_id != 3  || users[3].user_id != 4) {
        memcpy(users, default_users, sizeof(users));
    }
}

void save_users_to_flash(void) {
    HAL_FLASH_Unlock();

    // erase the sector before writing
    FLASH_EraseInitTypeDef eraseInit;
    eraseInit.TypeErase    = FLASH_TYPEERASE_SECTORS;
    eraseInit.Banks        = FLASH_BANK_2;
    eraseInit.Sector       = USER_SECTOR_NUM;
    eraseInit.NbSectors    = 1;
    uint32_t sectorError = 0;
    HAL_FLASHEx_Erase(&eraseInit, &sectorError);

    uint8_t temp1[16] __attribute__((aligned(16)));
    memset(temp1, 0xFF, 16);
    memcpy(temp1, &users[0], 16); // users[0] and users[1]
    HAL_FLASH_Program(
        FLASH_TYPEPROGRAM_FLASHWORD,
        USER_SECTOR_ADDR,
        (uint32_t)temp1
    );

    uint8_t temp2[16] __attribute__((aligned(16)));
    memset(temp2, 0xFF, 16);
    memcpy(temp2, &users[2], 16); // users[2] and users[3]
    HAL_FLASH_Program(
        FLASH_TYPEPROGRAM_FLASHWORD,
        USER_SECTOR_ADDR + 16,
        (uint32_t)temp2
    );

    HAL_FLASH_Lock();
}

void switch_to_usersel() {
	state = USERSEL;

	Write_Pin(LCD_P_CS, 0);
	lcd_on(&hspi2); // this line
	lcd_light(&hspi2, 0x8); // and this line might only be needed on power up
	lcd_clear(&hspi2);
	lcd_cursor_location(&hspi2, 0x00); // 1st row LCD
	lcd_print(&hspi2, (uint8_t*)"Select User ID");
	lcd_cursor_location(&hspi2, 0x40); // second row of LCD
	lcd_print(&hspi2, (uint8_t*)"1 2 3 4");
	Write_Pin(LCD_P_CS, 1);
}

void switch_to_recvpass() {
	state = RECVPASS;

	Write_Pin(LCD_P_CS, 0);
	lcd_clear(&hspi2);
	lcd_cursor_location(&hspi2, 0x00); // first row of LCD
	lcd_print(&hspi2, (uint8_t*)"SELECT 1 CHOICE");
	lcd_cursor_location(&hspi2, 0x40);
	lcd_print(&hspi2, (uint8_t*)"FP # PASS * BK 0");
	Write_Pin(LCD_P_CS, 1);
}

void switch_to_password() {
	state = PASSWORD;

	Write_Pin(LCD_P_CS, 0);
	lcd_clear(&hspi2);
	lcd_cursor_location(&hspi2, 0x00); // first row of LCD
	lcd_print(&hspi2, (uint8_t*)"ENTER PASSWORD");
	lcd_cursor_location(&hspi2, 0x40);
    Write_Pin(LCD_P_CS, 1);
}

void switch_to_fingerprint() {
	state = FINGERPRINT;

	Write_Pin(LCD_P_CS, 0);
	lcd_clear(&hspi2);
	lcd_cursor_location(&hspi2, 0x00); // first row of LCD
	lcd_print(&hspi2, (uint8_t*)"ENTER FP");
	Write_Pin(LCD_P_CS, 1);
}

void switch_to_unlocked() {
	state = UNLOCKED;

	Write_Pin(LCD_P_CS, 0);
	lcd_clear(&hspi2);
	lcd_cursor_location(&hspi2, 0x00); // first row of LCD
	lcd_print(&hspi2, (uint8_t*)"UNLOCKED");
	lcd_cursor_location(&hspi2, 0x40);
	lcd_print(&hspi2, (uint8_t*)"FP 0 PASS * LK #");
	Write_Pin(LCD_P_CS, 1);
}

void switch_to_chgprint() {
	state = CHGPRINT;

	Write_Pin(LCD_P_CS, 0);
	lcd_clear(&hspi2);
	lcd_cursor_location(&hspi2, 0x00); // first row of LCD
	lcd_print(&hspi2, (uint8_t*)"ENTER PRINT");
	Write_Pin(LCD_P_CS, 1);
//	HAL_Delay(2000);
}

void switch_to_chgpin() {
	state = CHGPIN;

	Write_Pin(LCD_P_CS, 0);
	lcd_clear(&hspi2);
	lcd_cursor_location(&hspi2, 0x00); // first row of LCD
	lcd_print(&hspi2, (uint8_t*)"ENTER PASS");
	lcd_cursor_location(&hspi2, 0x40);
	lcd_print(&hspi2, (uint8_t*)"OR # TO CANCEL");
	Write_Pin(LCD_P_CS, 1);
}

void switch_to_locking() {
	state = LOCKING;

	Write_Pin(LCD_P_CS, 0);
	lcd_clear(&hspi2);
	lcd_cursor_location(&hspi2, 0x00); // first row of LCD
	lcd_print(&hspi2, (uint8_t*)"LOCK & SAVE?");
	lcd_cursor_location(&hspi2, 0x40);
	lcd_print(&hspi2, (uint8_t*)"Y:# N:*");
	Write_Pin(LCD_P_CS, 1);
}

void Write_Pin(IC_Pin pin, int value)
{
	if (value == 0) {
		HAL_GPIO_WritePin(pin.pin_letter, pin.pin_num, GPIO_PIN_RESET);
	}
	else {
		HAL_GPIO_WritePin(pin.pin_letter, pin.pin_num, GPIO_PIN_SET);
	}

}

int Read_Pin(IC_Pin pin)
{
	GPIO_PinState value = HAL_GPIO_ReadPin(pin.pin_letter, pin.pin_num);

	if (value == GPIO_PIN_SET){
		return 1;
	}
	return 0;
}

//Initialize pins to "default value" (update with LCD)
void Init_Pin() {
	Write_Pin(FLASH_P_WP_ONE, 1);
	Write_Pin(FLASH_P_WP_TWO, 1);
	Write_Pin(FLASH_P_WP_THREE, 1);
	Write_Pin(FLASH_P_WP_FOUR, 1);
	Write_Pin(FLASH_P_CS_ONE, 1);
	Write_Pin(FLASH_P_CS_TWO, 1);
	Write_Pin(FLASH_P_CS_THREE, 1);
	Write_Pin(FLASH_P_CS_FOUR, 1);
	Write_Pin(FLASH_P_HOLD_ONE, 1);
	Write_Pin(FLASH_P_HOLD_TWO, 1);
	Write_Pin(FLASH_P_HOLD_THREE, 1);
	Write_Pin(FLASH_P_HOLD_FOUR, 1);
	Write_Pin(DEBUG_P_EIGHT, 0);
	Write_Pin(DEBUG_P_NINE, 0);
}
/* USER CODE END 4 */

 /* MPU Configuration */

void MPU_Config(void)
{
  MPU_Region_InitTypeDef MPU_InitStruct = {0};

  /* Disables the MPU */
  HAL_MPU_Disable();

  /** Initializes and configures the Region and the memory to be protected
  */
  MPU_InitStruct.Enable = MPU_REGION_ENABLE;
  MPU_InitStruct.Number = MPU_REGION_NUMBER0;
  MPU_InitStruct.BaseAddress = 0x0;
  MPU_InitStruct.Size = MPU_REGION_SIZE_4GB;
  MPU_InitStruct.SubRegionDisable = 0x87;
  MPU_InitStruct.TypeExtField = MPU_TEX_LEVEL0;
  MPU_InitStruct.AccessPermission = MPU_REGION_NO_ACCESS;
  MPU_InitStruct.DisableExec = MPU_INSTRUCTION_ACCESS_DISABLE;
  MPU_InitStruct.IsShareable = MPU_ACCESS_SHAREABLE;
  MPU_InitStruct.IsCacheable = MPU_ACCESS_NOT_CACHEABLE;
  MPU_InitStruct.IsBufferable = MPU_ACCESS_NOT_BUFFERABLE;

  HAL_MPU_ConfigRegion(&MPU_InitStruct);
  /* Enables the MPU */
  HAL_MPU_Enable(MPU_PRIVILEGED_DEFAULT);

}

/**
  * @brief  This function is executed in case of error occurrence.
  * @retval None
  */
void Error_Handler(void)
{
  /* USER CODE BEGIN Error_Handler_Debug */
  /* User can add his own implementation to report the HAL error return state */
  __disable_irq();
  while (1)
  {
  }
  /* USER CODE END Error_Handler_Debug */
}

#ifdef  USE_FULL_ASSERT
/**
  * @brief  Reports the name of the source file and the source line number
  *         where the assert_param error has occurred.
  * @param  file: pointer to the source file name
  * @param  line: assert_param error line source number
  * @retval None
  */
void assert_failed(uint8_t *file, uint32_t line)
{
  /* USER CODE BEGIN 6 */
  /* User can add his own implementation to report the file name and line number,
     ex: printf("Wrong parameters value: file %s on line %d\r\n", file, line) */
  /* USER CODE END 6 */
}
#endif /* USE_FULL_ASSERT */

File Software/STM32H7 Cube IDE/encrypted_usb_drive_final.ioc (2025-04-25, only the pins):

Mcu.UserName=STM32H7A3RGTx
PA0.Signal=UART4_TX
PA1.Signal=UART4_RX
PA11.Signal=USB_OTG_HS_DM
PA12.Signal=USB_OTG_HS_DP
PA13.Signal=DEBUG_JTMS-SWDIO
PA14.Signal=DEBUG_JTCK-SWCLK
PA15.Signal=GPIO_Input
PA2.Signal=GPIO_Output
PA3.Signal=GPIO_Output
PA5.Signal=SPI1_SCK
PA6.Signal=SPI1_MISO
PA7.Signal=SPI1_MOSI
PA8.Signal=GPIO_Output
PA9.Signal=GPIO_Output
PB0.Signal=GPIO_Output
PB1.Signal=GPIO_Output
PB12.Signal=GPIO_Output
PB13.Signal=SPI2_SCK
PB15.Signal=SPI2_MOSI
PB3.Signal=GPIO_Output
PB4.Signal=GPIO_Output
PB5.Signal=GPIO_Output
PB6.Signal=GPIO_Output
PC0.Signal=GPIO_Output
PC1.Signal=GPIO_Output
PC10.Signal=GPIO_Input
PC11.Signal=GPIO_Input
PC12.Signal=GPIO_Output
PC2.Signal=GPIO_Output
PC3.Signal=GPIO_Output
PC6.Signal=GPIO_Output
PC7.Signal=GPIO_Output
PC9.Signal=GPIO_Output
PH1-OSC_OUT.Signal=GPIO_Output

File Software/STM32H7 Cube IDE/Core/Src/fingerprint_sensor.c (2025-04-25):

/*
 * fingerprint_sensor.c
 *
 *  Created on: Feb 18, 2025
 *      Author: chaos
 */

#include "fingerprint_sensor.h"
#include "main.h"

#define PACKET_SIZE 8 // This file only supports sending / receiving 8 byte packets

// Calculates the checksum that is sent as the 7th byte of the UART packet
static uint16_t calculate_checksum(const uint8_t buff[]) {
	return buff[1] ^ buff[2] ^ buff[3] ^ buff[4] ^ buff[5];
}

// Generates an 8 byte package and stores it inside buff (see page 3 of the datasheet).
static void generate_package(
	uint8_t buff[],
	const uint8_t cmd,
	const uint8_t p1, const uint8_t p2, const uint8_t p3
) {
	buff[0] = 0xF5;
	buff[1] = cmd;
	buff[2] = p1;
	buff[3] = p2;
	buff[4] = p3;
	buff[5] = 0;
	buff[6] = calculate_checksum(buff);
	buff[7] = 0xF5;
}

// Sends an 8 byte command to the fingerprint sensor.
// Returns FINGERPRINT_OK or the type of error
static Fingerprint_Status send_command(
	const uint8_t cmd,
	const uint8_t p1, const uint8_t p2, const uint8_t p3
) {
	// Generate tx_buff
	uint8_t tx_buff[PACKET_SIZE];
	generate_package(tx_buff, cmd, p1, p2, p3);

	// Transmit tx_buff
	const HAL_StatusTypeDef tx_result
		= HAL_UART_Transmit(&huart4, tx_buff, PACKET_SIZE, 100000);
	return tx_result != HAL_OK ? FINGERPRINT_HAL_ERROR : FINGERPRINT_OK;
}

// Receives an 8 byte acknowledgment packet from the fingerprint sensor, and
// stores the return values into the q1, q2, and q3 return parameters.
// Returns FINGERPRINT_OK or the type of error
static Fingerprint_Status receive_acknowledgment(
	const uint32_t rx_timeout,
	const uint8_t cmd,
	uint8_t* q1, uint8_t* q2, uint8_t* q3
) {
	// Receive UART data and put it in rx_buff
	uint8_t rx_buff[PACKET_SIZE];
	const HAL_StatusTypeDef rx_result
		= HAL_UART_Receive(&huart4, rx_buff, PACKET_SIZE, rx_timeout);
	if (rx_result != HAL_OK) {
		return FINGERPRINT_HAL_ERROR;
	}

	// Generate the expected result
	uint8_t exp_rx_buff[PACKET_SIZE];
	// I don't know what I expect to get for q1, q2, and q3, so I set them all to 0.
	generate_package(exp_rx_buff, cmd, 0, 0, 0);

	// Check the UART data against the expected result
	// Check the first, last, cmd, and zero bytes
	if (
		exp_rx_buff[0] != rx_buff[0]
		|| exp_rx_buff[1] != rx_buff[1]
		|| exp_rx_buff[5] != rx_buff[5]
		|| exp_rx_buff[7] != rx_buff[7]
	) {
		return FINGERPRINT_RX_ERROR;
	}

	// Check the checksum
	if (rx_buff[6] != calculate_checksum(rx_buff)) {
		return FINGERPRINT_RX_ERROR;
	}

	// If the code gets to here then all the checks have passed,
	// so we can set q1, q2, and q3 accordingly.
	if (q1 != NULL) {
		*q1 = rx_buff[2];
	}
	if (q2 != NULL) {
		*q2 = rx_buff[3];
	}
	if (q3 != NULL) {
		*q3 = rx_buff[4];
	}

	return FINGERPRINT_OK;
}

// Sends an 8 byte command to the fingerprint sensor.
// Then receives an 8 byte acknowledgment packet from the
// fingerprint sensor and sets q1, q2, and q3 accordingly.
// Returns FINGERPRINT_OK or the type of error
static Fingerprint_Status send_and_receive_command(
	const uint32_t rx_timeout,
	const uint8_t cmd,
	const uint8_t p1, const uint8_t p2, const uint8_t p3,
	uint8_t* q1, uint8_t* q2, uint8_t* q3
) {
	Fingerprint_Status tx_result = send_command(cmd, p1, p2, p3);
	if (tx_result != FINGERPRINT_OK) {
		return tx_result;
	}

	return receive_acknowledgment(rx_timeout, cmd, q1, q2, q3);
}

// Sends the delete specified user (2.4) command in the datasheet.
// ack_type is called q3 in the datasheet.
Fingerprint_Status delete_specified_user(uint16_t user_id, uint8_t* ack_type) {
	return send_and_receive_command(
		1000,
		0x04,
		(uint8_t)(user_id >> 8), (uint8_t)user_id, 0,
		NULL, NULL, ack_type
	);
}

// Sends the compare 1:1 (2.7) command in the datasheet.
// ack_type is called q3 in the datasheet.
Fingerprint_Status compare_1_1(uint16_t user_id, uint8_t* ack_type) {
	return send_and_receive_command(
		20000,
		0x0B,
		(uint8_t)(user_id >> 8), (uint8_t)user_id, 0,
		NULL, NULL, ack_type
	);
}

// Sends the add_fingerprint (2.7) command in the datasheet.
// press_num is 1 if it's the first fingerprint input,
// 2 if it's the second fingerprint input, and 3 if it's the third fingerprint input.
// ack_type is called q3 in the datasheet.
Fingerprint_Status add_fingerprint(
	unsigned int press_num,
	uint16_t user_id, uint8_t user_privilege,
	uint8_t* ack_type
) {
	if (press_num < 1 || press_num > 3) {
		return FINGERPRINT_INVALID_PARAM;
	}
	return send_and_receive_command(
		20000,
		press_num,
		(uint8_t)(user_id >> 8), (uint8_t)user_id, user_privilege,
		NULL, NULL, ack_type
	);
}

// Sends the set fingerprint capture timeout value (2.25)
// command in the datasheet. It doesn't read the timeout value.
// ack_type is called q3 in the datasheet.
Fingerprint_Status set_timeout(uint8_t timeout_value, uint8_t* ack_type) {
	return send_and_receive_command(
		1000,
		0x2E,
		0, timeout_value, 0,
		NULL, NULL, ack_type
	);
}

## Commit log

2025-01-30 Added kicad files
    [477.kicad_pcb, 477.kicad_sch]
2025-01-31 finished first draft of schematic
    [477.kicad_sch]
2025-02-12 checking kicad files
    [477.kicad_sch]
2025-02-14 brought in stmf4xx hal driver for coding and spi testing
2025-02-15 started on flash ic functionality and reset command.
    [flash.c, main.c]
2025-02-18 MCU can communicate via SPI as the master - verified using oscilloscope
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2025-02-19 finished pcb draft
    [477.kicad_pcb, 477.kicad_sch]
2025-02-19 wrote all fingerprint sensor TX code
2025-02-19 tweaked schematic
    [477.kicad_pcb, 477.kicad_sch]
2025-02-25 disabled UART NVIC interrupt
2025-02-26 tweaked diagram and pin out setup.
    [477.kicad_pcb, 477.kicad_sch]
2025-02-26 updated schematic
    [477.kicad_pcb, 477.kicad_sch]
2025-02-26 commiting pcb changes
    [477.kicad_pcb]
2025-02-28 added button and tweaked silkscreen
    [477.kicad_pcb, 477.kicad_sch]
2025-02-28 tweaked pcb and schematics with micro power wiring and debugging additions
    [477.kicad_pcb, 477.kicad_sch, microcontroller.kicad_sch]
2025-02-28 committing some unsaved changes
    [477.kicad_pcb]
2025-02-28 tweaked schematic to pass erc
    [477.kicad_sch, microcontroller.kicad_sch]
2025-03-01 added additional connector
    [477.kicad_pcb, 477.kicad_sch, microcontroller.kicad_sch]
2025-03-01 modified silkscreen
    [477.kicad_pcb]
2025-03-01 found final connector
    [477.kicad_pcb, 477.kicad_sch, microcontroller.kicad_sch]
2025-03-01 finalized schematic
    [477.kicad_pcb, 477.kicad_sch, microcontroller.kicad_sch]
2025-03-02 modified mounting holes
    [477.kicad_pcb, 477.kicad_sch]
2025-03-02 updated with 3d models
    [477.kicad_pcb, 477.kicad_sch]
2025-03-03 added testing points
    [477.kicad_pcb, 477.kicad_sch, microcontroller.kicad_sch]
2025-03-05 routed essential signals
    [477.kicad_pcb, 477.kicad_sch, microcontroller.kicad_sch]
2025-03-05 Changed the code to the waveshare sensor
2025-03-05 finished file
    [477.kicad_pcb, 477.kicad_sch, microcontroller.kicad_sch]
2025-03-06 Finalized Signal Routing
    [477.kicad_pcb, 477.kicad_sch, microcontroller.kicad_sch]
2025-03-06 finalized 99% of pcb
    [477.kicad_pcb, microcontroller.kicad_sch]
2025-03-07 updated files with 3d models
    [222AMVBAR.stp, 477.kicad_pcb, 477.kicad_sch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]
2025-03-07 finished schematic and pcb
    [477.kicad_pcb]
2025-03-07 rounded edges
    [477.kicad_pcb]
2025-03-07 updated pcb
    [477.kicad_pcb]
2025-03-07 rectangularized the pcb design.
    [477.kicad_pcb]
2025-03-12 made most of the easy changes for the pcb
    [477.kicad_pcb, microcontroller.kicad_sch]
2025-03-12 cleaned up a bit of routing
    [477.kicad_pcb]
2025-03-12 finalized pcb design (miso line is still cooked but better)
    finished up most of the pcb design work, need to check if we can route spi signals under the flash ic (or is it smth we look up in datasheet)?
    [477.kicad_pcb, microcontroller.kicad_sch]
2025-03-12 refilled ground plane to update to changes.
    [477.kicad_pcb]
2025-03-12 okay final commit this time (gnd plane maximization)
    [477.kicad_pcb]
2025-03-12 nvm added ground via to pass drc
    [477.kicad_pcb]
2025-03-12 rerouted miso signals + minimized vias from top side by using test points as vias.
    [477.kicad_pcb]
2025-03-12 brought power from outer layer to top layer
    [477.kicad_pcb]
2025-03-12 fixed led acute angle traces
    [477.kicad_pcb]
2025-03-12 tweaked silkscreen
    [477.kicad_pcb]
2025-03-12 fixed weird routing
    [477.kicad_pcb]
2025-03-12 made VBAT pad bigger
    hi Joshua
    [477.kicad_pcb, microcontroller.kicad_sch]
2025-03-12 added big ground pad that we can clip oscilloscope to
    [477.kicad_pcb]
2025-03-14 added esd changes to schematic and pcb, mainly for J1 and J5, no DRC run
    [477.kicad_pcb, 477.kicad_sch, microcontroller.kicad_sch]
2025-03-14 Finished with changes to fix electric issues.
    power lines need to be relooked at
    [477.kicad_pcb]
2025-03-14 rerouted keypad
    [477.kicad_pcb, 477.kicad_sch]
2025-03-14 finished PCB
    [477.kicad_pcb]
2025-03-15 made a few tweaks based on setsuna's comments
    [477.kicad_pcb]
2025-03-16 fixed DRC violation by connecting VBAT for C16
    [477.kicad_pcb]
2025-03-16 previous edits may not be reflected, but they are now + no copper around oscillator
    [477.kicad_pcb]
2025-03-16 added exclusion zone around oscillator
    [477.kicad_pcb]
2025-03-16 recommitting, previous change may not be reflected
    [477.kicad_pcb]
2025-03-16 added more exclusion zones around mounting holes
    [477.kicad_pcb]
2025-03-16 recommitting because exclusion zone edits may not be saved
    [477.kicad_pcb]
2025-03-16 added one giant ground plane on front and back and allowed stanley's VBAT zone to have higher priority to avoid DRC issues
    [477.kicad_pcb]
2025-03-16 added pullup for nrst and fixed drc warnings for silkscreen
    [477.kicad_pcb, microcontroller.kicad_sch]
2025-03-18 uploaded tvs diode footprint and symbol
    [477.kicad_sch, D5V0L2B3SO-7.stp]
2025-03-18 fixed one acute angle and drc issue with ground plane on top layer
    [477.kicad_pcb]
2025-03-18 changed ESD diode in schematic
    [477.kicad_sch]
2025-03-18 Routed new ESD diode
    [477.kicad_pcb]
2025-03-18 created fabrication outputs
    [477-B_Cu.gbl, 477-B_Mask.gbs, 477-B_Paste.gbp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]
2025-03-24 tweaked 3d model characteristics to include diodes in 3d model
    [477.kicad_pcb]
2025-04-07 updated with current flash ic prototyping
2025-04-08 fixed reset issue and added lcd ic pin
    [encrypted_usb_drive_final.ioc, main.c]
2025-04-15 added read pin functionality
2025-04-16 updated keypad schematic
    rendered testpoint useless, but keypad should not require much use of test points.
    [477.kicad_pcb, 477.kicad_sch, microcontroller.kicad_sch]
2025-04-18 got basic USB communication to work, can send capacities but cannot store values once powered off in buffer
2025-04-24 changed to 512 sector size and ran into flash write errors
    [encrypted_usb_drive_final.ioc, flash.c, main.c]
2025-04-24 I wrote some code to turn on LEDs
    for Brandon
2025-04-25 worked on state machine.
    List of things that don't work:
    - no distinct users (everyone shares the same keypad password)
    - changing fingerprint doesn't work
    [encrypted_usb_drive_final.ioc, fingerprint_sensor.c, lcd.c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]
2025-04-25 Fixed fingerprint
2025-05-03 updated format and uploaded documents
    [222AMVBAR.stp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]

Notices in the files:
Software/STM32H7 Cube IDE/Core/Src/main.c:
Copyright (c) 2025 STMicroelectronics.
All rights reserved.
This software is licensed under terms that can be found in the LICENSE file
